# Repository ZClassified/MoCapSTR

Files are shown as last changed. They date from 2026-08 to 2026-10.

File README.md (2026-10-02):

# MoCapSTR: Sync / Trigger / Record for FreeMoCap










> [!CAUTION]
> ### ⚠️ Project Status: Experimental Prototype / Work in Progress
> **Please Note:** This project is currently undergoing active development and testing. It is **NOT YET in a state where it can be easily replicated as a turnkey / plug-and-play solution**. Hardware-level camera synchronization involves specific driver, USB controller bandwidth, and timing considerations. You may encounter issues depending on your hardware environment. Follow the issue tracker or discussions for ongoing updates.

> **Disclaimer:** MoCapSTR is an independent open-source companion tool and is not officially affiliated with the FreeMoCap project.

MoCapSTR is an open-source multi-camera recording tool designed to capture frame-accurate, hardware-synchronized video datasets for [FreeMoCap](https://github.com/freemocap/freemocap). It synchronizes global-shutter USB cameras (e.g. Innomaker OV9281, tested up to 50 FPS hardware-synced / 120 FPS free-run) via an Arduino trigger signal. Support for Blackmagic SDI capture cards is planned (see below).

> [!WARNING]
> **Blackmagic SDI mode is currently broken.** The "Blackmagic SDI" workflow in the Setup tab does not work since the switch to the PyAV backend. Its restoration (uncompressed or GPU-encoded recording, interlace/PsF detection, frame alignment without trigger) is planned for v2.0, once the webcam + Arduino base runs stable – see [BLACKMAGIC_SDI_PLAN.md](BLACKMAGIC_SDI_PLAN.md) (German).

---

## The Hardware Sync Challenge (USB Bandwidth)

Hardware-level synchronization has fundamentally different USB bandwidth requirements than standard webcam setups:

- **Free-Running Cameras (Standard Webcams / Standard FreeMoCap):** Cameras run on independent internal clocks. Their frames arrive staggered across time, so the data stream is naturally distributed.
- **Hardware-Triggered Mode (MoCapSTR):** An Arduino fires a 5V square-wave pulse to all cameras simultaneously. All connected cameras expose and push raw frame packets at the **exact same microsecond**.

### The Motherboard Bottleneck & Recommended Setup
Most standard PC motherboards share only 1 or 2 USB host controllers across all external USB ports:
- **Motherboard Limits:** In our testing, standard onboard USB controllers reliably handle a **maximum of 3 cameras** in hardware-trigger mode before bandwidth saturation causes dropped frames.
- **Recommended for 4+ Cameras (Verified Hardware):** We strongly recommend using a **PCIe USB expansion card with dedicated host controllers per port** (e.g. 4 separate USB controller chips on a single PCIe card) to ensure unconstrained bandwidth for all cameras.
  - **Tested & Verified Model:** **StarTech 4-Port USB 3.0 PCIe Card (Model: `P5Q4A-USB-CARD`)** — features 4 independent controller channels, reliably streaming 4 InnoMaker OV9281 cameras simultaneously without frame drops.
- **Smart USB Polling Rate:** In the Setup tab, `USB Polling` defaults to **`Auto`**. In Hardware Trigger mode, `Auto` requests a 120 FPS UVC stream to eliminate beat-frequency host polling jitter, while in Free-Run mode it matches your target FPS.

### InnoMaker OV9281 Hardware Trigger Characterization (Max 50 FPS)
Extensive empirical benchmark sweeping has characterized the InnoMaker OV9281 USB camera in hardware-trigger mode:
- **Free-Run Mode:** The camera sensor streams up to **120 FPS** (1280x720 / 1280x800 MJPG) via continuous internal pipelining.
- **Hardware-Trigger Mode:** The on-board USB bridge ISP firmware operates with a fixed non-overlapping state machine lockout window of **$\approx 18\text{–}20\text{ ms}$** per frame (regardless of resolution).
- **Physical Hardware Ceiling:** As a result, the physical hardware ceiling in trigger mode is strictly **50 FPS** (20 ms frame period). Triggering faster than 50 Hz causes the firmware to reject subsequent pulses, producing exact harmonic sub-rates (60 Hz $\rightarrow$ 30 FPS, 90 Hz $\rightarrow$ 45 FPS, 120 Hz $\rightarrow$ 40 FPS).
- **Optimal Setting for Motion Capture:** **1280x720 (720p HD) @ 50 FPS** with **`Auto` USB Polling** and **Exposure `-9` / `-10`** (~1–2 ms shutter). This delivers 200 frame-accurate, global-shutter synchronized images per second across 4 cameras without motion blur or frame drops.

<p align="center">
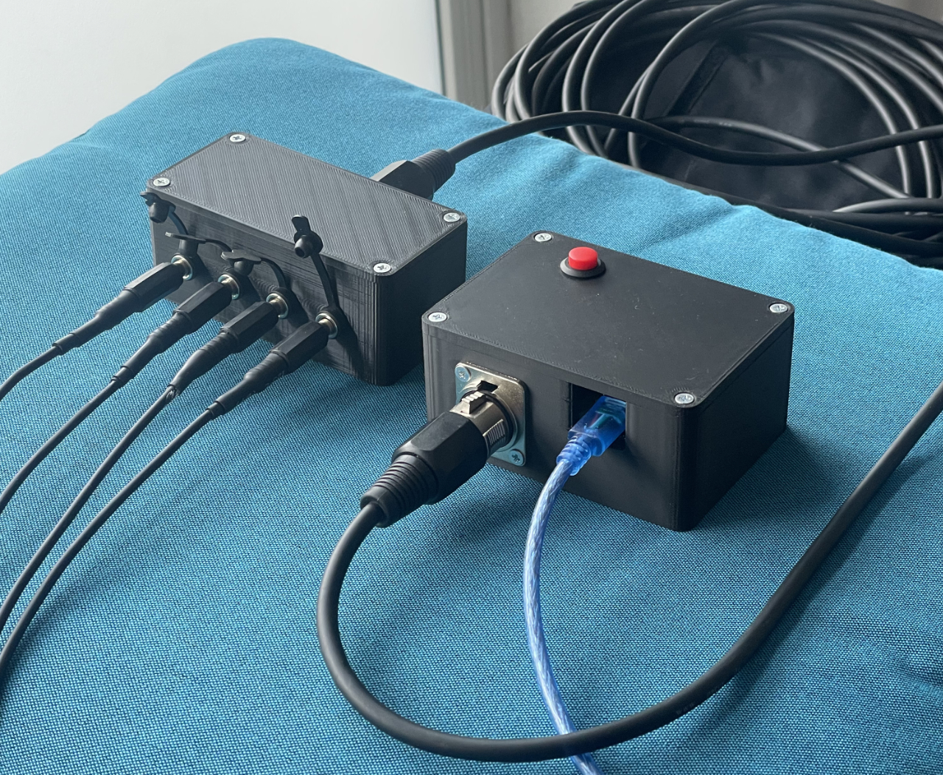
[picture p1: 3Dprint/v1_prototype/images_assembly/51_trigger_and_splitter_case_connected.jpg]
MoCapSTR Hardware Setup
  
  <br>
  <em>Arduino Trigger Box (with Start/Stop button) connected via XLR cable to the Splitter Box.</em>
</p>

---

## Features

- **Hardware Camera Synchronization:** Synchronous frame capture across all OV9281 cameras via Arduino FSIN pin (with auto-fallback to free-run mode if disconnected).
- **Zero-Copy PyAV Backend:** Writes raw MJPEG streams directly to disk via FFmpeg/PyAV without CPU decoding, minimizing frame drops.
- **Live Preview & Charuco Calibration:** Multi-camera live view with per-camera rotation (0°, 90°, 180°, 270°) and live `cv2.aruco` Charuco board detection overlay.
- **Records straight into FreeMoCap 2:** Every take and calibration is saved as its own recording in FreeMoCap's `recordings/` folder (`synchronized_videos/` + timestamps), with identical frame counts on all cameras. FreeMoCap 2 picks up the real frame rate from the timestamps.
- **Built-in Offline Converter:** Optional conversion of raw `.avi`/`.mkv` recordings into H.264 (`.mp4`) with per-camera rotation. FreeMoCap 2 also reads the raw files directly.
- **Hardware Diagnostics:** Built-in Camera Test tab to scan connected cameras for supported resolutions, framerates, and pixel formats.

---

## Quick Hardware Overview

1. **Wiring:**
   - Connect Arduino **GND** -> **GND** of all cameras.
   - Connect Arduino **Pin 2** -> **FSIN (Frame Sync In)** of all cameras.
   - *(Optional)* Connect physical Start/Stop push-button between Arduino **Pin 4** and **GND**.
2. **Guides & 3D Models:**
   - 3D printable files, fastener BOM, and step-by-step photo guide: [3Dprint & Assembly Guide](3Dprint/README.md).
   - Detailed wiring guide and splitter box schematic: [HARDWARE_SETUP.md](HARDWARE_SETUP.md).
   - Camera sensor specifications: [CAMERA_SPECS.md](CAMERA_SPECS.md).

---

## Installation

> **Pre-built Executable:** A ready-to-run `.exe` is available under [Releases](https://github.com/ZClassified/MoCapSTR/releases).

### Running from Source
- **Requirements:** Python 3.10+ (and [Blackmagic Desktop Video Drivers](https://www.blackmagicdesign.com/support/) for the planned SDI mode).

```bash
git clone https://github.com/ZClassified/MoCapSTR.git
cd MoCapSTR
pip install -r requirements.txt
python python/main.py
```
**Arduino firmware:** Connect the Arduino Nano/Uno, select its port in the Setup tab and click **Firmware aufspielen** – no Arduino IDE needed. The button turns orange when the firmware is missing or outdated (e.g. after updating MoCapSTR).
*(Alternatively flash `arduino/trigger_firmware/trigger_firmware.ino` with the Arduino IDE. After changing the sketch, rebuild the bundled HEX with `python arduino/build_firmware.py`.)*

**Running the tests** (no hardware needed; `pip install pandas` additionally enables the FreeMoCap compatibility test):
```bash
python -m unittest discover tests
```

**Settings & log files:** Settings, presets and the last session are stored in `%APPDATA%\MoCapSTR`. The log file is `%LOCALAPPDATA%\MoCapSTR\logs\mocapstr.log` – use **Log-Ordner öffnen** in the log panel and attach it to bug reports.

---

## Recording Workflow

1. **Setup Tab:** Choose a project name. Recordings are saved to FreeMoCap's recordings folder (`~/freemocap_data/recordings`, or the data folder chosen in FreeMoCap's settings). Select resolution, target FPS, and the Arduino COM port. Click **Initialize System & Start Preview**.
2. **Live Preview Tab:** Verify all camera feeds and rotations. Enable **Show Calibration (Auto-Detect)** when recording a Charuco calibration take.
3. **Record:** Start/Stop recording via the UI button or the physical button on the trigger box.
4. **Export & Convert Tab (optional):** Convert raw takes to H.264 (`.mp4`), e.g. to apply camera rotation. Originals are moved to `original_videos/` so FreeMoCap sees exactly one video per camera.
5. **FreeMoCap 2:** Click **Open in FreeMoCap** (or start FreeMoCap yourself). Recordings are named `<date>_<time>_<project>_<take>`; calibration recordings end in `_calibration`.

---

## Troubleshooting & FAQ

### Camera shows `0.0 FPS` or a Frozen Image (`⚠️ NO SIGNAL / FROZEN`)
- **Symptom:** When clicking "Initialize System", one or more camera feeds show an initial frame and immediately freeze at `0.0 FPS` with a red warning overlay.
- **Root Cause:** The camera has switched to Hardware Trigger mode (`AutoFocus=1`) and is waiting for electrical pulses on its `FSIN` pin. If no trigger pulse or ground reaches the camera, the sensor produces zero further frames.
- **Step-by-Step Diagnostic:**
  1. **Quick Software Isolation (Free-Run Test):** In the **Setup** tab, uncheck `Enable UVC Hardware Trigger` and click **Initialize System**. If all cameras stream smoothly at 30/60 FPS in Free-Run mode, your USB card, bandwidth, and software are 100% working — the issue is **strictly the physical hardware trigger connection**.
  2. **Check Splitter Box Wiring:** Open the splitter box and ensure all WAGO cage clamp terminals and DC jack solder joints are firm and not disconnected.
  3. **Check `FSIN+` / `FSIN-` Polarity:** Ensure the 2-pin plug on the camera PCB is oriented correctly (Red = `FSIN+`, Black = `FSIN-` / Ground). If polarity is reversed, the camera's internal diode blocks the trigger pulses.
  4. **Cross-Test Cables:** Swap the DC barrel jack of the frozen camera with a working camera at the splitter box to isolate whether the cable or splitter port is faulty.

---

## License

GPL-3.0 License. See [LICENSE](LICENSE) for details.

---
---

# Deutsche Version

> **Hinweis:** MoCapSTR ist ein unabhängiges Open-Source Companion-Tool und steht nicht in offizieller Verbindung mit dem FreeMoCap-Projekt.

MoCapSTR ist eine Multi-Kamera-Aufnahmesoftware zur Erstellung synchroner, frame-genauer Datensätze für [FreeMoCap](https://github.com/freemocap/freemocap). Sie synchronisiert Global-Shutter USB-Kameras (z. B. Innomaker OV9281, getestet bis 50 FPS Hardware-Sync / 120 FPS Free-Run) über ein Arduino-Triggersignal. Unterstützung für Blackmagic SDI Capture Cards ist geplant (siehe unten).

> [!WARNING]
> **Der Blackmagic-SDI-Modus ist aktuell nicht funktionsfähig.** Der Workflow "Blackmagic SDI" im Setup-Tab funktioniert seit der Umstellung auf das PyAV-Backend nicht mehr. Die Instandsetzung (unkomprimierte oder GPU-kodierte Aufnahme, Interlace/PsF-Erkennung, Frame-Ausrichtung ohne Trigger) ist für v2.0 geplant, sobald die Basis mit Webcams und Arduino stabil läuft – siehe [BLACKMAGIC_SDI_PLAN.md](BLACKMAGIC_SDI_PLAN.md).

> [!WARNING]
> **Projektstatus (Beta / Prototyp):**
> Diese Software ist ein aktives Open-Source-Projekt im Prototypen-Stadium. Es können Fehler, Hardware-Inkompatibilitäten oder unerwartetes Verhalten auftreten. Feedback, Bug-Reports und Mithilfe sind über [GitHub Issues](https://github.com/ZClassified/MoCapSTR/issues) ausdrücklich willkommen!

---

## Die Herausforderung bei Hardware-Sync (USB-Bandbreite)

Hardware-Synchronisation stellt völlig andere Anforderungen an den USB-Bus als normale Webcams:

- **Free-Run Modus (Normale Webcams / Standard FreeMoCap):** Jede Kamera läuft auf ihrem eigenen internen Takt. Die Bildübertragungen treffen zeitlich leicht versetzt ein, wodurch sich die USB-Bandbreite natürlich verteilt.
- **Hardware-Trigger Modus (MoCapSTR):** Der Arduino sendet einen 5V-Rechteckimpuls zeitgleich an alle Kameras. Alle Kameras belichten und senden ihre JPEG-Datenpakete in der **exakt selben Mikrosekunde**.

### Der Mainboard-Flaschenhals & Hardware-Empfehlung
Auf herkömmlichen PC-Mainboards teilen sich fast alle USB-Ports nur 1 bis 2 interne USB-Host-Controller:
- **Mainboard-Limit:** In Praxistests schaffen normale Onboard-Controller im Hardware-Trigger-Modus **maximal 3 Kameras** zuverlässig. Bei 4 Kameras kommt es zu Bandbreiten-Staus und Frame-Drops.
- **Empfehlung für 4+ Kameras (Verifizierte Hardware):** Eine **PCIe-USB-Erweiterungskarte mit je einem dedizierten USB-Controller-Chip pro Port** (z. B. 4 getrennte Controller auf einer Karte) wird dringend empfohlen.
  - **Getestetes & verifiziertes Modell:** **StarTech 4-Port USB 3.0 PCIe-Karte (Modell: `P5Q4A-USB-CARD`)** — verfügt über 4 getrennte USB-Host-Controller und betreibt 4 InnoMaker OV9281 Kameras absolut reibungslos ohne Frame-Drops.
- **Intelligentes USB-Polling:** Im Setup-Tab steht `USB Polling` standardmäßig auf **`Auto`**. Im Hardware-Trigger-Modus fordert `Auto` automatisch einen 120-FPS-UVC-Stream an, um Phasen-Schwebungen (Jitter) zu eliminieren. Im Free-Run-Modus passt es sich der Ziel-FPS an.

### InnoMaker OV9281 Hardware-Trigger Charakterisierung (Max. 50 FPS)
Umfassende Benchmark-Messreihen haben das Verhalten der InnoMaker OV9281 USB-Kameras im Trigger-Modus eindeutig charakterisiert:
- **Free-Run Modus:** Der Sensor streamt via Pipelining problemlos mit bis zu **120 FPS** (1280x720 / 1280x800 MJPG).
- **Hardware-Trigger Modus:** Der interne Firmware-Zustandsautomat des USB-Bridge-Controllers (ISP) besitzt pro Frame ein festes Auslese- und Freischaltfenster (*Lockout*) von **$\approx 18\text{–}20\text{ ms}$** (unabhängig von der gewählten Auflösung).
- **Physikalisches Hardware-Limit:** Im Trigger-Modus liegt die maximale Obergrenze daher stabil bei **50 FPS** (20 ms Periodendauer). Bei Triggerraten über 50 Hz werden nachfolgende Pulse vom Sensor verworfen, wodurch sich exakte sub-harmonische Raten ergeben (60 Hz $\rightarrow$ 30 FPS, 90 Hz $\rightarrow$ 45 FPS, 120 Hz $\rightarrow$ 40 FPS).
- **Optimale Einstellung für Motion Capture:** **1280x720 (720p HD) @ 50 FPS** mit **`Auto` USB-Polling** und **Belichtung `-9` / `-10`** (~1–2 ms Verschlusszeit). Dies liefert 200 gestochen scharfe, mikrosekundengenau synchrone Bilder pro Sekunde über alle 4 Kameras ohne Motion Blur oder Frame-Drops.

<p align="center">
  MoCapSTR Hardware Setup
  <br>
  <em>Arduino Trigger-Box (mit Start/Stop-Taster) über XLR-Kabel mit der Splitter-Box verbunden.</em>
</p>

---

## Features

- **Hardware-Kamera-Synchronisation:** Zeitgleiche Auslösung aller OV9281-Kameras über den Arduino FSIN-Pin (automatischer Fallback auf Free-Run bei getrenntem Arduino).
- **Zero-Copy PyAV Backend:** Schreibt rohe MJPEG-Streams via FFmpeg/PyAV ohne CPU-Decodierung direkt auf die Festplatte, um Frame-Drops zu vermeiden.
- **Live Preview mit Charuco-Erkennung:** Multi-Kamera-Vorschau mit individueller Bildrotation (0°, 90°, 180°, 270°) und zuschaltbarem `cv2.aruco` Charuco-Erkennungs-Overlay.
- **Nimmt direkt für FreeMoCap 2 auf:** Jede Aufnahme und jede Kalibrierung wird als eigene Recording im `recordings/`-Ordner von FreeMoCap gespeichert (`synchronized_videos/` + Zeitstempel), mit identischer Frame-Anzahl über alle Kameras. FreeMoCap 2 übernimmt die echte Bildrate aus den Zeitstempeln.
- **Integrierter Offline-Konverter:** Optionale Umwandlung von `.avi`/`.mkv`-Aufnahmen in H.264 (`.mp4`) mit Rotation pro Kamera. FreeMoCap 2 liest die Rohdateien auch direkt.
- **Hardware-Diagnose:** Kamera-Test-Tab zum automatischen Prüfen aller unterstützten Auflösungen, Frameraten und Formate verbundener Kameras.

---

## Schnellanleitung Hardware

1. **Verkabelung:**
   - Arduino **GND** -> **GND** aller Kameras.
   - Arduino **Pin 2** -> **FSIN** aller Kameras.
   - *(Optional)* Physischer Start/Stop-Taster zwischen Arduino **Pin 4** und **GND**.
2. **Anleitungen & 3D-Druck:**
   - Druckdateien, Stückliste und Foto-Montageanleitung: [3D-Druck- & Montage-Guide](3Dprint/README.md).
   - Detaillierte Verkabelung und Splitter-Box: [HARDWARE_SETUP.md](HARDWARE_SETUP.md).
   - Kameraspezifikationen: [CAMERA_SPECS.md](CAMERA_SPECS.md).

---

## Installation

> **Fertige EXE:** Eine ausführbare Windows-Datei (`.exe`) steht unter [Releases](https://github.com/ZClassified/MoCapSTR/releases) zum Download bereit.

### Start aus dem Quellcode
- **Voraussetzungen:** Python 3.10+ (und [Blackmagic Desktop Video Treiber](https://www.blackmagicdesign.com/support/) für den geplanten SDI-Modus).

```bash
git clone https://github.com/ZClassified/MoCapSTR.git
cd MoCapSTR
pip install -r requirements.txt
python python/main.py
```
**Arduino-Firmware:** Arduino Nano/Uno anschließen, im Setup-Tab den Port wählen und auf **Firmware aufspielen** klicken – keine Arduino IDE nötig. Der Button wird orange, wenn die Firmware fehlt oder veraltet ist (z. B. nach einem MoCapSTR-Update).
*(Alternativ `arduino/trigger_firmware/trigger_firmware.ino` über die Arduino IDE flashen. Nach Änderungen am Sketch die mitgelieferte HEX-Datei mit `python arduino/build_firmware.py` neu bauen.)*

**Tests ausführen** (ohne Hardware; mit `pip install pandas` läuft zusätzlich der FreeMoCap-Kompatibilitätstest):
```bash
python -m unittest discover tests
```

**Einstellungen & Log-Dateien:** Einstellungen, Presets und die letzte Sitzung liegen in `%APPDATA%\MoCapSTR`. Die Log-Datei ist `%LOCALAPPDATA%\MoCapSTR\logs\mocapstr.log` – über **Log-Ordner öffnen** im Log-Bereich erreichbar, bitte bei Fehlermeldungen mitschicken.

---

## Aufnahme-Workflow

1. **Setup Tab:** Projektnamen wählen. Aufnahmen landen im Recordings-Ordner von FreeMoCap (`~/freemocap_data/recordings` bzw. der in FreeMoCap eingestellte Datenordner). Auflösung, Ziel-FPS und Arduino COM-Port einstellen. Auf **Initialize System & Start Preview** klicken.
2. **Live Preview Tab:** Kamera-Feeds und Rotation prüfen. Bei der Kalibrierungsaufnahme **Show Calibration (Auto-Detect)** aktivieren.
3. **Aufnahme:** Aufnahme über den Software-Button oder den physischen Taster an der Trigger-Box starten/stoppen.
4. **Export & Convert Tab (optional):** Aufnahmen in H.264 (`.mp4`) umwandeln, z. B. um die Kamera-Rotation anzuwenden. Die Originale werden nach `original_videos/` verschoben, damit FreeMoCap genau ein Video pro Kamera sieht.
5. **FreeMoCap 2:** Auf **Open in FreeMoCap** klicken (oder FreeMoCap selbst starten). Aufnahmen heißen `<Datum>_<Uhrzeit>_<Projekt>_<Take>`, Kalibrierungen enden auf `_calibration`.

---

## Fehlerbehebung & Häufige Probleme (Troubleshooting)

### Kamera zeigt `0.0 FPS` oder ein eingefrorenes Bild (`⚠️ NO SIGNAL / FROZEN`)
- **Symptom:** Nach dem Klick auf "Initialize System" zeigt eine Kamera nur ein einzelnes Standbild und bleibt mit einem roten Warn-Overlay bei `0.0 FPS` stehen (oder alle Kameras bleiben stehen).
- **Ursache:** Die Kamera ist im Hardware-Trigger-Modus (`AutoFocus=1`) und wartet auf externe 5V-Taktsignale am `FSIN`-Pin. Wenn kein Signal oder keine Masse ankommt, liefert der Sensor keine weiteren Frames.
- **Lösungsschritte zur Fehlersuche:**
  1. **Schnelltest im Free-Run-Modus:** Deaktiviere im Tab **„1. Project & Setup“** das Häkchen `[ ] Enable UVC Hardware Trigger` und klicke auf Initialisieren. Laufen alle Kameras im Free-Run flüssig mit ~30 FPS, sind USB-Karte, Treiber und Software zu 100 % in Ordnung – der Fehler liegt **ausschließlich an der physischen Trigger-Leitung**.
  2. **Splitter-Box Verkabelung prüfen:** Prüfe, ob in der Splitter-Box eine Klemme (WAGO) lose ist oder ein Kabel an einer DC-Buchse abgegangen ist.
  3. **Polarität an der Kamera prüfen (`FSIN+` / `FSIN-`):** Prüfe, ob der 2-Pin JST-Stecker richtig herum aufgesteckt ist (Rot = `FSIN+`, Schwarz = `FSIN-`). Bei vertauschten Adern sperrt die sensorinterne Schutzdiode das Triggersignal.
  4. **Kreuztest durchführen:** Stecke den DC-Stecker der betroffenen Kamera an der Splitter-Box in einen funktionierenden Port um, um Kabel- vs. Buchsendefekte zu isolieren.

---

## Lizenz

GPL-3.0 Lizenz. Siehe [LICENSE](LICENSE) für Details.

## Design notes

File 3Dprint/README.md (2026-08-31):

# 3D Printing & Enclosure Assembly Guide (V1 Prototype)

This directory contains CAD source files (FreeCAD `.FCStd`), 3D-printable STL files (`.stl`), render previews, and real-world step-by-step assembly photos for the MoCapSTR hardware components.

---

## Quick Navigation

- [Hardware Bill of Materials (BOM)](#hardware-bill-of-materials-bom)
- [Complete System Interconnect](#complete-system-interconnect)
- [CAD & STL Components Overview](#cad--stl-components-overview)
- [Step-by-Step Assembly Guide](#step-by-step-assembly-guide)
  - [1. Arduino Trigger Box](#1-arduino-trigger-box-assembly)
  - [2. XLR Splitter Box](#2-xlr-splitter-box-assembly)
  - [3. Innomaker OV9281 Camera Enclosure](#3-innomaker-ov9281-camera-enclosure-assembly)
- [Print Recommendations & Technical Notes](#print-recommendations--technical-notes)
- [Deutsche Version (Hier klicken)](#deutsche-version)

---

## Complete System Interconnect

<p align="center">
  Complete Trigger and Splitter System Connected
  <br>
  <em>Arduino Trigger Box (right, with blue USB cable to PC) connected via standard XLR cable to the Splitter Box (left, distributing to 4 camera DC cables).</em>
</p>

---

## Hardware Bill of Materials (BOM)

| Subassembly | 3D Printed Parts | Electronics & Hardware | Fasteners & Inserts |
| :--- | :--- | :--- | :--- |
| **OV9281 Camera Enclosure**<br>*(per camera)* | - 1x `Cam-FRONT`<br>- 1x `Cam-MID`<br>- 1x `Cam-BACK-SHORT` *(or LONG)*<br>- 1x `Cam-BRACKET` | - 1x Innomaker OV9281 USB camera PCB + lens *(Tested: up to 120 FPS in free-run, strictly max 50 FPS in hardware-trigger mode due to bridge firmware)*<br>- 1x 2-Pin Micro Plug (e.g. JST 1.25mm 2-pin) for FSIN header | - **9x** M3 brass heat-set inserts<br>- **7x** M3 15mm screws (3x Front/Mid, 4x Mid/Back)<br>- **2x** M3 thumbscrews (10–25mm) or standard M3 screws for bracket |
| **Arduino Trigger Box** | - 1x `Trigger_Case-BASE`<br>- 1x `Trigger_Case-LID` | - 1x Arduino Nano<br>- 1x Terminal Block Shield Adapter<br>- 1x Neutrik XLR Chassis (Male, D-Series)<br>- 1x 12mm Push-Button (NO)<br>- *(Optional)* 1x DC Barrel Jack (8mm) | - **8x** M3 brass heat-set inserts<br>- **8x** M3 10mm screws (4x Lid, 2x XLR, 2x Shield) |
| **XLR Splitter Box** | - 1x `Splitter_Case-BASE`<br>- 1x `Splitter_Case-LID` | - 1x Neutrik XLR Chassis (Female, D-Series)<br>- 4x DC Barrel Jacks (8mm)<br>- 2x 5-pin Cage Clamp Terminals (WAGO) | - **6x** M3 brass heat-set inserts<br>- **6x** M3 10mm screws (4x Lid, 2x XLR) |

---

## CAD & STL Components Overview

### 1. Arduino Trigger Box (`Trigger_Case`)

| Component / File | Preview | Description |
| :--- | :---: | :--- |
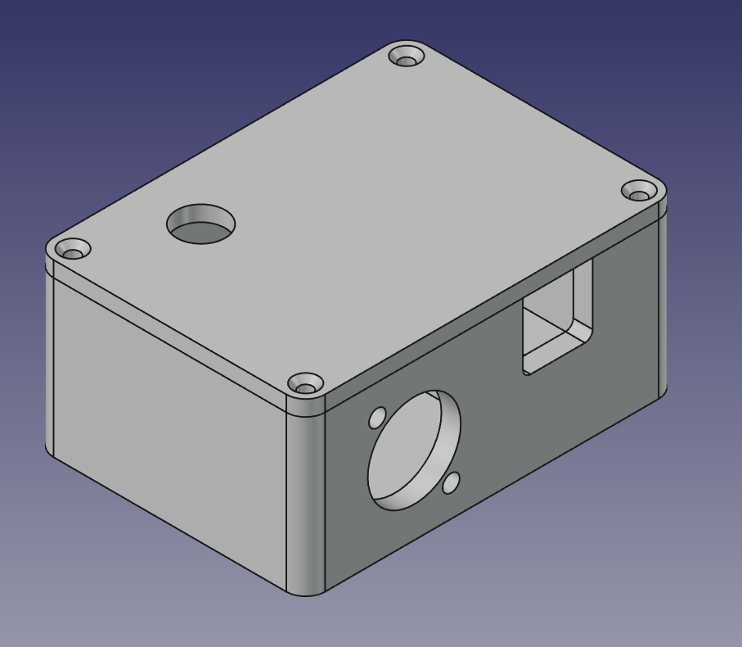
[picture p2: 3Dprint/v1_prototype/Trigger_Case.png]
Trigger Case Complete
| **Complete Assembly**<br>[`v1_prototype/Trigger_Case.FCStd`](v1_prototype/Trigger_Case.FCStd) |  | Full assembly CAD project. Push-button mount is in the top lid. |
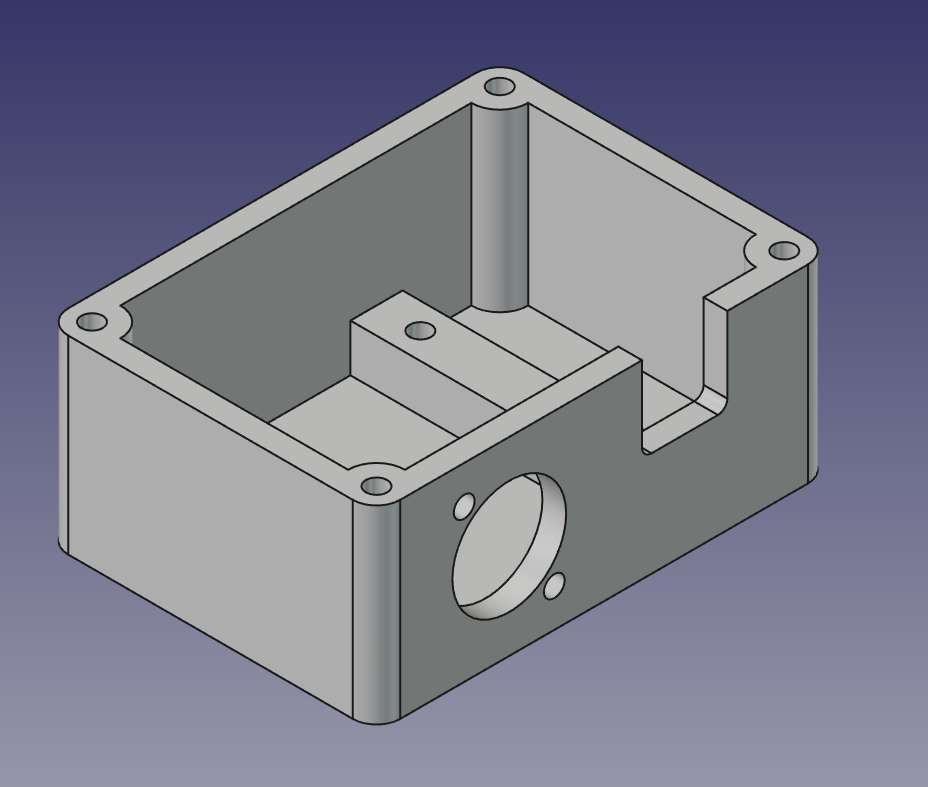
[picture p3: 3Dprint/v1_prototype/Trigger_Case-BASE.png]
Trigger Case Base
| **Base Enclosure**<br>[`v1_prototype/Trigger_Case-BASE.stl`](v1_prototype/Trigger_Case-BASE.stl) |  | Houses the Arduino Nano with Terminal Block shield, male XLR connector, and optional DC jack. |
| **Top Lid**<br>[`v1_prototype/Trigger_Case-LID.stl`](v1_prototype/Trigger_Case-LID.stl) | *(See complete assembly)* | Top lid with **12mm mounting hole for the Start/Stop trigger push-button**. |

---

### 2. XLR Splitter Box (`Splitter_Case`)

| Component / File | Preview 1 | Preview 2 | Description |
| :--- | :---: | :---: | :--- |
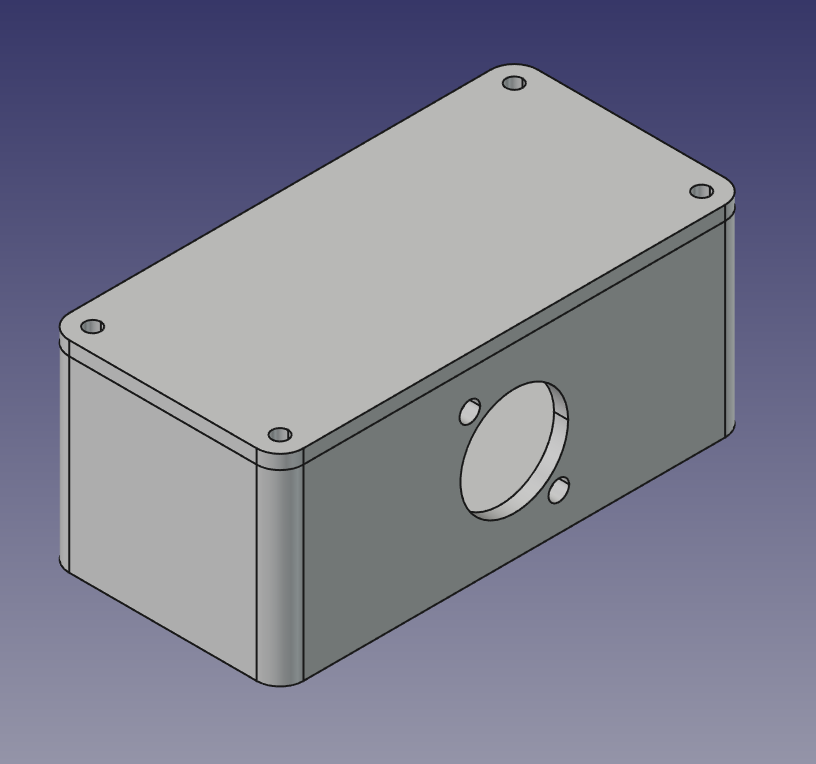
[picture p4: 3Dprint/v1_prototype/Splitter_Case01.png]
Splitter Case View 1
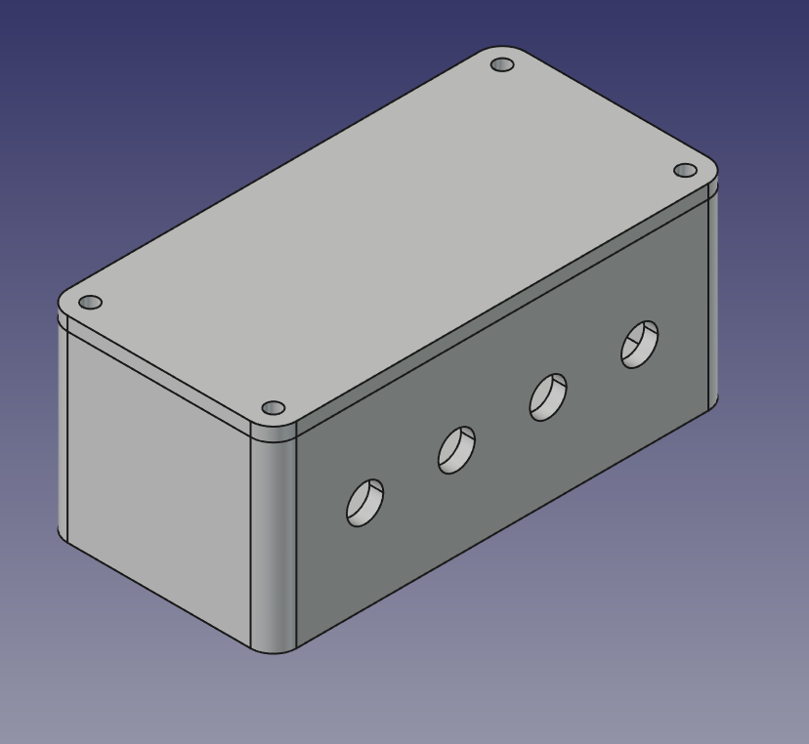
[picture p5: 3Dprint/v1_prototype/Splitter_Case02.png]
Splitter Case View 2
| **Complete Assembly**<br>[`v1_prototype/Splitter_Case.FCStd`](v1_prototype/Splitter_Case.FCStd)<br>[`v1_prototype/Splitter_Case-BASE.stl`](v1_prototype/Splitter_Case-BASE.stl)<br>[`v1_prototype/Splitter_Case-LID.stl`](v1_prototype/Splitter_Case-LID.stl) |  |  | Distributor box with mount for 1x female Neutrik XLR D-series socket and **4x mounting holes for DC barrel jacks** (8mm). |

---

### 3. OV9281 Camera Enclosure (`OV9281_Case`)

<p align="center">
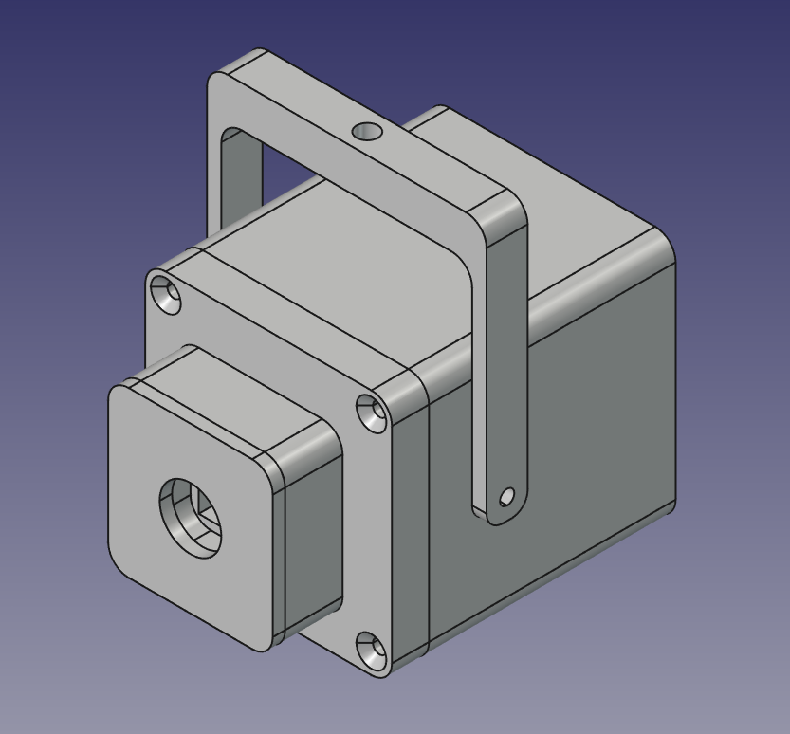
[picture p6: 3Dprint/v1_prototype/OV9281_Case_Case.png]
OV9281 Camera Case Assembly
  
  <br>
  <em>Complete OV9281 Modular Enclosure Assembly</em>
</p>

| Part | File | Preview | Description |
| :--- | :--- | :---: | :--- |
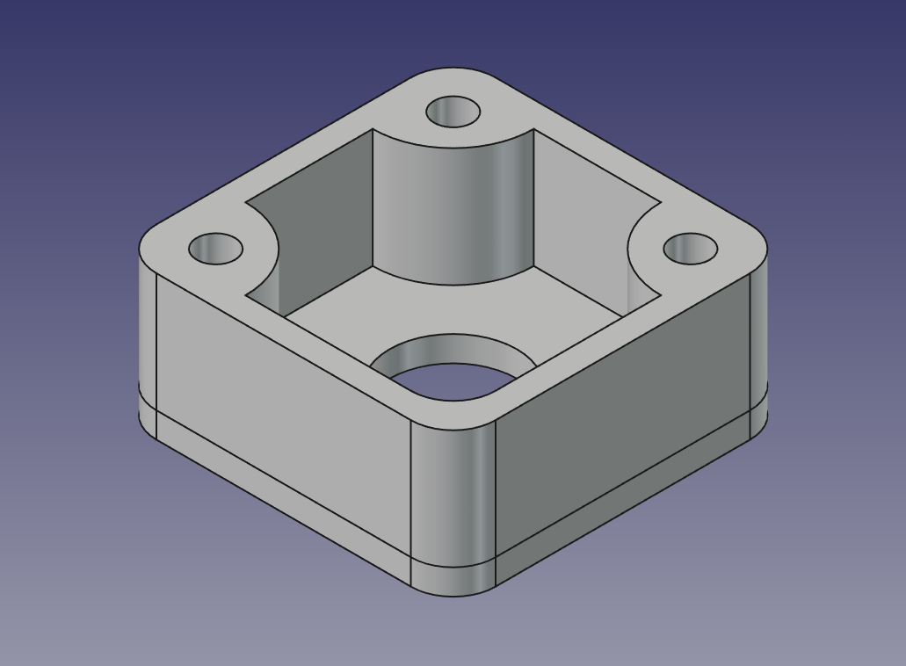
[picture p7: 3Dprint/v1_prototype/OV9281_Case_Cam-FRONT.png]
Cam Front
| **Front Bezel** | [`v1_prototype/OV9281_Case_Cam-FRONT.stl`](v1_prototype/OV9281_Case_Cam-FRONT.stl) |  | Front bezel surrounding the M12/CS lens mount (holds 3x heat-set inserts). |
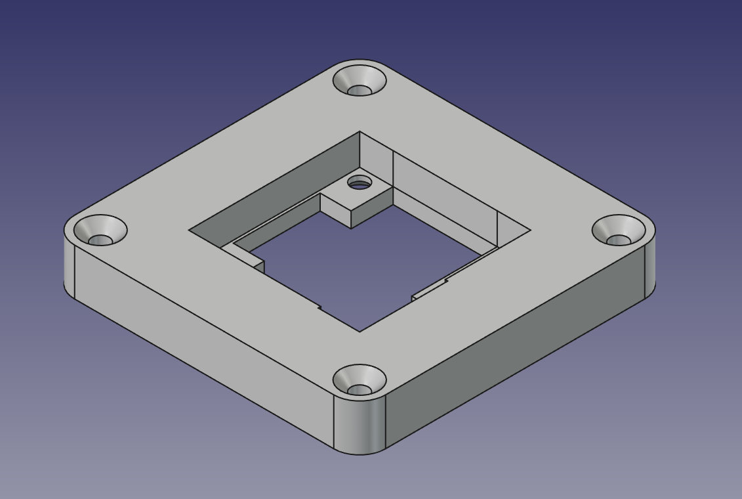
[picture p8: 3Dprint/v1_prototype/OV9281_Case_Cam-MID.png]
Cam Mid
| **Middle Frame** | [`v1_prototype/OV9281_Case_Cam-MID.stl`](v1_prototype/OV9281_Case_Cam-MID.stl) |  | **PCB Backing Frame:** Sandwiches and locks the camera PCB against the front bezel with 3x M3 15mm screws. |
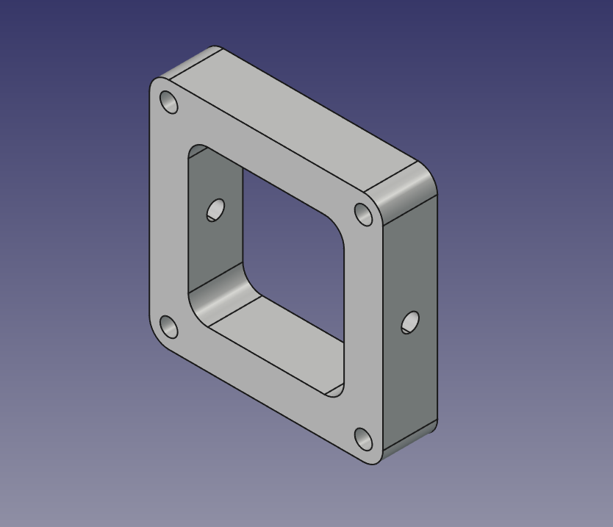
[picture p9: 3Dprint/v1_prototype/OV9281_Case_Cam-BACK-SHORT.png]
Cam Back Short
| **Back Cover (Short)** | [`v1_prototype/OV9281_Case_Cam-BACK-SHORT.stl`](v1_prototype/OV9281_Case_Cam-BACK-SHORT.stl) |  | **Open back design:** Direct access to plug cables straight onto the camera pin headers. |
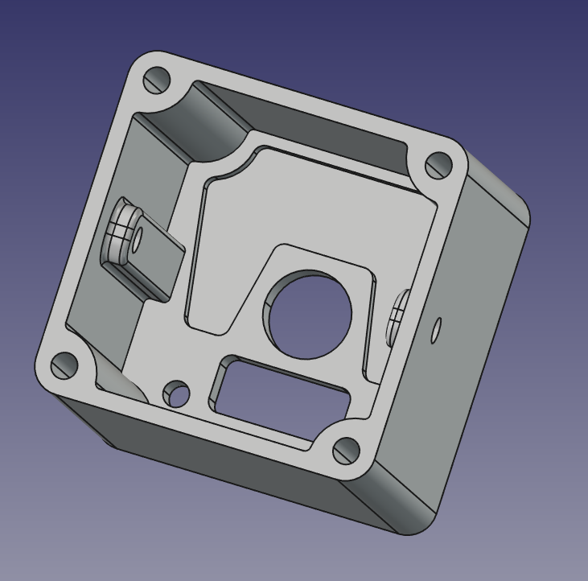
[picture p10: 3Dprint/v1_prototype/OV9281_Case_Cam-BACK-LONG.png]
Cam Back Long
| **Back Cover (Long)** | [`v1_prototype/OV9281_Case_Cam-BACK-LONG.stl`](v1_prototype/OV9281_Case_Cam-BACK-LONG.stl) |  | **Fully enclosed design:** Extended enclosure with a rear hole for a **cable strain relief** and cutout for a **speaker spring terminal clip**. |
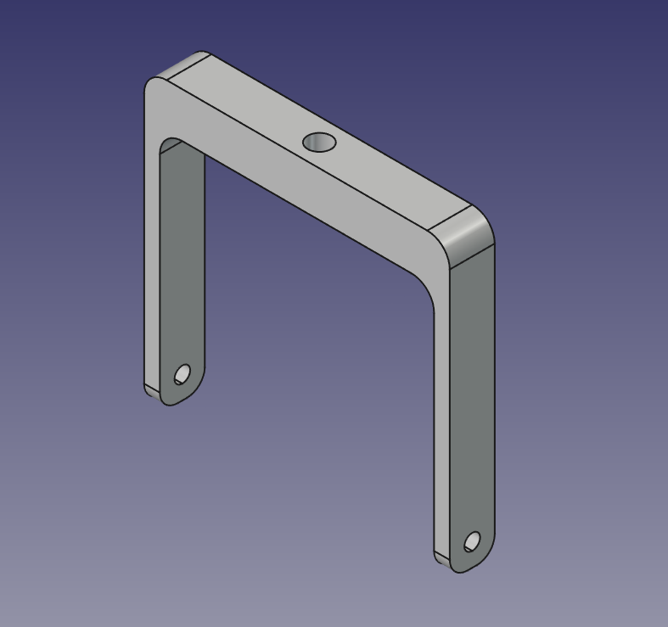
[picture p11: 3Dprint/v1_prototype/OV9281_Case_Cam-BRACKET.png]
Cam Bracket
| **Mounting Bracket** | [`v1_prototype/OV9281_Case_Cam-BRACKET.stl`](v1_prototype/OV9281_Case_Cam-BRACKET.stl) |  | Tripod / rig bracket with a pilot hole for tapping a **1/4"-20 UNC standard tripod thread**. |

---

## Step-by-Step Assembly Guide

### 1. Arduino Trigger Box Assembly

<p align="center">
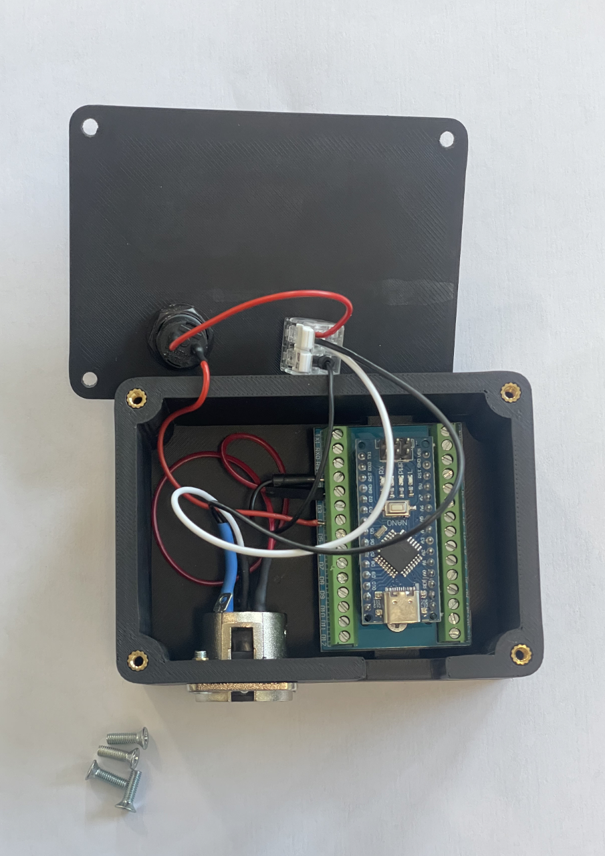
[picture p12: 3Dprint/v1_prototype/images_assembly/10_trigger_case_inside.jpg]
Trigger Case Internal Wiring
  
  &nbsp;&nbsp;&nbsp;&nbsp;
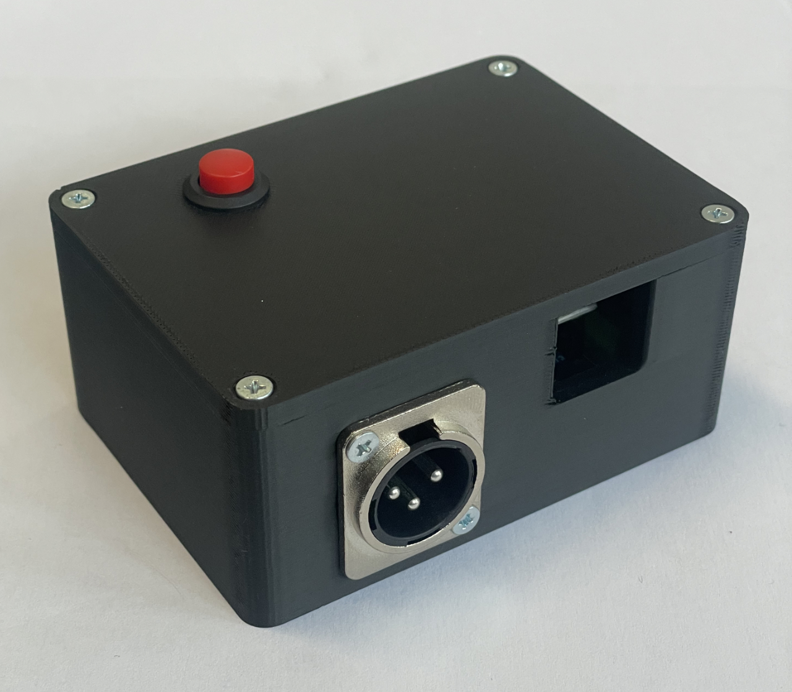
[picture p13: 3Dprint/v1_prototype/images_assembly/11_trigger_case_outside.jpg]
Trigger Case Assembled
  
</p>

1. **Threaded Inserts:** Melt 8x M3 heat-set inserts into the base (4 for lid corners, 2 for XLR chassis, 2 for Arduino shield mount).
2. **Mount Hardware:** Screw in the male Neutrik XLR connector and secure the Arduino Terminal Shield into the base.
3. **Internal Wiring:**
   - Connect **XLR Pin 1** (Ground/Shield) to Arduino **GND**.
   - Connect **XLR Pin 2** (Signal Hot) to Arduino **Pin 2**.
   - Bridge **XLR Pin 3** with **XLR Pin 1** (GND).
4. **Push-Button:** Mount the 12mm push button into the lid. Connect its two wires between Arduino **Pin 4** and Arduino **GND** (utilizes internal `INPUT_PULLUP`). A small 2-pin clamp or connector makes closing the lid convenient.
5. **Close Enclosure:** Fasten the lid with 4x M3 10mm screws.

---

### 2. XLR Splitter Box Assembly

<p align="center">
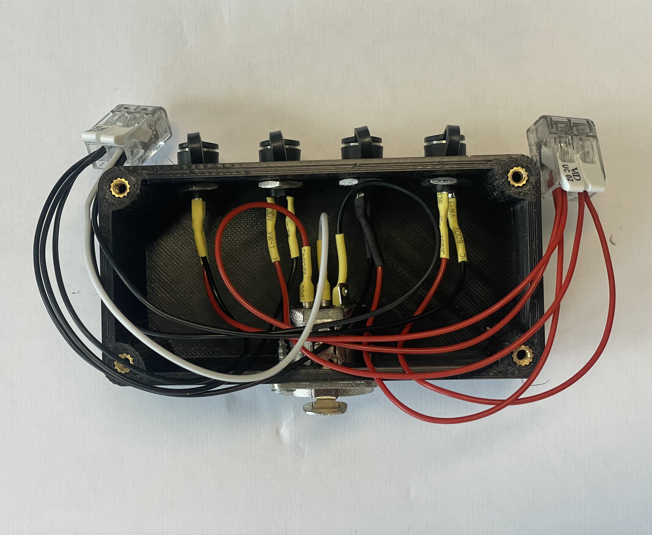
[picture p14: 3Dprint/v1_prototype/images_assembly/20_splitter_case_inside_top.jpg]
Splitter Case Internal Wiring
  
  &nbsp;&nbsp;&nbsp;&nbsp;
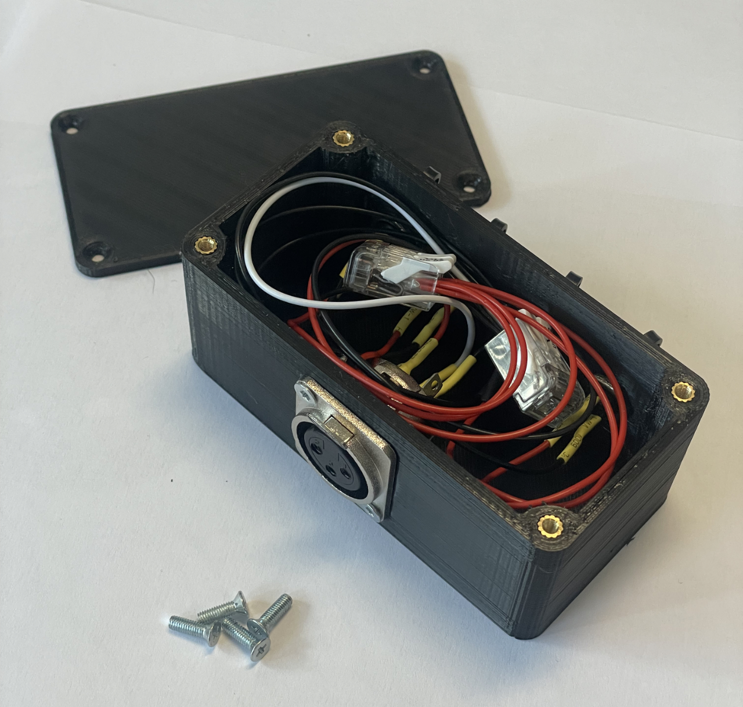
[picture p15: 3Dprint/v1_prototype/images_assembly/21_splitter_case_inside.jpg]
Splitter Case Assembly Perspective
  
</p>
<p align="center">
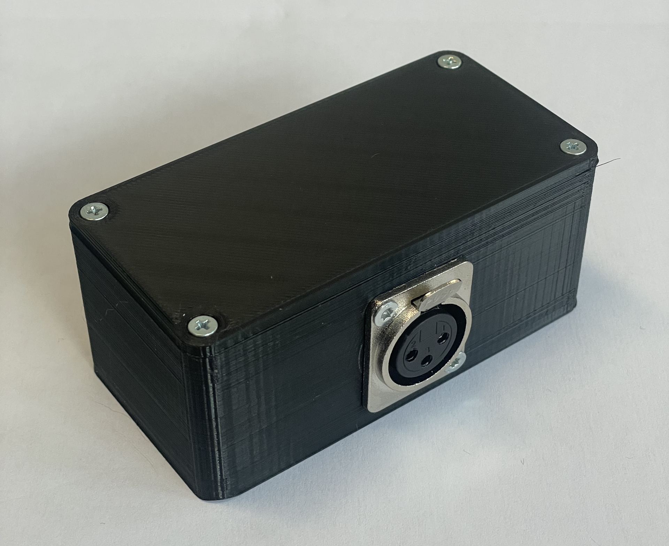
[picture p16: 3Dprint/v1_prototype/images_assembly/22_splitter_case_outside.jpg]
Splitter Case Front View
  
  &nbsp;&nbsp;&nbsp;&nbsp;
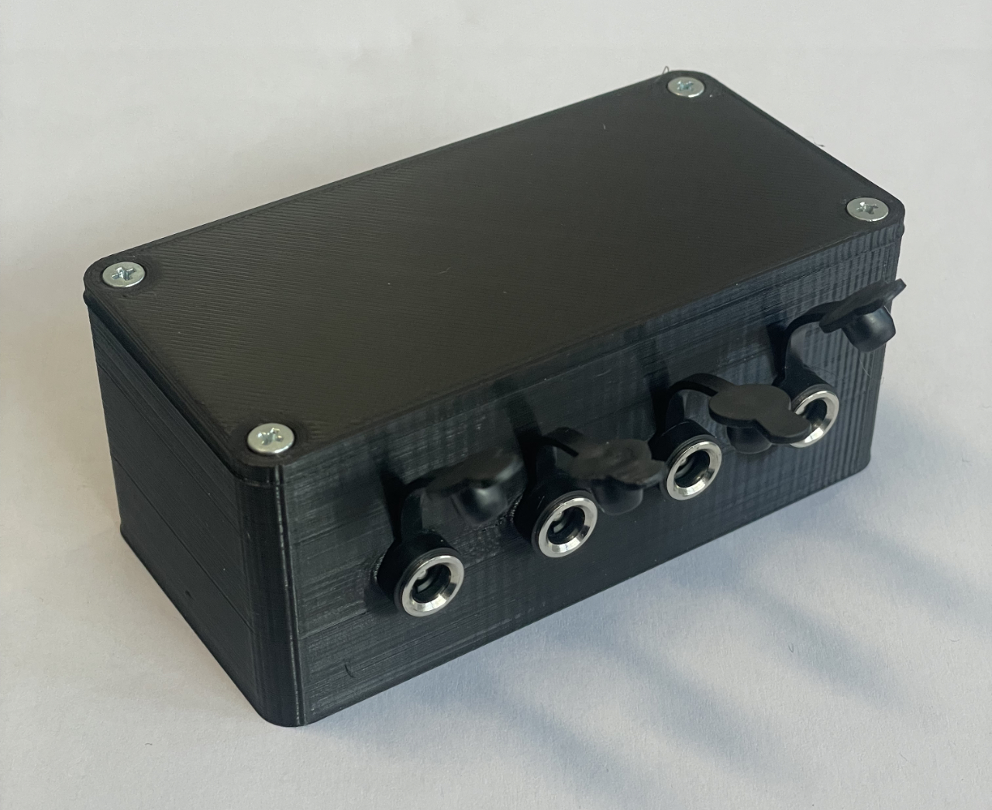
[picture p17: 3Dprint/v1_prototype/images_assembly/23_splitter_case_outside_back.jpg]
Splitter Case Back View with DC Jacks
  
</p>

1. **Threaded Inserts:** Melt 6x M3 heat-set inserts into the base (4 for lid corners, 2 for XLR chassis).
2. **Mount Sockets:** Screw the female Neutrik XLR chassis socket into the front, and install the 4x DC barrel jacks into the rear holes.
3. **Wiring with Cage Clamp Terminals (WAGO):**
   - **Signal (Hot):** Run a wire from **XLR Pin 2** into the first 5-pin clamp. Connect the 4 positive/center leads of the DC barrel jacks to this clamp.
   - **Ground & Shield (GND):** Run a wire from **XLR Pin 1** into the second 5-pin clamp. Connect all 4 ground/outer leads of the DC barrel jacks to this clamp.
   - *(XLR Pin 3 can be bridged to Pin 1 or left open).*
4. **Close Enclosure:** Tuck the wires neatly into the case and secure the lid with 4x M3 10mm screws.

---

### 3. Innomaker OV9281 Camera Enclosure Assembly

#### Step 1: Parts Preparation & Heat-Set Inserts
<p align="center">
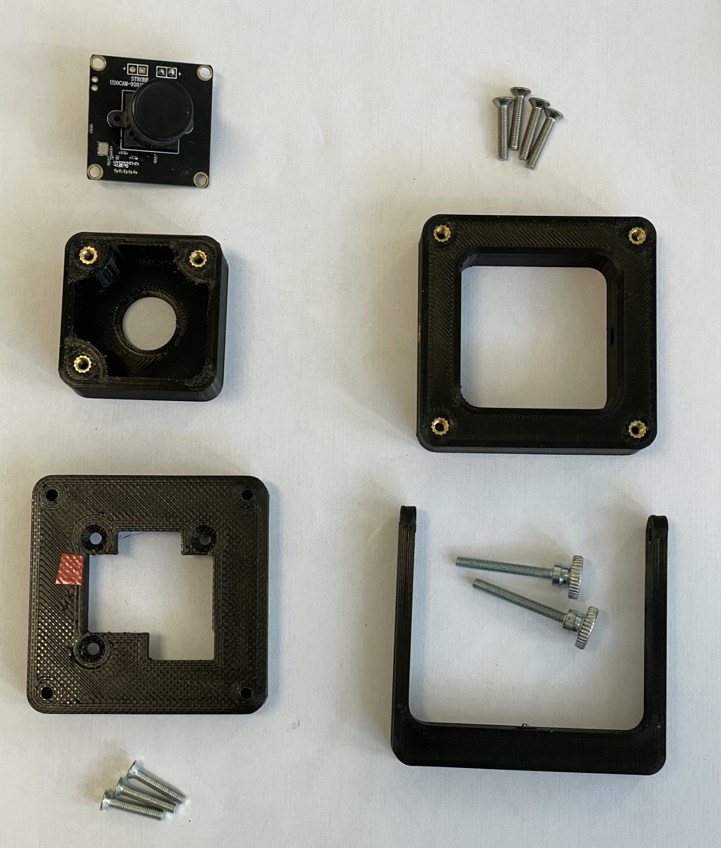
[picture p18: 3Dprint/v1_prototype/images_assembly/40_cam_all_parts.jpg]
Camera Assembly Parts Overview
  
</p>

- Melt **3x M3 inserts** into the inner pillars of `Cam-FRONT`.
- Melt **4x M3 inserts** into the 4 corners of `Cam-MID`.
- Melt **2x M3 inserts** into the side mounting holes of `Cam-BACK-SHORT` (for the bracket).
- Tap the center hole of `Cam-BRACKET` with a **1/4"-20 UNC hand tap** for tripod mounting.

---

#### Step 2: Place Camera PCB into Front Bezel
<p align="center">
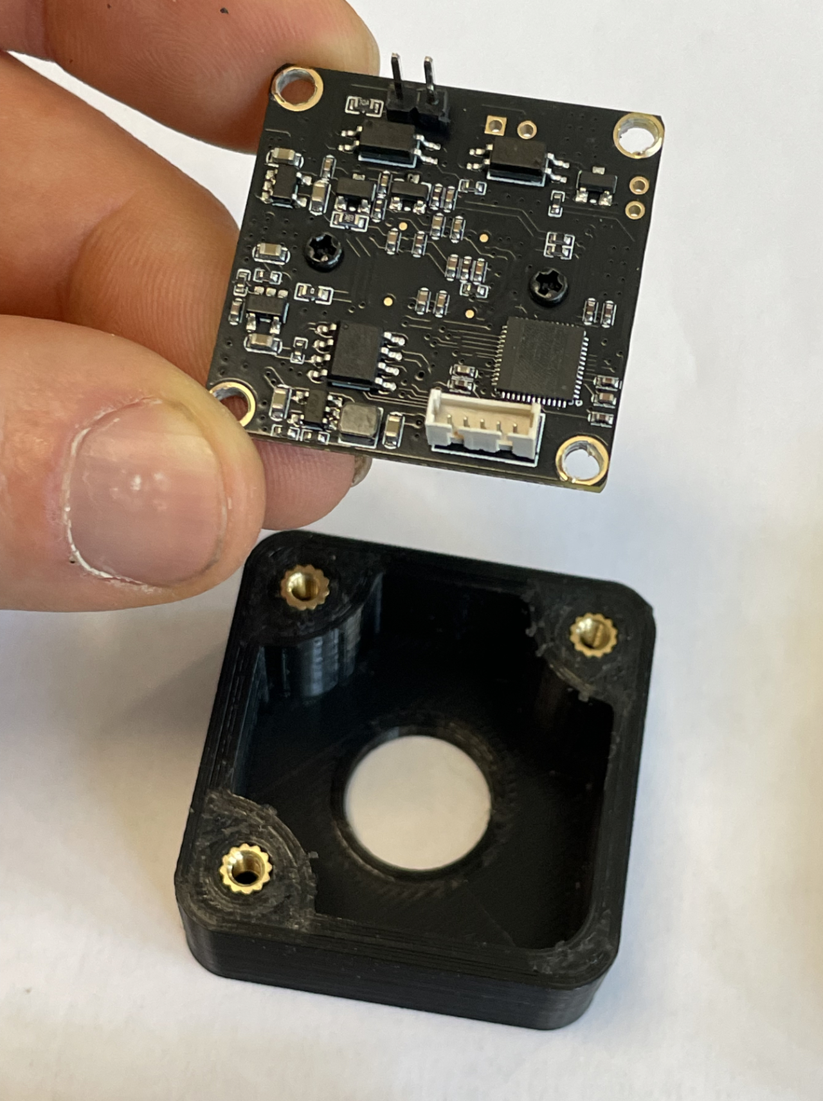
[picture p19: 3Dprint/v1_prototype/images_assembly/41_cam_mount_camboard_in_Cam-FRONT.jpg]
Placing PCB in Front
  
  &nbsp;&nbsp;&nbsp;&nbsp;
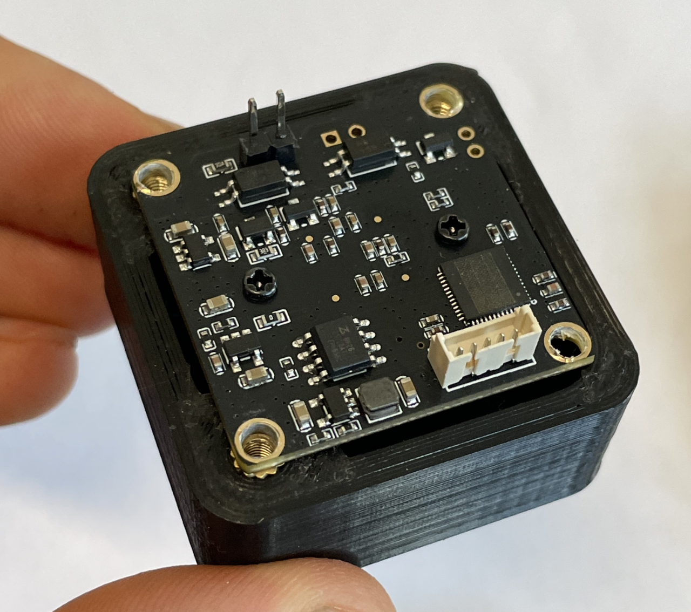
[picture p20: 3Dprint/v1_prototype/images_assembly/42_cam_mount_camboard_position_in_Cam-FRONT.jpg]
PCB Seated in Front
  
</p>

- Insert the OV9281 PCB with the lens facing through the front opening.
- Ensure the trigger header (FSIN pins) and USB connector line up with the orientation cutouts.

---

#### Step 3: Fasten Middle Frame (PCB Sandwich)
<p align="center">
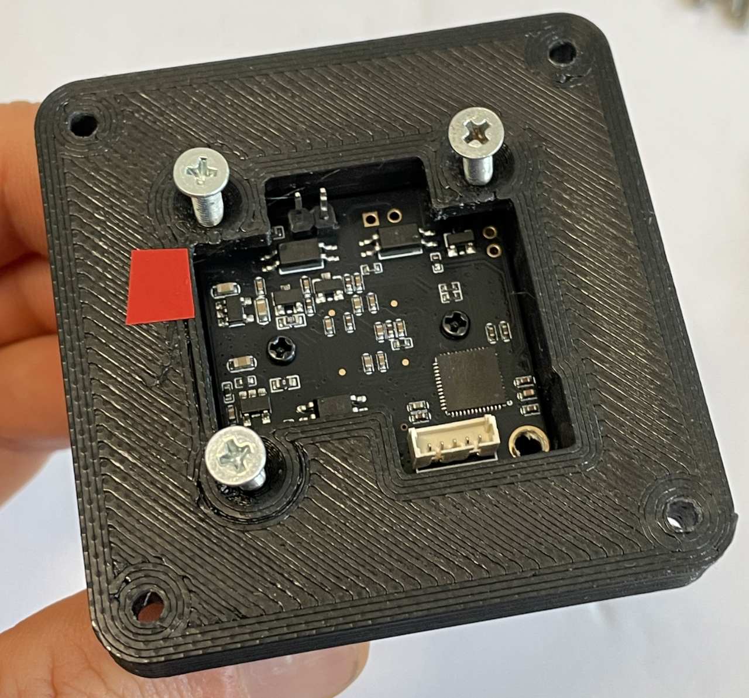
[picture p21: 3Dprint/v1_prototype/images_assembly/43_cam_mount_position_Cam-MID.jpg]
Positioning Middle Frame
  
  &nbsp;&nbsp;&nbsp;&nbsp;
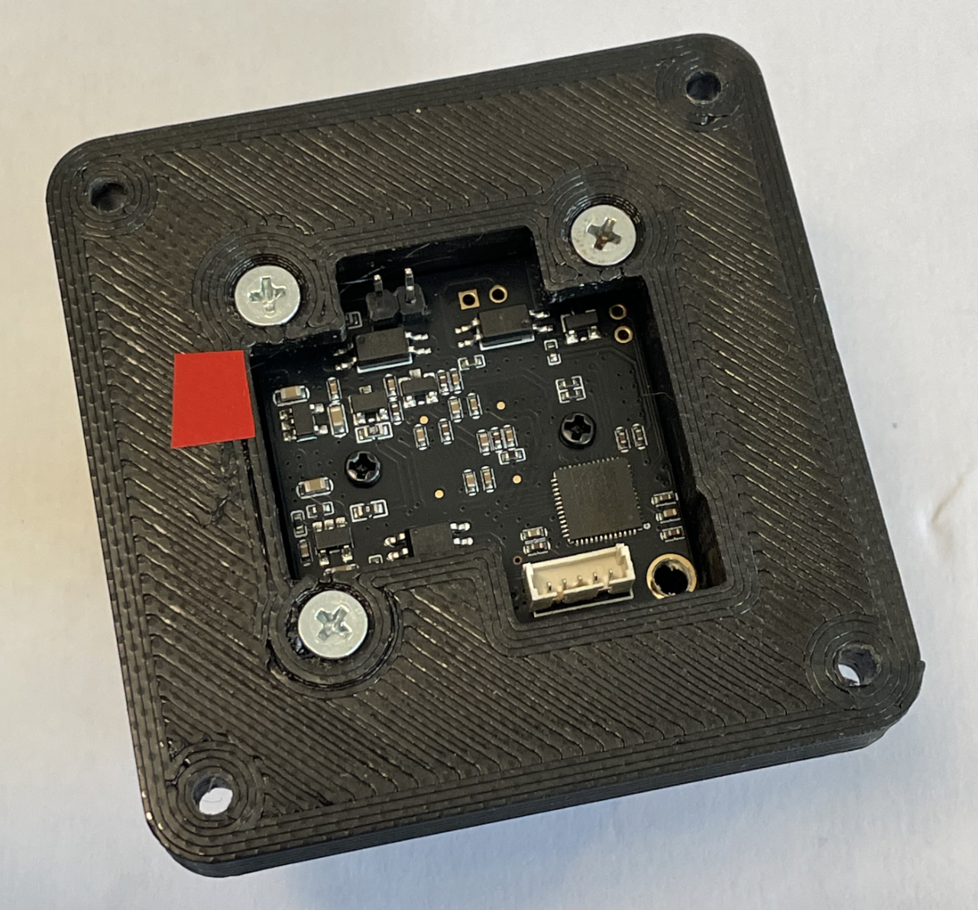
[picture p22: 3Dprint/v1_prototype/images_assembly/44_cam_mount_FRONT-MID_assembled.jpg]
Middle Frame Fastened
  
</p>

- Place `Cam-MID` over the back of the camera PCB.
- Insert and tighten **3x M3 15mm countersunk screws** into the brass inserts of `Cam-FRONT`. The camera PCB is now solidly clamped and locked in place.

---

#### Step 4: Attach Back Cover (Short Variant) & 90° Modular Orientation
<p align="center">
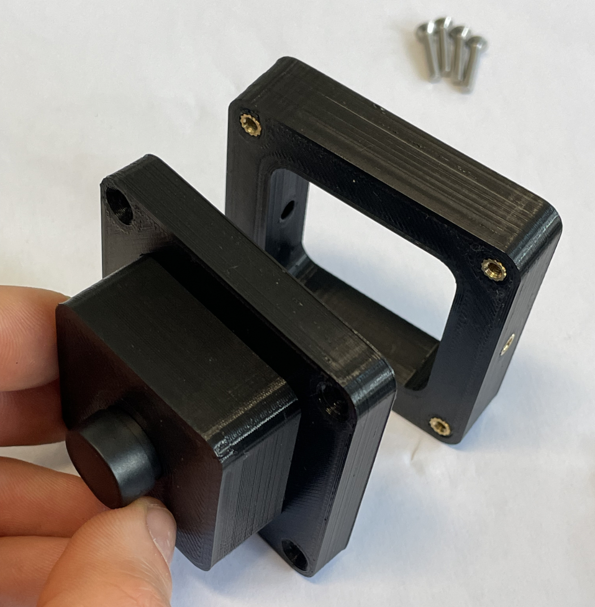
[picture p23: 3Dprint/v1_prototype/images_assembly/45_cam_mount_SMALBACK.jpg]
Positioning Back Cover
  
  &nbsp;&nbsp;&nbsp;&nbsp;
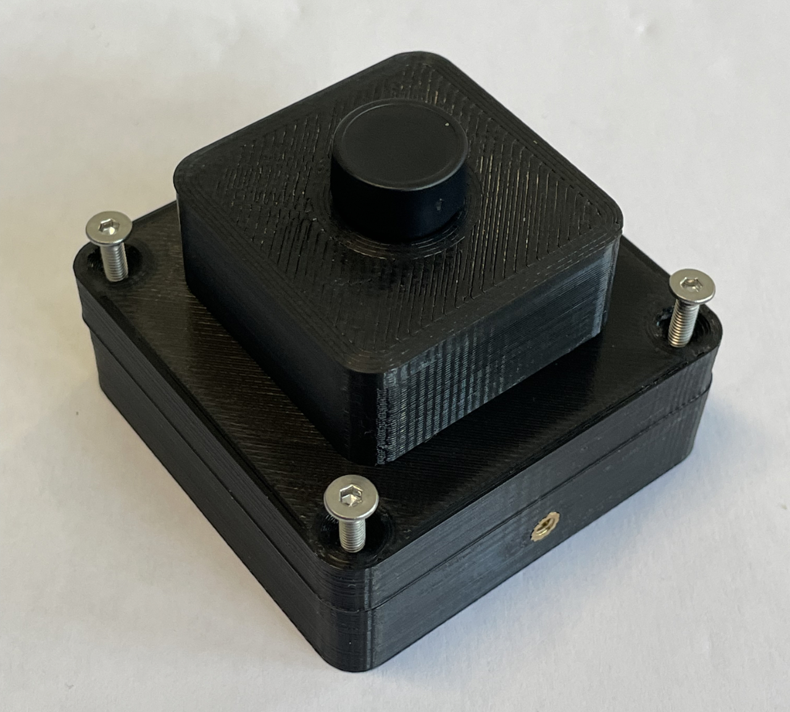
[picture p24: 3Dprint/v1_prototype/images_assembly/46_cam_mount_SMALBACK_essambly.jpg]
Back Cover Fastened
  
</p>

- Align `Cam-BACK-SHORT` (or `Cam-BACK-LONG`) with the middle frame.
- Secure it with **4x M3 15mm screws** threading into the 4 brass inserts of `Cam-MID`.
- **Landscape vs. Portrait Orientation:** Due to the symmetrical 4-hole pattern, you can choose whether the camera is mounted horizontally or vertically (90° rotated) relative to the mounting bracket. Simply rotate the back cover 90° before fastening.

---

#### Step 5: Mount Bracket
<p align="center">
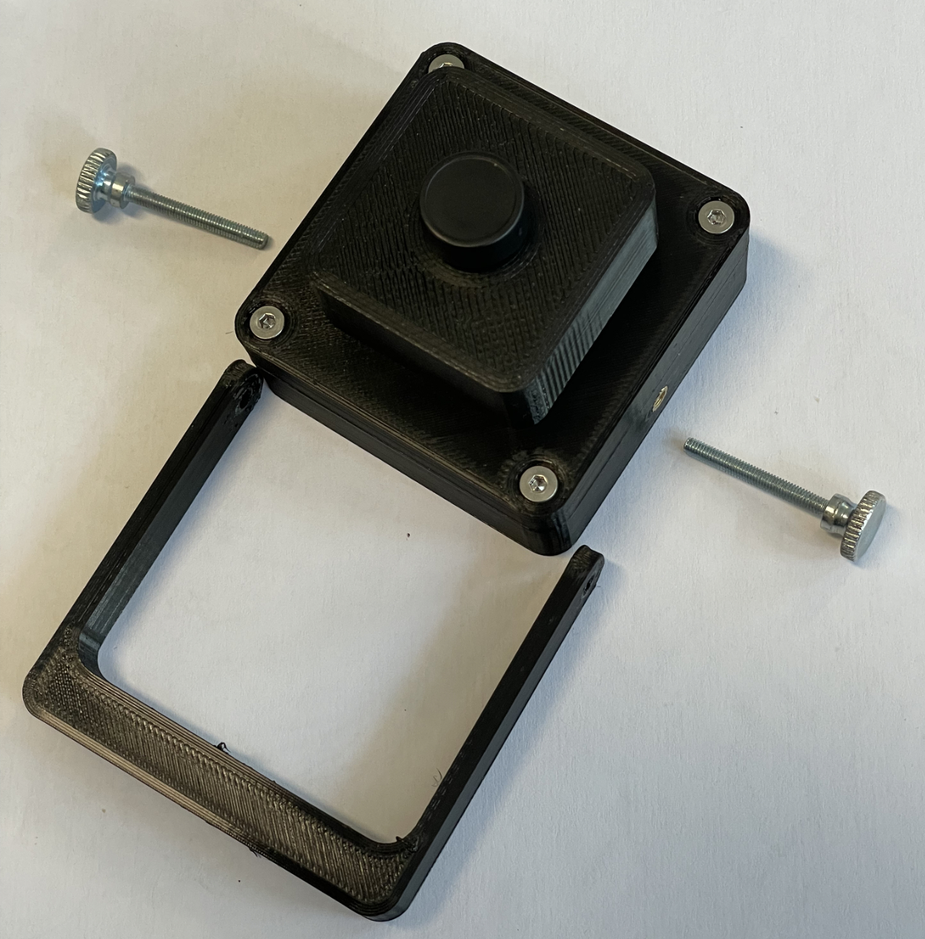
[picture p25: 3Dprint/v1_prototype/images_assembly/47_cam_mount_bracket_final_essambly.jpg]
Mounting Bracket with Thumbscrews
  
</p>

- Attach `Cam-BRACKET` over the sides of the camera enclosure.
- Fasten using **2x M3 thumbscrews (10–25mm length)** into the side brass inserts.

---

#### Step 6: Camera Variants in Action

<p align="center">
  Open Back Camera Connected
  &nbsp;&nbsp;&nbsp;&nbsp;
  Long Back Camera Rear View
</p>
<p align="center">
  Long Back Camera Front Perspective
  <br>
  <em>Left: Open back variant with direct USB and trigger connection via 2-pin micro connector (e.g. JST 1.25mm). Right: Enclosed long back variant with rubber cable strain relief and speaker spring terminal clip.</em>
</p>

---

## Print Recommendations & Technical Notes

### Material & Slicer Settings
- **Material:** PLA or PETG (PLA is tested and works reliably).
- **Infill:** ~20% – 25% (walls are structurally thin and sturdy).
- **Layer Height:** 0.16 mm – 0.20 mm recommended.
- **Supports:** Generally minimal; align parts flat on the print bed.

### Dimensional Tolerances
- All CAD models have been designed with **slightly generous clearances** so parts assemble cleanly even on 3D printers that slightly over-extrude.
- On well-calibrated/high-precision printers, the fit will be comfortable and slightly relaxed.

### Threaded Inserts vs. Self-Tapping Screws
- **M3 Heat-Set Inserts (Einschmelzgewinde):** The mounting holes are designed for standard M3 brass heat-set inserts (melted in with a soldering iron).
- **Alternative for Older/Looser Printers:** If you do not have threaded inserts, you can either use small self-tapping / wood screws directly into the plastic or reduce the hole diameter in the provided FreeCAD `.FCStd` source files before slicing.

---
---

# Deutsche Version

Dieses Verzeichnis enthält die CAD-Konstruktionsdateien (FreeCAD `.FCStd`), 3D-druckbare STL-Dateien (`.stl`), Render-Vorschauen sowie reale Schritt-für-Schritt-Montagefotos für die MoCapSTR Hardware-Komponenten.

---

## Schnellnavigation

- [Hardware-Stückliste (BOM)](#hardware-stückliste-bom)
- [Gesamtsystem-Verbindung](#gesamtsystem-verbindung)
- [CAD- & STL-Komponenten Übersicht](#cad--stl-komponenten-übersicht)
- [Schritt-für-Schritt Montageanleitung](#schritt-für-schritt-montageanleitung)
  - [1. Arduino Trigger-Gehäuse](#1-montage-arduino-trigger-gehäuse)
  - [2. XLR Splitter-Box](#2-montage-xlr-splitter-box)
  - [3. Innomaker OV9281 Kamera-Gehäuse](#3-montage-innomaker-ov9281-kamera-gehäuse)
- [Druckempfehlungen & Technische Hinweise](#druckempfehlungen--technische-hinweise)

---

## Gesamtsystem-Verbindung

<p align="center">
  Gesamtaufbau Trigger und Splitter Box
  <br>
  <em>Arduino Trigger-Box (rechts, mit blauem USB-Kabel zum PC) über XLR-Mikrofonkabel mit der Splitter-Box (links) verbunden, von der 4 DC-Kabel zu den Kameras führen.</em>
</p>

---

## Hardware-Stückliste (BOM)

| Baugruppe | 3D-Druckteile | Elektronik & Komponenten | Schrauben & Inserts |
| :--- | :--- | :--- | :--- |
| **OV9281 Kamera-Gehäuse**<br>*(pro Kamera)* | - 1x `Cam-FRONT`<br>- 1x `Cam-MID`<br>- 1x `Cam-BACK-SHORT` *(oder LONG)*<br>- 1x `Cam-BRACKET` | - 1x Innomaker OV9281 USB-Kamera inkl. Objektiv *(Getestet: bis 120 FPS im Free-Run, max. 50 FPS im Hardware-Trigger-Modus durch Bridge-Firmware)*<br>- 1x 2-Pin Mikro-Steckverbinder (z. B. JST 1.25mm 2-Pin) für FSIN-Pins | - **9x** M3 Einschmelzgewinde<br>- **7x** M3 15mm Schrauben (3x Front/Mid, 4x Mid/Back)<br>- **2x** M3 Rändelschrauben (10–25mm) oder M3 Schrauben für den Bügel |
| **Arduino Trigger-Gehäuse** | - 1x `Trigger_Case-BASE`<br>- 1x `Trigger_Case-LID` | - 1x Arduino Nano<br>- 1x Terminal Block Shield Adapter<br>- 1x Neutrik XLR Einbaubuchse (Männlich, D-Serie)<br>- 1x 12mm Taster (Schließer)<br>- *(Optional)* 1x DC Hohlbuchse (8mm) | - **8x** M3 Einschmelzgewinde<br>- **8x** M3 10mm Schrauben (4x Deckel, 2x XLR, 2x Shield) |
| **XLR Splitter-Box** | - 1x `Splitter_Case-BASE`<br>- 1x `Splitter_Case-LID` | - 1x Neutrik XLR Einbaubuchse (Weiblich, D-Serie)<br>- 4x DC Hohlbuchsen (8mm)<br>- 2x 5-polige Käfigzugklemmen (WAGO) | - **6x** M3 Einschmelzgewinde<br>- **6x** M3 10mm Schrauben (4x Deckel, 2x XLR) |

---

## CAD- & STL-Komponenten Übersicht

### 1. Arduino Trigger-Gehäuse (`Trigger_Case`)

| Bauteil / Datei | Vorschau | Beschreibung |
| :--- | :---: | :--- |
| **Gesamt-Baugruppe**<br>[`v1_prototype/Trigger_Case.FCStd`](v1_prototype/Trigger_Case.FCStd) | Trigger Case Gesamt | Vollständiges CAD-Projekt in FreeCAD. Die Tasteraufnahme befindet sich im Deckel. |
| **Gehäuseunterteil**<br>[`v1_prototype/Trigger_Case-BASE.stl`](v1_prototype/Trigger_Case-BASE.stl) | Trigger Case Base | Nimmt Arduino-Shield, XLR-Einbaubuchse und optionale DC-Hohlbuchse auf. |
| **Deckel**<br>[`v1_prototype/Trigger_Case-LID.stl`](v1_prototype/Trigger_Case-LID.stl) | *(Siehe Gesamtansicht)* | Gehäusedeckel mit **12mm-Montageloch für den Start/Stop-Taster (Trigger-Button)**. |

---

### 2. XLR Splitter-Box (`Splitter_Case`)

| Bauteil / Datei | Ansicht 1 | Ansicht 2 | Beschreibung |
| :--- | :---: | :---: | :--- |
| **Gesamt-Baugruppe**<br>[`v1_prototype/Splitter_Case.FCStd`](v1_prototype/Splitter_Case.FCStd)<br>[`v1_prototype/Splitter_Case-BASE.stl`](v1_prototype/Splitter_Case-BASE.stl)<br>[`v1_prototype/Splitter_Case-LID.stl`](v1_prototype/Splitter_Case-LID.stl) | Splitter Case Ansicht 1 | Splitter Case Ansicht 2 | Verteilergehäuse mit Aufnahme für 1x Neutrik XLR-D Buchse (Weiblich) und **4 Bohrungen für DC-Hohlbuchsen** (8mm). |

---

### 3. OV9281 Kamera-Gehäuse (`OV9281_Case`)

<p align="center">
  OV9281 Kamera-Gehäuse Zusammenbau
  <br>
  <em>Zusammenbau des modularen OV9281 Gehäuses</em>
</p>

| Teil | Datei | Vorschau | Beschreibung |
| :--- | :--- | :---: | :--- |
| **Frontblende** | [`v1_prototype/OV9281_Case_Cam-FRONT.stl`](v1_prototype/OV9281_Case_Cam-FRONT.stl) | Cam Front | Frontabdeckung rund um den M12/CS Objektivhalter (enthält 3 Einschmelzgewinde). |
| **Mittelteil** | [`v1_prototype/OV9281_Case_Cam-MID.stl`](v1_prototype/OV9281_Case_Cam-MID.stl) | Cam Mid | **Platinen-Rückträger:** Klemmt die Kameraplatine mit 3x M3 15mm Schrauben fest an die Frontblende. |
| **Rückteil (Kurz / Short)** | [`v1_prototype/OV9281_Case_Cam-BACK-SHORT.stl`](v1_prototype/OV9281_Case_Cam-BACK-SHORT.stl) | Cam Back Short | **Offene Variante:** Direkter Zugriff auf die Stiftleisten (Header) der Kameraplatine. |
| **Rückteil (Lang / Long)** | [`v1_prototype/OV9281_Case_Cam-BACK-LONG.stl`](v1_prototype/OV9281_Case_Cam-BACK-LONG.stl) | Cam Back Long | **Geschlossene Variante:** Längeres Gehäuse mit Loch für eine **Zugentlastung** und Aufnahme für ein **Lautsprecher-Klemmenterminal**. |
| **Halterung / Bracket** | [`v1_prototype/OV9281_Case_Cam-BRACKET.stl`](v1_prototype/OV9281_Case_Cam-BRACKET.stl) | Cam Bracket | Stativ-/Rig-Halterung mit Bohrung zum Schneiden eines **1/4"-20 UNC Standard-Kamerastativgewindes**. |

---

## Schritt-für-Schritt Montageanleitung

### 1. Montage Arduino Trigger-Gehäuse

<p align="center">
  Trigger Gehäuse Innenverkabelung
  &nbsp;&nbsp;&nbsp;&nbsp;
  Trigger Gehäuse Fertig
</p>

1. **Einschmelzgewinde:** 8x M3 Gewindeeinsätze in das Gehäuseunterteil einschmelzen (4 für die Deckelecken, 2 für die XLR-Buchse, 2 für die Arduino-Shield-Befestigung).
2. **Hardware montieren:** Neutrik XLR-Einbaustecker (Männlich) und Arduino Terminal Shield im Gehäuse verschrauben.
3. **Innenverkabelung:**
   - **XLR Pin 1** (Masse/Schirm) mit Arduino **GND** verbinden.
   - **XLR Pin 2** (Signal Hot) mit Arduino **Pin 2** verbinden.
   - **XLR Pin 3** mit **XLR Pin 1** (GND) brücken.
4. **Taster:** 12mm Taster in den Deckel einbauen. Die beiden Adern mit Arduino **Pin 4** und Arduino **GND** verbinden (nutzt die interne `INPUT_PULLUP` Funktion). Eine kleine 2-polige Klemme erleichtert die Trennung beim Öffnen.
5. **Gehäuse schließen:** Deckel mit 4x M3 10mm Schrauben fixieren.

---

### 2. Montage XLR Splitter-Box

<p align="center">
  Splitter Gehäuse Innenverkabelung
  &nbsp;&nbsp;&nbsp;&nbsp;
  Splitter Gehäuse Montage-Ansicht
</p>
<p align="center">
  Splitter Gehäuse Frontansicht
  &nbsp;&nbsp;&nbsp;&nbsp;
  Splitter Gehäuse Rückansicht mit DC Buchsen
</p>

1. **Einschmelzgewinde:** 6x M3 Gewindeeinsätze einschmelzen (4 in den Deckelecken, 2 für die XLR-Buchse).
2. **Buchsen einbauen:** Neutrik XLR-D Einbaubuchse (Weiblich) vorne und 4x DC-Hohlbuchsen hinten einschrauben.
3. **Verdrahtung mit Käfigzugklemmen (WAGO):**
   - **Signal (Hot):** Eine Ader von **XLR Pin 2** in die erste 5er-Klemme führen. Die 4 Plus-/Mittelkontakte der DC-Buchsen daran anschließen.
   - **Masse & Schirmung (GND):** Eine Ader von **XLR Pin 1** in die zweite 5er-Klemme führen. Alle 4 Masse-/Außenkontakte der DC-Buchsen daran anschließen.
   - *(XLR Pin 3 mit Pin 1 brücken oder frei lassen).*
4. **Gehäuse schließen:** Kabel sauber im Inneren verstauen und den Deckel mit 4x M3 10mm Schrauben verschrauben.

---

### 3. Montage Innomaker OV9281 Kamera-Gehäuse

#### Schritt 1: Teile-Vorbereitung & Einschmelzgewinde
<p align="center">
  Kamera Teileübersicht
</p>

- **3x M3 Gewindeeinsätze** in die inneren Dome von `Cam-FRONT` einschmelzen.
- **4x M3 Gewindeeinsätze** in die 4 Ecken von `Cam-MID` einschmelzen.
- **2x M3 Gewindeeinsätze** in die seitlichen Bohrungen von `Cam-BACK-SHORT` für den Haltebügel einschmelzen.
- Die mittlere Bohrung des `Cam-BRACKET` mit einem **1/4"-20 UNC Gewindeschneider** mit einem Standard-Fotogewinde versehen.

---

#### Schritt 2: Kameraplatine in Frontblende einlegen
<p align="center">
  Platine in Front einlegen
  &nbsp;&nbsp;&nbsp;&nbsp;
  Platine in Front ausgerichtet
</p>

- Die OV9281 Platine mit dem Objektiv voran in die Frontblende einsetzen.
- Auf die Ausrichtung der FSIN-Trigger-Pins und der Buchsen achten.

---

#### Schritt 3: Mittelteil montieren (Platinen-Sandwich)
<p align="center">
  Mittelteil ansetzen
  &nbsp;&nbsp;&nbsp;&nbsp;
  Mittelteil verschraubt
</p>

- `Cam-MID` auf die Rückseite der Platine auflegen.
- Mit **3x M3 15mm Senkkopfschrauben** in die Messingeinsätze der Frontblende festziehen. Die Platine ist nun absolut spielfrei fixiert.

---

#### Schritt 4: Rückteil befestigen & Modulare 90°-Drehung
<p align="center">
  Rückteil ansetzen
  &nbsp;&nbsp;&nbsp;&nbsp;
  Rückteil verschraubt
</p>

- `Cam-BACK-SHORT` (oder `Cam-BACK-LONG`) auf das Mittelteil aufsetzen.
- Mit **4x M3 15mm Schrauben** in die 4 Gewindeeinsätze des Mittelteils verschrauben.
- **Querformat vs. Hochkant:** Durch das quadratische 4-Schrauben-Muster kann das Rückteil bei Bedarf um 90° gedreht aufgeschraubt werden, um die Kamera hochkant am Stativbügel zu befestigen.

---

#### Schritt 5: Stativbügel montieren
<p align="center">
  Stativbügel Montage
</p>

- `Cam-BRACKET` über das Gehäuse schieben.
- Mit **2x M3 Rändelschrauben (10–25mm Länge)** in den seitlichen Gewindeeinsätzen befestigen.

---

#### Schritt 6: Kamera-Varianten im Einsatz

<p align="center">
  Kamera Rückseite verkabelt (Open Back)
  &nbsp;&nbsp;&nbsp;&nbsp;
  Kamera Rückansicht mit Zugentlastung (Long Back)
</p>
<p align="center">
  Kamera Frontansicht geschlossen (Long Back)
  <br>
  <em>Links: Offenes Rückteil (Open Back) mit direktem Steckzugriff auf USB und Trigger-Header via 2-Pin-Mikrostecker (z. B. JST 1.25mm). Rechts: Voll geschlossenes langes Rückteil mit Gummi-Zugentlastung und Lautsprecher-Klemmenterminal.</em>
</p>

---

## Druckempfehlungen & Technische Hinweise

### Material & Slicer-Einstellungen
- **Material:** PLA oder PETG (PLA ist formstabil und getestet).
- **Infill:** ca. 20% – 25% (Wandstärken bieten ausreichend Stabilität).
- **Schichthöhe (Layer Height):** 0.16 mm – 0.20 mm empfohlen.
- **Stützstrukturen (Supports):** Kaum notwendig; Teile flach auf dem Druckbett ausrichten.

### Passungen & Toleranzen
- Alle CAD-Modelle sind mit **leicht großzügigen Toleranzen** konstruiert, damit alles auch bei leichter Überextrusion ohne Schleifen zusammenpasst.
- Bei hochpräzisen Druckern sitzen die Teile angenehm locker und spannungsfrei.

### Einschmelzgewinde vs. Direktverschraubung
- **M3 Einschmelzgewinde (Heat-Set Inserts):** Alle Schraubpunkte sind für M3-Messing-Gewindeeinsätze ausgelegt.
- **Alternative:** Kleine Holz-/Blechschrauben direkt in den Kunststoff eindrehen oder Bohrungen in FreeCAD verkleinern.

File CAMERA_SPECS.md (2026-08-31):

# Camera Specifications

**Model:** Innomaker USB 2.0 UVC Camera Module (OV9281)

## Sensor Details
- **Sensor:** 1/4'' OV9281 CMOS Sensor, 1 Mega Pixel, 1280(H) x 800(V), 3μm*3μm
- **Type:** Monochrom (schwarz/weiß Bild)
- **Shutter Type:** Global Shutter
- **S/N Verhältnis / Dynamikbereich:** 38dB / 68dB
- **Empfindlichkeit:** 6500 bis 13000 mV/uW

## Optics
- **FOV:** 140° (H) x 115° (V) x 62° (D)
- **Linsen Sitzbestand:** 18mm

## Video Output & Performance
- **USB-Type:** USB 2.0 High Speed, USB 2.0 OTG, USB Videoklasse (UVC)
- **Ausgabeparameter:** MJPG 1280x720 120fps
- **Ausgabeformat:** MJPG / YUY2
- **MJPG Auflösung & Bildrate:**
  - 1280x800 @ 120, 30, 15, 10 fps
  - 1280x720 @ 120, 60, 30, 20, 15, 10 fps
  - 800x600 @ 120, 60, 30, 20, 15, 10 fps
  - 640x400 @ 120, 60, 30, 20, 15, 10 fps
  - 640x360 @ 120, 60, 30, 20, 15, 10 fps
- **YUY2 Auflösung & Bildrate:**
  - 1280x800 @ 10 fps
  - 1280x720 @ 10 fps
  - 800x600 @ 10 fps
  - 640x480 @ 30, 20, 15, 10 fps
  - 640x400 @ 30, 20, 15, 10 fps
  - 320x240 @ 60, 30, 20, 15, 10 fps
  - 320x200 @ 60, 30, 20, 15, 10 fps

## Control Parameters (UVC)
- **Automatische Parameter:** Automatische Belichtungssteuerung (AEC) / Automatische Weißbilanz (AEB) / Automatische Verstärkungssteuerung (AGC)
- **Steuerbare Parameter:** Helligkeit, Kontrast, Farbton, Sättigung, Schärfe, Gamma, Weißabgleich, Hintergrundbeleuchtungskompensation, Verstärkung, Belichtung, PowerLine Frequenz, Low Light Kompensation

## Hardware & Connection
- **Kabellänge:** 1M
- **Unterstützung OS:** WinXP/Vista/Win7/Win8/Win10, Linux mit UVC (über linux-2.6.26), MAC-OS X 10.4.8 oder höher, Android 4.0 oder höher mit UVC

## External Trigger & Strobe
- **Externe Trigger:** Unterstützung (Aktivierung über UVC-Parameter `AutoFocus = 1` / `Focus = 0`)

### Pin-Beschreibung (Trigger)
- **`FSIN +`** : Externer Trigger-Eingang (3,3 V–5 V) - *Direkt kompatibel mit 5V Arduino Ausgängen*
- **`FSIN -`** : Externe Masse (GND)

### Pin-Beschreibung (Strobe)
- **`STROBE +`** : Sensor-STROB+ (Signal für externen Blitz)
- **`STROBE -`** : Masse (GND)

---

## Hardware-Trigger Frameraten & Timing-Charakteristik

Empirische Benchmark-Messungen mit MoCapSTR haben folgende Leistungsdaten für den InnoMaker OV9281 ermittelt:

| Betriebsmodus | Maximale Framerate | Verhalten |
| :--- | :--- | :--- |
| **Free-Run (Interner Takt)** | **120 FPS** (1280x720 / 1280x800) | Kontinuierliches Sensor-Pipelining, extrem flüssig. |
| **Hardware-Trigger (FSIN-Sync)** | **50 FPS** (1280x720 & 640x400) | Synchroner Frame-Zyklus im USB-ISP mit $\approx 18\text{–}20\text{ ms}$ Lockout. |

### Wichtige Erkenntnisse für den Trigger-Betrieb:
1. **50 FPS Hardware-Limit:** 
   Im Trigger-Modus benötigt der USB-Bridge-Chip der Kamera nach jedem Puls $\approx 18\text{–}20\text{ ms}$ für Belichtung, Zeilenauslese, JPEG-Kompression und USB-Endpunkt-Freigabe, bevor der Trigger-Eingang für den nächsten Frame freigeschaltet wird.
   - **50 Hz Trigger (20,0 ms Periode):** $\rightarrow$ **50.0 FPS** (1:1 sauber).
   - **60 Hz Trigger (16,6 ms Periode):** $\rightarrow$ **30.0 FPS** (1:2, jeder 2. Puls wird verworfen).
   - **90 Hz Trigger (11,1 ms Periode):** $\rightarrow$ **45.0 FPS** (1:2, jeder 2. Puls wird verworfen).
   - **120 Hz Trigger (8,33 ms Periode):** $\rightarrow$ **40.0 FPS** (1:3, 2 von 3 Pulsen werden verworfen).
2. **Empfohlene MoCapSTR-Einstellung:**
   - **Auflösung:** `1280x720 (720p)`
   - **Target FPS:** `50`
   - **USB Polling:** `Auto` (fordert 120 FPS USB-Stream an)
   - **Belichtung:** `-9` (1/512s) oder `-10` (1/1024s)
   - **Trigger-Pulsweite (Arduino):** `250 µs` bis `500 µs`

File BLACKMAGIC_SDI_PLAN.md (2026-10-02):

# Blackmagic SDI-Modus: Instandsetzung (geplant für v2.0)

Kommt erst, wenn die Basis mit USB-Kameras und Arduino-Trigger stabil läuft.

**Status (v1.5.1):** Der Modus "Blackmagic SDI" ist **aktuell nicht funktionsfähig**.
Dieses Dokument hält Ursache, getroffene Entscheidungen und den Arbeitsplan fest, damit die Instandsetzung später direkt starten kann.

---

## 1. Warum der Modus kaputt ist

- Der Modus wurde zuletzt mit dem **alten OpenCV-Backend** getestet (eine Kamera, Bild wurde erkannt). Mehrkamera-Aufnahmen wurden nie geprüft.
- Seit der Umstellung auf PyAV (Commit `ff2cb91`) öffnet `camera_manager.py` die Karte mit `av.open(name, format='decklink')`. Die PyAV-Pakete enthalten **kein `decklink`-Format** (geprüft: `'decklink' in av.formats_available` → `False`, `dshow` → `True`).
- Zusätzlich bricht `find_and_open_cameras()` im Blackmagic-Zweig mit `UnboundLocalError` ab: `device_number` wird nur im USB-Zweig gesetzt.
- Ältere Planung: `SDI_INTEGRATION_PLAN.md` in Commit `a944d9b` (inzwischen aus dem Repo entfernt).

## 2. Getroffene Entscheidungen

| Thema | Entscheidung |
|---|---|
| Anbindung | Über **DirectShow** (`format='dshow'`), wie bei den USB-Kameras. Der Desktop-Video-Treiber stellt jeden SDI-Eingang als eigenes Gerät bereit ("Decklink Video Capture", "Decklink Video Capture (2)", …). Kein DeckLink SDK, kein eigener FFmpeg-Build. |
| Aufnahmeformat | Wählbar. **Standard: unkomprimiert** (einfachster und verlustfreier Weg, braucht viel Platz). **Optional: Kodierung auf der Grafikkarte**, herstellerunabhängig: AMD (`h264_amf`/`hevc_amf`), NVIDIA (`h264_nvenc`), Intel (`h264_qsv`). Alle sind in den PyAV-Paketen enthalten. Das Tool bietet nur Encoder an, die sich auf dem PC tatsächlich öffnen lassen. |
| Genlock | **Kein Bestandteil des Tools.** Genlock ist externe Hardware zwischen den Kameras. Das Tool muss mit und ohne Genlock funktionieren. Ohne Genlock können die Belichtungen bis zu einem halben Frame auseinanderliegen. Das ist bei FreeMoCap mit Webcams genauso und funktioniert. |
| Frame-Ausrichtung | Ohne Arduino-Trigger gibt es keinen Stopp/Neustart des Takts. Start und Ende werden **nach der Aufnahme per Ankunftszeitstempel ausgerichtet** (`clip_sync`, die Zeitstempel werden seit v1.5.0 mitgeschrieben). |
| Interlaced | Muss **erkannt** werden, mit Hinweis "Kamera auf progressiv umstellen". PsF darf **nicht** als Fehler gelten (siehe 3.3). |
| Allgemeingültigkeit | Keine kameraspezifischen Annahmen. Formate werden vom Gerät gelesen bzw. gemessen. |

## 3. Technische Eckpunkte

### 3.1 Datenraten (unkomprimiert, 8 Bit 4:2:2 / UYVY = 2 Byte pro Pixel)

| Format | pro Kamera | 4 Kameras | pro Minute (4 Kameras) |
|---|---|---|---|
| 720p50 | ca. 92 MB/s | ca. 370 MB/s | ca. 22 GB |
| 1080PsF25 | ca. 104 MB/s | ca. 415 MB/s | ca. 25 GB |
| 1080p50 | ca. 207 MB/s | ca. 830 MB/s | ca. 50 GB |

- 4× 720p50 schafft eine SATA-SSD knapp, ab 1080p50 braucht es eine NVMe-SSD.
- Falls die Karte 10 Bit (v210) liefert, sind die Raten etwa ein Drittel höher.
- Vor jeder Aufnahme sollte das Tool prüfen, ob Datenrate und freier Platz zusammenpassen, und warnen.

### 3.2 Aufnahmepfad

- **Unkomprimiert:** Die Pakete von DirectShow (rawvideo) unverändert per Stream-Copy in `.avi`/`.mkv` schreiben, wie bisher bei MJPEG. Zu prüfen: Kann FreeMoCap (OpenCV) rawvideo-AVI in dieser Größe flüssig lesen? Bei AVI gibt es eine 4-GB-Grenze pro Datei → für unkomprimiert vermutlich **MKV**.
- **GPU-Kodierung:** Frames dekodieren und mit dem Hardware-Encoder der Grafikkarte kodieren, pro Kamera ein eigener Thread.
  - Verfügbare Encoder beim Start ermitteln: Testweise öffnen und ein paar Frames kodieren. Nur was funktioniert, erscheint in der Auswahl.
  - **DeckLink-PC: AMD Radeon RX 5700 XT** (VCN 2.0) → `h264_amf` oder `hevc_amf`. Kein AV1-Encoder, kein NVENC.
  - Zu prüfen: Schafft der Encoder die Summe aller Kameras in Echtzeit (z. B. 4× 720p50 = 200 Bilder/s, 4× 1080p50 = 200 Bilder/s in Full HD)? Wie viele Encoder-Sitzungen laufen gleichzeitig stabil (bei NVIDIA-GeForce je nach Generation 3 bis 8), und wie hoch ist die Latenz?
  - Falls die GPU nicht reicht: Warnung vor der Aufnahme bzw. Rückfall auf unkomprimiert.
- Die vorhandene Logik bleibt nutzbar: Aufnahme-Sessions, das Auffüllen verlorener Frames und die Zeitstempel-CSV im FreeMoCap-Format.

### 3.3 Interlaced vs. PsF vs. progressiv

- **Echtes Interlaced (1080i):** Die beiden Halbbilder stammen aus verschiedenen Zeitpunkten, bei Bewegung entsteht Kammartefakt. Für Mocap ungeeignet → **Warnung**.
- **PsF (z. B. 1080PsF25):** Der Bildinhalt ist progressiv, wird aber als zwei Halbbilder übertragen. Die Karte meldet das Signal oft als "interlaced" (z. B. 1080i50). Setzt man die Halbbilder wieder zusammen, entsteht ein sauberes progressives 25p-Bild → **kein Fehler**, nur der Hinweis "PsF erkannt, Bildrate 25".
- **Erkennung, zweistufig:**
  1. **Signal:** Prüfen, ob DirectShow bzw. das Format Halbbilder meldet (Feldreihenfolge/Interlace-Flags im Medientyp, `codec_context.field_order`).
  2. **Bildinhalt:** Den FFmpeg-Filter `idet` (über einen PyAV-Filtergraph) auf einige Sekunden Vorschau anwenden. Er zählt, ob die Frames Kammartefakte haben. Interlaced-Signal mit progressivem Inhalt → PsF (ok). Interlaced-Inhalt → Warnung "auf progressiv umstellen".
- Zu prüfen: Was meldet der Treiber bei PsF genau, und funktioniert `idet` mit Testbildern bzw. bei wenig Bewegung zuverlässig? Die Warnung soll erst nach genug Frames mit Bewegung kommen, um Fehlalarme zu vermeiden.

### 3.4 Synchronität ohne Trigger

- **Mit Genlock:** Die Frames aller Kameras kommen innerhalb weniger Millisekunden an. Die Ausrichtung per Ankunftszeit ist eindeutig, Frame N ist auf allen Kameras derselbe Moment.
- **Ohne Genlock:** Der Versatz zwischen den Kameras liegt bei bis zu ±½ Frame und wandert langsam. Die Ausrichtung nimmt pro Kamera den zeitlich nächstliegenden Frame. Die Clips sind dann gleich lang und höchstens ½ Frame versetzt. Das Tool sollte den gemessenen Versatz anzeigen (Info, kein Fehler).
- Gerätezeitstempel (`device_time_s`) zur Erkennung verlorener Frames: Prüfen, ob der DeckLink-Treiber sinnvolle Zeitstempel liefert.

### 3.5 Hardware-Hinweise

- **DeckLink-PC (Testsystem):** DeckLink Duo 2, AMD Radeon RX 5700 XT, SSD. Python, IDE werden dort eingerichtet, sodass direkt am Gerät getestet und nachgebessert werden kann.
- **DeckLink Duo 2:** 4 SDI-Anschlüsse, einzeln als Ein- oder Ausgang konfigurierbar (in "Blackmagic Desktop Video Setup"), Eingänge bis **1080p60 (3G-SDI), kein UHD**.
- **Panasonic AG-HPX500 / AW-HE870** (vorhanden): liefern 1080PsF25 oder 720p50. **Für Mocap 720p50 empfehlen** (doppelte zeitliche Auflösung, PsF25 ist für schnelle Bewegungen grob).
- **Blackmagic 12K / ARRI Alexa etc:** Den SDI-Ausgang an der Kamera auf **1080p** (progressiv) stellen, da die Duo 2 kein UHD/12G-SDI annimmt. Beide haben Genlock.
- Das Eingangsformat muss zum Signal passen. Zu prüfen: Erkennt der Treiber das Format automatisch, oder muss das Tool es vorgeben?

## 4. Arbeitsplan

1. **Diagnose am DeckLink-PC.** Ein eigenständiges Skript (`tests_hardware/decklink_probe.py`) macht Folgendes und schreibt alles in eine Berichtsdatei:
   - SDI-Geräte und angebotene Formate auflisten (Auflösung, Rate, Pixelformat, Interlace-Flags).
   - Mit 1, 2 und 4 Eingängen gleichzeitig je ein paar Sekunden aufnehmen.
   - Messen: FPS, verlorene Frames, Ankunftsversatz zwischen den Eingängen, Datenrate, Gerätezeitstempel.
   - `idet` auf jedem Eingang laufen lassen.
   - Testen, welche GPU-Encoder sich öffnen lassen (AMF/NVENC/QSV) und wie schnell sie mit 1 bis 4 gleichzeitigen Streams kodieren, zum Vergleich auch MJPEG auf der CPU.
   - Schreibgeschwindigkeit der Ziel-SSD messen.
   - Version des Desktop-Video-Treibers mit in den Bericht schreiben.
2. **Umbau** auf Basis der Messwerte:
   - Blackmagic-Zweig in `camera_manager.py` auf DirectShow umstellen, `device_number` fixen.
   - Formatwahl aus den Gerätedaten statt fester Liste.
   - Aufnahmeoption "Unkomprimiert / GPU-Kodierung (AMF, NVENC, QSV – je nach PC)" im Setup-Tab.
   - Interlace/PsF-Erkennung mit Hinweis in der Vorschau.
   - Ausrichtung per Zeitstempel in `clip_sync` (Modus ohne Trigger) und Prüfung von Datenrate und Speicherplatz vor der Aufnahme.
   - Tests mit simulierten Daten wie bei den USB-Kameras.
3. **Test am DeckLink-PC** schrittweise mit 1, 2 und 4 Kameras, mit und ohne Genlock, mit 720p50 und PsF25. Danach Import in FreeMoCap 2 (gleiche Frame-Zahl, erkannte Bildrate).

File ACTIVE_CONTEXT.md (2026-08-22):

# Active Context

**Current Status:** Implemented dedicated `freemocap_bridge.py` module and One-Click 'Convert & Send to FreeMoCap' workflow in `export_tab.py`. System is at v1.4.0.
**Last Modified:** 2026-08-22 19:28:00

---

## Instructions for LLM Assistants
Welcome to the MoCapSTR project. This file (`ACTIVE_CONTEXT.md`) serves as the central memory for this repository. 

**Whenever you make significant changes to this project, you MUST update this file:**
1. Update the **Last Modified** timestamp to the current time.
2. Update the **Current Status** with a brief summary of what you just completed.
3. Append a short bullet point to the **Recent Changes** list below.

This ensures that the next AI assistant immediately knows what was just done and where the project currently stands.

## Recent Changes
- **2026-08-10:** Added top control bar in Live Preview tab including Recording Timer, Frame Counter, Disk Space Warning, and live Dropped Frame detection.
- **2026-08-10:** Implemented `PresetManager` to save/load all UI settings to `presets.json`. Overhauled the Setup Tab UI using `CTkFrame` cards for better grouping.
- **2026-08-10:** Added FreeMoCap specific Charuco Board parameters (Dictionary, Grid, Sizes) and a live `cv2.aruco` detection overlay in the Live Preview tab.
- **2026-08-10:** Implemented Phase 1 of Blackmagic SDI Integration. Added "Camera Type" dropdown to UI to switch between USB and Blackmagic SDI. Modified CameraManager to apply resolution and framerate to DeckLink WDM filters before the first frame read to ensure successful initialization.
- **2026-08-11 (v1.0.4):** Created `CameraTestTab` (Tab 4) to brute-force test camera capabilities. Added Format selector (MJPG / YUY2) to the Setup Tab and `CameraManager`.
- **2026-08-11 (v1.0.5):** Improved `CameraTestTab` by adding a "Scan All" option that reports identical available combinations across all connected cameras.
- **2026-08-11 (v1.1.0):** Major architectural refactor. Replaced `cv2.VideoCapture` with `PyAV` (FFmpeg) in `camera_manager.py` and `recorder.py`. Implemented Zero-Copy stream muxing (direct MJPEG to disk without CPU decoding).
- **2026-08-11 (v1.0.6):** Fixed PyAV frame drops by offloading Charuco and rotation logic to a separate `PreviewWorker` thread. Fixed MKV 1000fps timestamp bug.
- **2026-08-11 (v1.0.7):** Implemented Arduino Software-Integration (Python GUI). Added "Auto-Trigger on Record" logic, automatic FPS matching.
- **2026-08-11 (v1.0.8):** Added FreeMoCap `session_info.json` metadata generation. Implemented Camera Rotation Persistence. Added Watchdog `<PING>` to Arduino.
- **2026-08-11 (v1.0.9):** Added hardware remote control functionality. Rewrote Arduino firmware and `arduino_sync.py` to use asynchronous threading for physical push buttons.
- **2026-08-12:** Hardware documentation & Trigger Fix. Added `CAMERA_SPECS.md` detailing the Innomaker OV9281. Updated `setup_tab.py` to correctly activate the external hardware trigger on these cameras by toggling the UVC `FOCUS` parameter.
- **2026-08-12 (v1.1.0):** Complete UI/UX Overhaul. Rewrote the setup process into a dynamic, top-to-bottom studio workflow. Removed `record_tab.py` entirely.
- **2026-08-12:** Added `arduino/test_hardware.py` standalone diagnostic script and `HARDWARE_SETUP.md` professional XLR Splitter Box wiring guide.
- **2026-08-12 (v1.1.1):** Added new "Export & Convert" tab for offline PyAV transcoding of raw MJPEG to H.264.
- **2026-08-13 (v1.1.2):** Improved Arduino intelligent Auto-Trigger logic. Created `arduino/arduino_test_ui.py` standalone UI tool.
- **2026-08-13 (v1.1.3):** Fixed Innomaker UVC Hardware Trigger integration. Switched `sync_hardware_exposure` to use OpenCV's MSMF backend.
- **2026-08-13 (v1.1.4):** Implemented One-Click System Initialization. Consolidated camera opening and hardware sync into a single robust button in the UI.
- **2026-08-13 (v1.1.5):** Resolved DSHOW/MSMF driver lock issues causing UVC settings to fail or flicker. Separated property application into two phases.
- **2026-08-13 (v1.1.6):** Arduino firmware timing fix to eliminate cumulative drift. Added new `<PULSE:N>` serial command. Setup Tab UX improvements.
- **2026-08-13 (v1.1.7):** Resolved the Hardware Trigger Framerate drop mystery (Targeting 60 yielded 30). Proved via empirical sweeping that the Innomaker OV9281 firmware has a fixed ~18-20ms sensor readout time over USB 2.0 in trigger mode, regardless of requested resolution. This caps the physical hardware trigger limit to strictly 50 FPS. Any trigger faster than 50Hz (e.g. 60Hz) strikes the sensor during readout, corrupting the pipeline and halving the framerate. Fixed UI: removed hard exposure slider clamping in favor of a physics-aware warning label. Fixed Backend: changed `CAP_PROP_AUTO_EXPOSURE` flag to `0.25` to correctly disable Auto-Exposure under Windows DirectShow. Default exposure set to -9 (1/512s) to ensure 50 FPS works out-of-the-box.
- **2026-08-17 (v1.1.8):** Fixed initialization hang on phantom COM ports by adding a `<PING>`/`<PONG>` handshake verification to `arduino_sync.py` during connection. Added graceful fallback to free-run mode if the hardware trigger is requested but no Arduino is verified. Fixed a bug in PyAV camera enumeration where multiple cameras with identical names (e.g. "USB Camera") would fail to open due to missing `video_device_number` parameter in FFmpeg dshow options. Fixed OpenCV hardware sync index logic so exposure/gain settings apply to all identical cameras instead of just the first one.
- **2026-08-17 (v1.1.9):** Added custom program window icon support using `design/Icon.ico`. Configured `main.py` with `sys._MEIPASS` pathing to ensure the icon persists when bundled via PyInstaller.
- **2026-08-17 (v1.2.0):** Fixed a bug in `camera_manager.py` where exposure changes only applied to a subset of identical cameras. MSMF hardware trigger initialization was accidentally resetting DSHOW exposure settings due to Windows enumeration differences. Fixed by separating the initialization into a dedicated MSMF pass for all cameras, followed by a DSHOW pass.
- **2026-08-17 (v1.2.1):** Added filter to ignore virtual cameras (like OBS Virtual Camera) in hardware enumeration to prevent MSMF/DSHOW I/O errors. Removed obsolete 'Auto-Trigger on Record' checkbox from the Setup UI as the trigger now runs continuously for PyAV Live Preview. Changed default target FPS from 50 to 30, and default exposure from -9 (1/512s) to -8 (1/256s) for better out-of-the-box brightness.
- **2026-08-17 (v1.2.2):** Redesigned the "Project & Setup" tab into a cleaner 2-card layout ("Project & Presets" and "Hardware Configuration") using Grid alignment. Removed the manual Gain slider to save space and simplify the interface, hardcoding hardware gain to 0 during initialization.
- **2026-08-17 (v1.2.3):** Documentation overhaul (`README.md`). Fixed a quality degradation issue in `export_tab.py` by lowering the FFmpeg H.264 Constant Rate Factor (CRF) from 23 to 15, ensuring the resulting `.mp4` files are visually lossless compared to the raw MJPEG AVI recordings.
- **2026-08-17 (v1.2.4):** Bug-fix session across multiple files. **`export_tab.py`**: Fixed `AttributeError` crash on "Scan" button — `ProjectManager` has no `current_project_dir()` method; replaced with correct `base_path + current_project` path construction. Fixed AVI scan using non-recursive `glob` that never found files nested inside `takes/take_XYZ/synchronized_videos/`; switched to `glob(..., recursive=True)`. Fixed `TypeError` crash during conversion progress update caused by passing keyword args to `self.after()` — replaced with lambda. Changed FPS fallback from 50 to 30 (consistent with UI default). Added cleanup of incomplete `.mp4` output file when conversion fails mid-stream. **`camera_test_tab.py`**: Added guard to prevent "Run Scan" from silently killing an active recording. **`main.py`**: Fixed FPS fallback 50→30. **`preview_tab.py`**: Fixed lone German UI string "Aufnahme aktiv" → "Enable Recording". **`README.md`**: Restructured as bilingual (English first, German second).
- **2026-08-17 (v1.2.4 Build):** Built standalone onefile executable `MoCapSTR.exe` (and `MoCapSTR 1.2.4.exe`) in `dist/`. Enhanced `design/Icon.ico` with complete multi-resolution icon sizes (16x16 up to 256x256), configured `MoCapSTR.spec` with all CustomTkinter theme assets, PyAV, pygrabber, comtypes, screeninfo, opencv, and pillow dependencies. Verified startup.
- **2026-08-19 (v1.2.5):** Added "Kameras Zurücksetzen (UVC Wakeup)" feature to simulate the OBS driver reset behavior. Implemented `reset_uvc_drivers` in `camera_manager.py` which explicitly clears the `CAP_PROP_AUTOFOCUS` flag to ensure cameras safely leave hardware trigger mode upon reset. Added a prominent yellow UI button in `setup_tab.py` to trigger this async reset.
- **2026-08-19 (v1.2.6):** Implemented frame-exact clip synchronization to fix FreeMoCap import rejection. **Two-phase atomic start**: `MultiCamManager.start_recording()` now separates container preparation (Phase 1, sequential I/O) from recording activation (Phase 2: single `threading.Event.set()` call that arms all cameras simultaneously), eliminating start-of-clip frame drift caused by sequential `is_recording=True` flag setting. **Post-recording trim**: `stop_recording()` now returns `{cam_idx: (path, frames)}` and a new `trim_clips_to_min_frames()` method re-muxes over-long clips to `min_frames` via PyAV stream-copy (lossless, no re-encoding) using atomic `os.replace()`. Trim runs in a background thread in `main.py` so the UI stays responsive. Four bugs fixed: stale `output_path` for non-active workers between sessions, inflated `frames_recorded` counter in transcoding no-op path, gate/is_recording shutdown ordering race, and missing `frames > 0` guard in results collection.
- **2026-08-19 (v1.2.7):** Fixed camera detection in hardware-trigger mode. A camera in trigger mode emits no frames until it receives a pulse, causing the packet-verification loop in `find_and_open_cameras` to block indefinitely and discard the camera. Fix 1: packet verification is now skipped entirely in trigger mode — a successful `av.open()` with a valid video stream is sufficient proof the camera is present. Fix 2: added 500ms sleep after the MSMF trigger-activation pass so all cameras can settle into external-trigger mode before PyAV opens streams. Fix 3: free-run packet probing is capped at 50 packets to prevent hangs on misbehaving cameras. Fix 4: added 300ms pause in `setup_tab.py` after `arduino.start_trigger()` to ensure the first pulse reaches all cameras before stream verification.
- **2026-08-19 (v1.2.8):** Perfect frame alignment for hardware-trigger mode. When recording starts/stops, the Arduino trigger is briefly paused to drain PyAV buffers. This guarantees that all cameras start and end on the exact same frame pulse, resolving FreeMoCap clip length rejection issues.
- **2026-08-19 (v1.2.9):** Fixed missing 4th camera issue in hardware-trigger mode. Resolved MSMF vs DSHOW index mismatch by aggressively broadcasting the `CAP_PROP_AUTOFOCUS` UVC command to all available MSMF endpoints (0-9) instead of relying on PyGrabber's DSHOW mapping. Increased camera mode-switch timeout from 500ms to 1.5s in `camera_manager.py`. Increased USB bus stabilization pause in `setup_tab.py` from 0.3s to 1.0s to prevent USB controller bandwidth/power spikes when massive frame bursts start.
- **2026-08-19 (v1.3.0):** Fixed the root cause of the 4th camera failing in trigger mode and causing UVC driver hangs. Removed the `120fps` USB bandwidth hack in `setup_tab.py` which artificially reserved too much USB bandwidth during DSHOW initialization. This failed bandwidth allocation caused the 4th camera to enter a "zombie" state, breaking MSMF UVC resets and causing the reset button to hang. Cameras now correctly request their true `target_fps` during PyAV initialization.
- **2026-08-19 (v1.3.1):** Added physical frame rotation and a live rotation preview thumbnail to `export_tab.py`. The exporter now physically rotates the raw MJPEG frames before H.264 encoding to guarantee perfect portrait output for FreeMoCap without relying on flaky MP4 metadata tags. Fixed a bug where `av.VideoFrame.from_ndarray` stripped original PTS timing during rotation, ensuring perfect frame timing.
- **2026-08-19 (v1.3.2):** Removed the "Kameras Zurücksetzen (UVC Wakeup)" button from `setup_tab.py` and the `reset_uvc_drivers` function from `camera_manager.py`. The feature was causing severe application deadlocks via OpenCV `VideoCapture` when attempting to reset cameras that were already in a faulty hardware-trigger state. Standard initialization remains robust enough for normal use.
- **2026-08-22 (v1.4.0):** Implemented dedicated `freemocap_bridge.py` standalone module and One-Click FreeMoCap integration. **`freemocap_bridge.py`**: Auto-detects `~/freemocap_data`, creates standard FreeMoCap session structures (`recording_sessions/session_.../synchronized_videos/`), transfers videos via instant NTFS zero-copy hardlinks (with fallback to copy), updates `most_recent_recording.toml`, and launches FreeMoCap in a detached process. Supports CLI usage (`--take`, `--launch`). **`export_tab.py`**: Added `[ 🚀 Convert & Send to FreeMoCap ]` one-click button alongside standard MP4 conversion, supporting both unconverted AVIs and pre-converted MP4s. Updated `README.md` to accurately document FreeMoCap folder structure requirements.

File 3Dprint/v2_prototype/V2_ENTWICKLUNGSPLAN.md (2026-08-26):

# MoCapSTR V2 Prototyp: Schlankes All-in-One Cat7 System (10m)

> **Status:** Entwicklungsplan & Bauanleitung für den V2-Prototyp  
> **Ziel:** Zusammenführung von USB 2.0 High-Speed (480 Mbit/s) und Hardware-Trigger (FSIN) in **ein einziges Cat7/Cat6a-Kabel (bis 10m)** pro Kamera.  
> **Ersetzt:** Das 2-Kabel-System aus V1 (separates USB-Kabel zum PC + XLR/DC-Triggerkabel zur Splitter-Box).  
> **Skalierbarkeit:** Basisaufbau für 4 Kameras, modular erweiterbar auf 6, 8 oder 12+ Kameras.

---

## 1. Systemübersicht & Funktionsweise

```
                       [ PC ] (PCIe-Karte mit dedizierten USB-Controllern)
                         │ (4x USB-A Kabel)
                         ▼
┌──────────────────────────────────────────────────────────────────┐
│                   MoCapSTR V2 MASTER-BOX                         │
│                                                                  │
│  [Arduino Nano]    ──> Trigger-Puls (Pin D2) über 33Ω Dämpfung   │
│                        an alle Ports (optional 74HCT125 Buffer)  │
│  [Taster Pin D4]   ──> Start/Stop Record-Steuerung               │
│  [4x USB vom PC]   ──> Liefert 5V Bus-Power & Daten für jeden Port│
│  [4x RJ45 / EtherCON geschirmt]                                  │
└───────┬──────────────────┬──────────────────┬──────────────────┬─┘
        │ Port 1           │ Port 2           │ Port 3           │ Port 4
        │ (10m Cat7)       │ (10m Cat7)       │ (10m Cat7)       │ (10m Cat7)
        ▼                  ▼                  ▼                  ▼
┌─────────────────┐ ┌─────────────────┐ ┌─────────────────┐ ┌─────────────────┐
│ KAMERA 1        │ │ KAMERA 2        │ │ KAMERA 3        │ │ KAMERA 4        │
│ - EtherCON / D  │ │ - EtherCON / D  │ │ - EtherCON / D  │ │ - EtherCON / D  │
│ - FE1.1s Hub    │ │ - FE1.1s Hub    │ │ - FE1.1s Hub    │ │ - FE1.1s Hub    │
│ - 100µF + 100nF │ │ - 100µF + 100nF │ │ - 100µF + 100nF │ │ - 100µF + 100nF │
│ - Innomaker     │ │ - Innomaker     │ │ - Innomaker     │ │ - Innomaker     │
│   OV9281 Sensor │ │   OV9281 Sensor │ │   OV9281 Sensor │ │   OV9281 Sensor │
└─────────────────┘ └─────────────────┘ └─────────────────┘ └─────────────────┘
```

### Entwicklungs- & Teststrategie:
1. **Stufe 1 (Passiver Direkttest):** 
   * D+/D- Adern des 10m Cat7-Kabels zunächst direkt an die Innomaker OV9281 anlöten (ohne Hub-Modul).
   * Dank AWG 23 Kupferquerschnitt und PiMF-Einzelschirmung reicht das bei vielen PCIe-Controllern bereits für stabile 120 FPS.
2. **Stufe 2 (Re-Clocker bei Bedarf):** 
   * Sollten bei 10m Übertragungsfehler oder Resets auftreten, wird das kleine **FE1.1s Hub-Modul** als aktiver Signalauffrischer direkt vor die Kamera gesetzt.

---

## 2. Stückliste (Bill of Materials)

### A. Kameragehäuse (`Cam-BACK-V2`)
*Mengenangaben gelten **pro Kamera**:*

| Bauteil | Bezeichnung / Spezifikation | Bezugsquelle / Suchbegriff | Ca.-Preis |
| :--- | :--- | :--- | :--- |
| **Kamera-Modul** | Innomaker OV9281 Global Shutter USB | Aus V1 | *(vorhanden)* |
| **RJ45 Buchse** | Geschirmte RJ45 D-Typ Einbaubuchse (z. B. Neutrik EtherCON) | `Neutrik NE8FDP` / `RJ45 Panel Mount` | ~4 - 9 € |
| **USB-Hub Modul** | FE1.1s oder CH334P Mini USB 2.0 Hub | `FE1.1s USB Hub Module 4 Port Mini` | ~3 € |
| **Pufferkondensator (LF)**| 1x 100 µF / 16V (oder 25V) Elektrolytkondensator radial | Standard Elko | ~0,15 € |
| **Entstörkondensator (HF)**| 1x 100 nF (0,1 µF) Keramikkondensator (MLCC) | Standard Kerko 50V (RM 2.54 / 5.08) | ~0,05 € |
| **Trigger-Kabel** | JST 1.25mm 2-Pin Buchse mit Litzen (für FSIN Header) | `JST 1.25mm 2-pin cable` | ~0,30 € |
| **Lochrasterplatine**| Punktraster FR4 ca. 25 × 35 mm (optional zur Verdrahtung) | Lochraster FR4 | ~1,50 € |

> [!NOTE]
> **Kondensator-Kombination:**
> - Der **100 µF Elko** puffert Lastwechsel bei Streaming-Start ab.
> - Der **100 nF Keramikkondensator** (parallel geschaltet) besitzt minimale Eigeninduktivität und blockt hochfrequente Störspitzen der kamerainternen Schaltregler.

---

### B. Zentrale Master-Box (`Master_Case-V2`)
*Wird **einmal** für das Gesamtsystem aufgebaut (ausgelegt für 4 Ports, modular erweiterbar):*

| Bauteil | Bezeichnung / Spezifikation | Bezugsquelle / Suchbegriff | Ca.-Preis |
| :--- | :--- | :--- | :--- |
| **Mikrocontroller**| Arduino Nano V3 (CH340 oder FTDI) | Aus V1 | *(vorhanden)* |
| **RJ45 Buchsen** | 4x Geschirmte RJ45 D-Typ Einbaubuchsen (z. B. Neutrik EtherCON) | `Neutrik NE8FDP` | ~16,00 - 32,00 € |
| **Dämpfungswiderstände**| 4x 33 Ω bis 47 Ω Metallschicht (1/4 W) | 33R / 47R Widerstand | ~0,20 € |
| **USB-Zuleitungen**| 4x USB-A Kabel zum PC (0,5m – 1m) | Aus V1 / Standard | *(vorhanden)* |
| **Start/Stop Taster**| 12mm Drucktaster (Schließer / NO) | Aus V1 | ~1,00 € |
| **Status-LED** *(opt.)*| 1x 3mm/5mm LED (Trigger aktiv) + 1x 1 kΩ Widerstand | Standard | ~0,20 € |
| **Puffer-IC** *(opt. >4 Cams)*| 1x 74HCT125 oder 74ACT541 Logiktreiber | `74HCT125 DIP` | ~0,50 € |

---

### C. Verbindungskabel
* **1 bis 4 Stück:** Standard **Cat6a oder Cat7 S/FTP Patchkabel (7m bis 10m)** mit geschirmten Metall-RJ45-Steckern.

---

## 3. RJ45 Pinbelegung (T568B Standard)

Ausnutzung der 4 geschirmten Adernpaare (PiMF):

| RJ45 Pin | Aderfarbe (T568B) | Signal | Funktion & Verbindung |
| :---: | :--- | :--- | :--- |
| **1** | ⚪/🟠 Weiß-Orange | **USB D+** | USB 2.0 High-Speed Datenpaar $\rightarrow$ FE1.1s Upstream D+ |
| **2** | 🟠 Orange | **USB D-** | USB 2.0 High-Speed Datenpaar $\rightarrow$ FE1.1s Upstream D- |
| **3** | ⚪/🟢 Weiß-Grün | **Trigger Signal** | 5V Impuls vom Arduino Pin D2 (über 33–47 Ω) $\rightarrow$ OV9281 FSIN Pin |
| **4** | 🔵 Blau | **USB +5V (1/2)** | 5V Bus-Power vom PC-USB-Kabel (Ader 1 von 2) |
| **5** | ⚪/🔵 Weiß-Blau | **USB +5V (2/2)** | 5V Bus-Power vom PC-USB-Kabel (Ader 2 von 2) |
| **6** | 🟢 Grün | **Trigger GND** | Trigger-Masse vom Arduino $\rightarrow$ OV9281 FSIN GND |
| **7** | ⚪/🟤 Weiß-Braun | **USB GND (1/2)** | Masse vom PC-USB-Kabel (Ader 1 von 2) |
| **8** | 🟤 Braun | **USB GND (2/2)** | Masse vom PC-USB-Kabel (Ader 2 von 2) |
| **Gehäuse** | Metallschirm | **Shield** | Schirmung durchgehend mit PC-USB-Schirm verbunden |

---

## 4. Schaltpläne

### A. Kamera-Modul (`Cam-BACK-V2`)

```
RJ45 / EtherCON Buchse (Kamera)
══════════════════════════════

PIN 4 (Blau) ──────┬───> [+5V Schiene] ───────┬───> FE1.1s Hub [5V IN]
PIN 5 (Weiß-Blau) ─┘                          │
                                              ├───> Innomaker OV9281 [USB 5V]
                                              │
                                           [100µF Elko]  ──┐ (Parallel an 5V/GND,
                                           [100nF Kerko] ──┘  nah am Sensor)
                                              │
PIN 7 (Weiß-Braun) ─┬──> [GND Schiene] ───────┼───> FE1.1s Hub [GND]
PIN 8 (Braun) ──────┘                         │
                                              └───> Innomaker OV9281 [USB GND]

USB-DATEN:
PIN 1 (Weiß-Orange) ──────────────────────────────> FE1.1s Hub [Upstream D+]
PIN 2 (Orange) ───────────────────────────────────> FE1.1s Hub [Upstream D-]

FE1.1s Hub [Downstream D+] ───────────────────────> Innomaker OV9281 [USB D+] (< 3 cm)
FE1.1s Hub [Downstream D-] ───────────────────────> Innomaker OV9281 [USB D-] (< 3 cm)

TRIGGER:
PIN 3 (Weiß-Grün) ────────────────────────────────> Innomaker OV9281 [FSIN Pin 1 (Signal)]
PIN 6 (Grün) ─────────────────────────────────────> Innomaker OV9281 [FSIN Pin 2 (GND)]
```

---

### B. Master-Box (`Master_Case-V2`)

```
[ Arduino Nano ]
  Pin D2 (Trigger) ───┬──[33Ω Widerstand]──> RJ45 Port 1 Pin 3 (Trigger Signal)
                      ├──[33Ω Widerstand]──> RJ45 Port 2 Pin 3 (Trigger Signal)
                      ├──[33Ω Widerstand]──> RJ45 Port 3 Pin 3 (Trigger Signal)
                      └──[33Ω Widerstand]──> RJ45 Port 4 Pin 3 (Trigger Signal)

  Arduino GND ────────┬─────────────────────> RJ45 Port 1 Pin 6 (Trigger GND)
                      ├─────────────────────> RJ45 Port 2 Pin 6 (Trigger GND)
                      ├─────────────────────> RJ45 Port 3 Pin 6 (Trigger GND)
                      └─────────────────────> RJ45 Port 4 Pin 6 (Trigger GND)

  Pin D4 (Taster) ────> 12mm Taster (schaltet gegen GND, interner INPUT_PULLUP)

[ 4x USB-A Kabel zum PC / PCIe-Karte ]
  USB 1 (+5V, Rot)     ───> RJ45 Port 1 Pin 4 & Pin 5
  USB 1 (GND, Schwarz) ───> RJ45 Port 1 Pin 7 & Pin 8
  USB 1 (D+, Grün)     ───> RJ45 Port 1 Pin 1 (D+)
  USB 1 (D-, Weiß)     ───> RJ45 Port 1 Pin 2 (D-)
  USB 1 (Schirm)       ───> RJ45 Port 1 Metallgehäuse / Schirm

  *(Gleicher Aufbau für Ports 2, 3 und 4)*
```

---

## 5. Aufbauanleitung

### Phase 1: Kamera-Modul (`Cam-BACK-V2`)
1. **Hub vorbereiten:** Litzen für 5V, GND, D+, D- an die Upstream-Pads des FE1.1s löten. D+/D- verdrillen und kurz halten (< 15 mm).
2. **RJ45 verbinden:**
   * Pin 1 (D+) & Pin 2 (D-) an FE1.1s Upstream.
   * Pin 4 & 5 (+5V) an FE1.1s 5V und OV9281 5V.
   * Pin 7 & 8 (GND) an FE1.1s GND und OV9281 GND.
   * 100 µF Elko und 100 nF Keramikkondensator parallel zwischen 5V und GND setzen.
3. **Kamera & Trigger:**
   * FE1.1s Downstream-Port mit D+/D- der OV9281 verbinden.
   * Pin 3 (Signal) und Pin 6 (GND) über JST 1.25mm Kabel an den FSIN-Header der Kamera stecken.

---

### Phase 2: Master-Box (`Master_Case-V2`)
1. **Arduino & Taster montieren:**
   * Arduino Nano im Gehäuse fixieren.
   * 12mm Taster an **Pin D4** und **GND** anschließen.
2. **Trigger verdrahten:**
   * Von **Pin D2** 4 Abzweige mit je einem **33 Ω bis 47 Ω Widerstand** in Reihe an Pin 3 der Buchsen 1–4 führen.
   * Arduino GND an Pin 6 aller Buchsen legen.
3. **USB-Zuleitungen:**
   * 4 USB-Kabel abisolieren und Adern (5V, GND, D+, D-, Schirm) direkt an die zugehörigen Pins der 4 RJ45-Buchsen anlöten.

---

## 6. Skalierbarkeit (> 4 Kameras)

### A. USB-Bandbreite
* Jede Kamera arbeitet als eigener USB-Endpunkt über ihr eigenes Cat7-Kabel.
* Bei 120 FPS @ 1280x800 benötigt jede Kamera ~80–100 Mbit/s.
* Das System skaliert linear durch Einsatz von PCIe-Karten mit mehreren dedizierten Host-Controllern (z. B. Quad-Controller PCIe-Karten).

### B. Trigger-Signal
* **Bis 4 Kameras:** Direkte Ansteuerung über Pin D2 mit den 33–47 Ω Schutzwiderständen.
* **Ab 6–12+ Kameras:** Um die zunehmende Leitungskapazität (ca. 450 pF pro 10m Kabel) zu treiben, wird ein Standard-Bustreiber (z. B. **74HCT125** oder **74ACT541**) zwischen Arduino Pin D2 und die Vorwiderstände gesetzt. Dies garantiert auch bei vielen parallelen Kabeln steile Flanken ohne Jitter.

---

## 7. Inbetriebnahme & Tests

- [ ] **Test 1 (Durchgang & Kurzschluss):**
  * Multimeter-Messung zwischen 5V (Pin 4/5) und GND (Pin 7/8) vor dem Einstecken.
- [ ] **Test 2 (USB-Erkennung über 10m):**
  * Port 1 per Cat7 verbinden. Im Geräte-Manager prüfen: FE1.1s Hub und OV9281 Kamera werden fehlerfrei erkannt.
- [ ] **Test 3 (Streaming-Stabilität):**
  * Test-Skript (`tests_hardware/test_trigger_pyav.py` oder `python/main.py`) mit 1280x800 @ 120 FPS starten und auf Framedrops prüfen.
- [ ] **Test 4 (Hardware-Trigger):**
  * Taster betätigen und synchrone Bildauslösung aller Kameras verifizieren.

---

## 8. Gehäusehinweise (FreeCAD / 3D-Druck)

1. **`Cam-BACK-V2.FCStd`:**
   * Ausschnitt für die Neutrik EtherCON / RJ45 D-Typ Einbaubuchse (24 mm Lochkreis mit 2x M3 Befestigungslöchern).
   * Haltestege für FE1.1s Modul und Kondensatoren.
2. **`Master_Case-V2.FCStd`:**
   * Gehäuseaufnahme für Arduino Nano, 4x Neutrik EtherCON Buchsen, 4x Kabelauslässe und 12mm Taster.

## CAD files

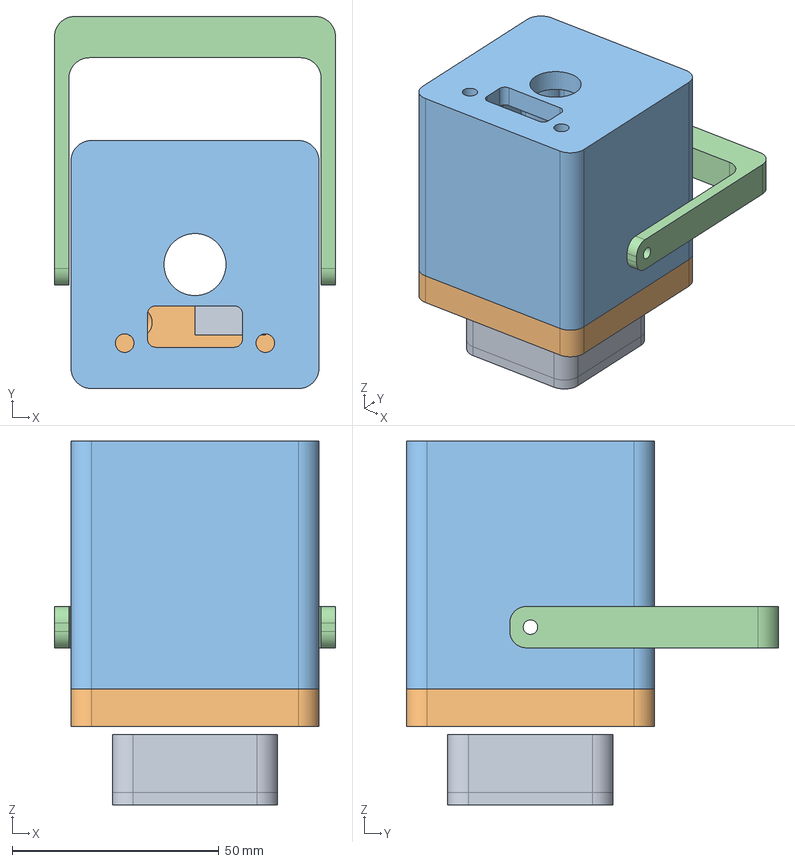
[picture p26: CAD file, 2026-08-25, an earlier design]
3Dprint/v1_prototype/OV9281_Case.FCStd
68.0 x 90.0 x 88.0 mm
Cam Front
Cam Mid
Cam Back
Cam Bracket

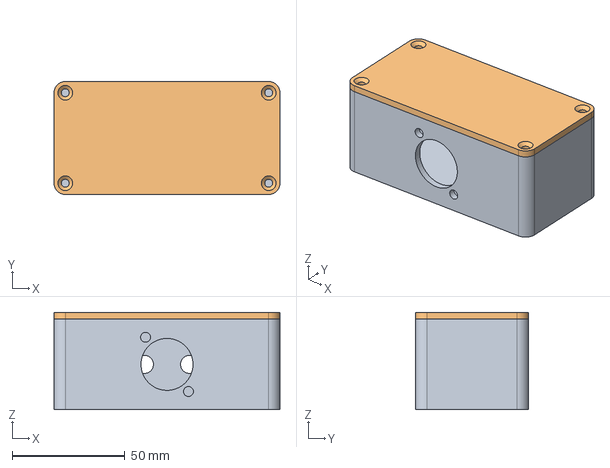
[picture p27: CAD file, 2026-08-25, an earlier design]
3Dprint/v1_prototype/Splitter_Case.FCStd
100.0 x 50.0 x 43.0 mm
Splitter_BASE
Splitter_LID

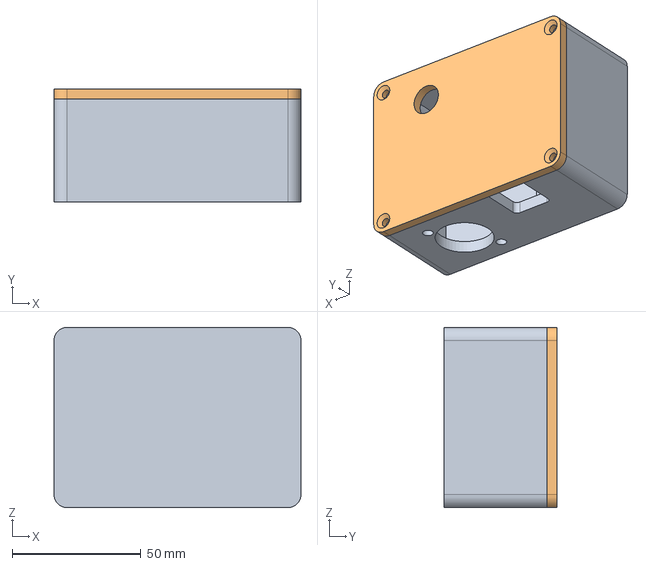
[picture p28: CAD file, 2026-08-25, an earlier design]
3Dprint/v1_prototype/Trigger_Case.FCStd
96.0 x 44.0 x 70.0 mm
Trigger_Case-BASE
Trigger_Case-LID

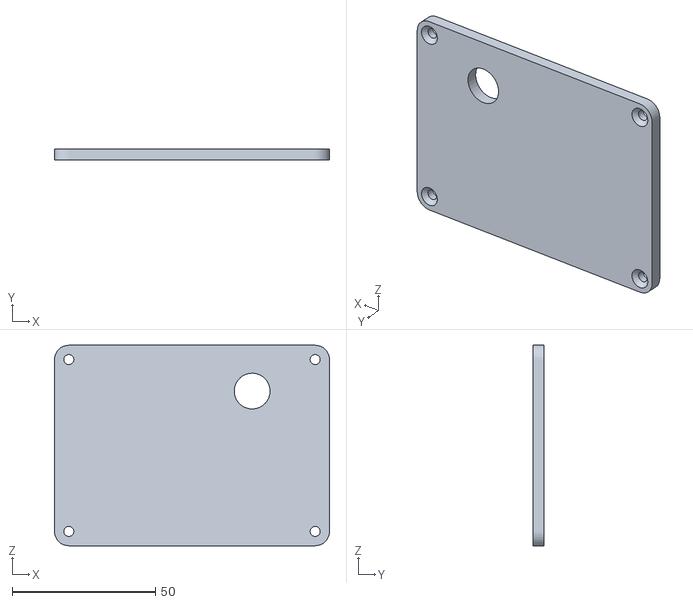
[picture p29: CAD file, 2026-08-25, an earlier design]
3Dprint/v1_prototype/Trigger_Case-LID.stl
96.0 x 4.00 x 70.0

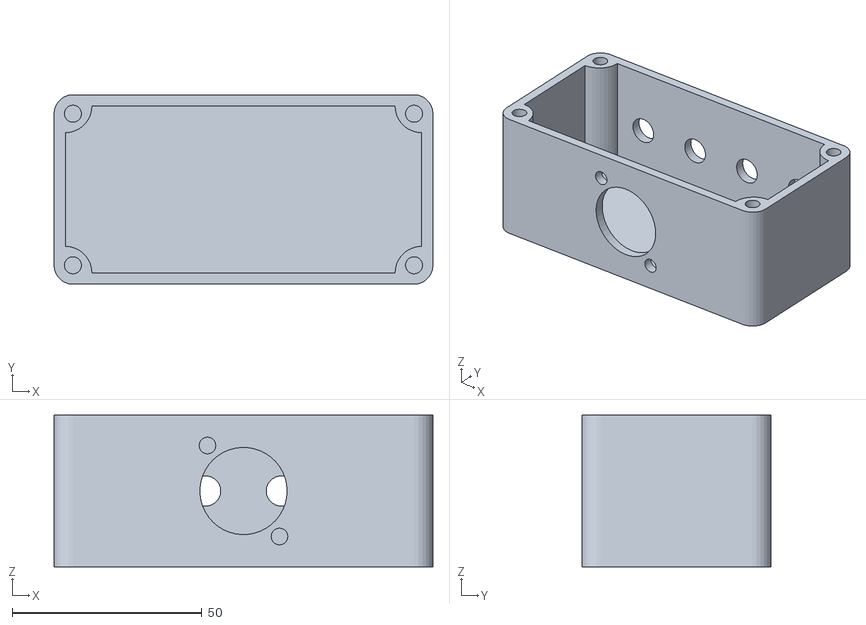
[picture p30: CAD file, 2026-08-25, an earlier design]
3Dprint/v1_prototype/Splitter_Case-BASE.stl
100.0 x 50.0 x 40.0

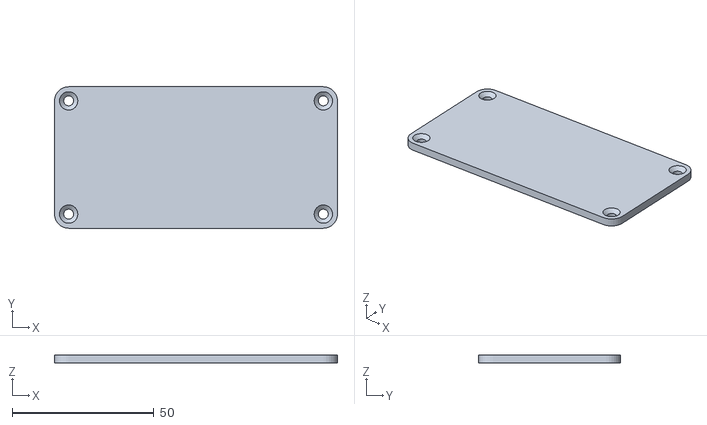
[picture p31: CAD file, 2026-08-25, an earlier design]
3Dprint/v1_prototype/Splitter_Case-LID.stl
100.0 x 50.0 x 3.00

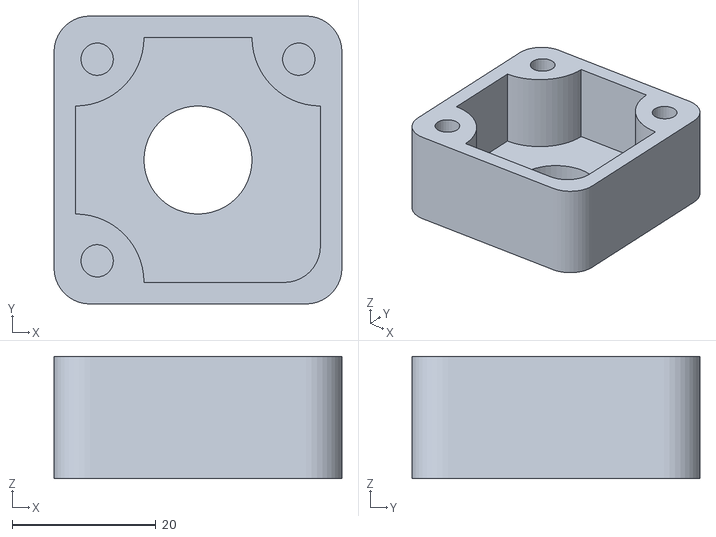
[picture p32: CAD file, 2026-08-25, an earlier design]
3Dprint/v1_prototype/OV9281_Case_Cam-FRONT.stl
40.0 x 40.0 x 17.0

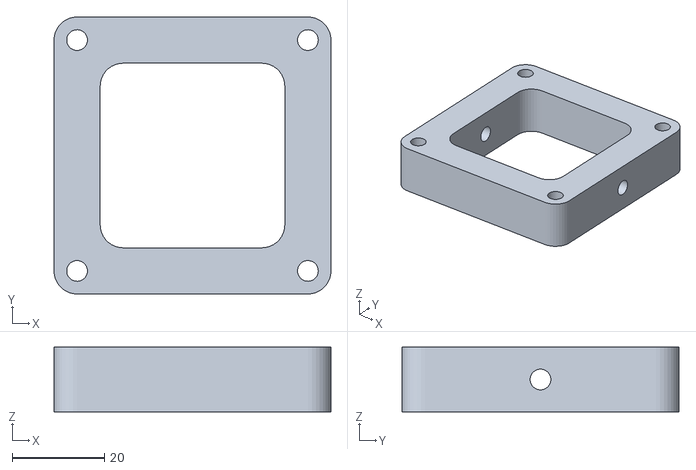
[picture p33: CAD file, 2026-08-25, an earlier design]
3Dprint/v1_prototype/OV9281_Case_Cam-BACK-SHORT.stl
60.0 x 60.0 x 14.0

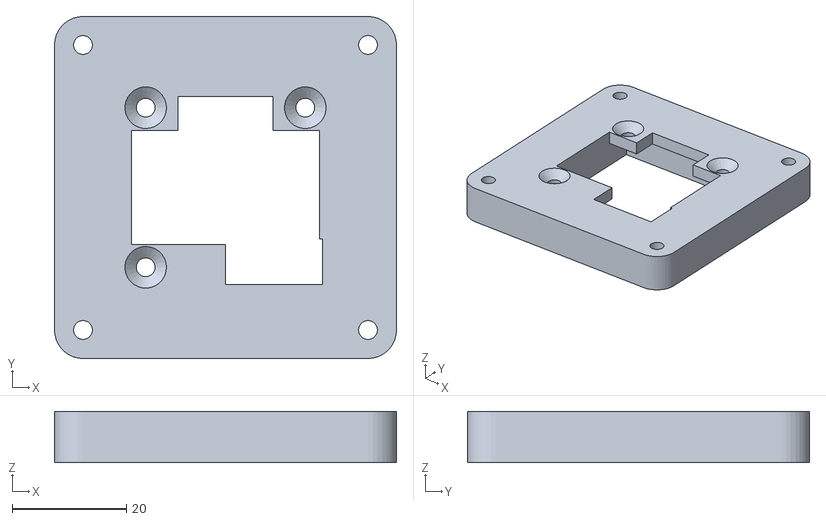
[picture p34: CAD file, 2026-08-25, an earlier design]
3Dprint/v1_prototype/OV9281_Case_Cam-MID.stl
60.0 x 60.0 x 9.00

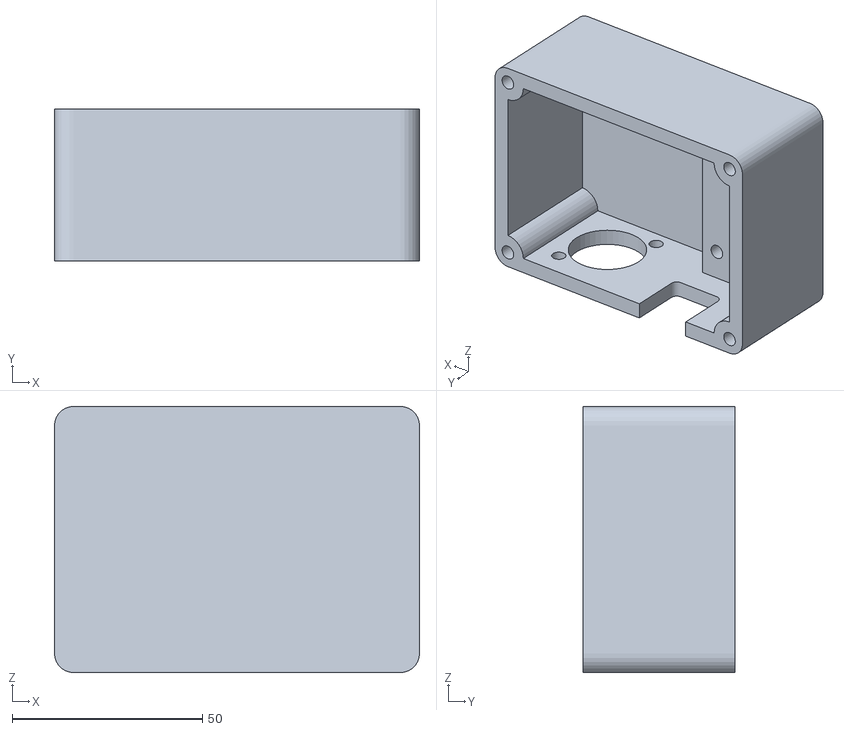
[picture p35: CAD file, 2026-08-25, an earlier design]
3Dprint/v1_prototype/Trigger_Case-BASE.stl
96.0 x 40.0 x 70.0

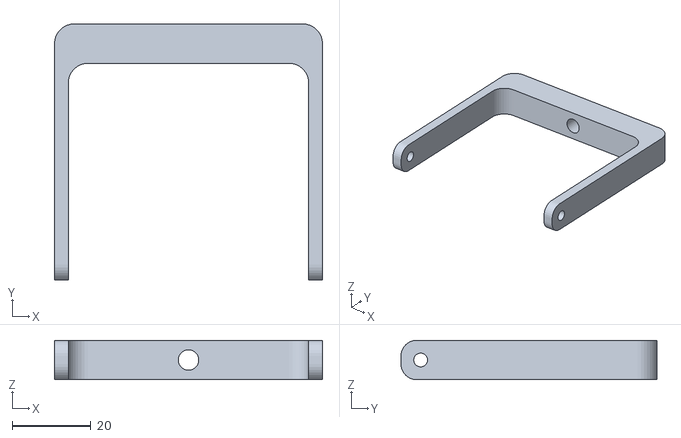
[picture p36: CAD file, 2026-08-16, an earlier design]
3Dprint/v1_prototype/OV9281_Case_Cam-BRACKET.stl
68.0 x 65.0 x 10.0

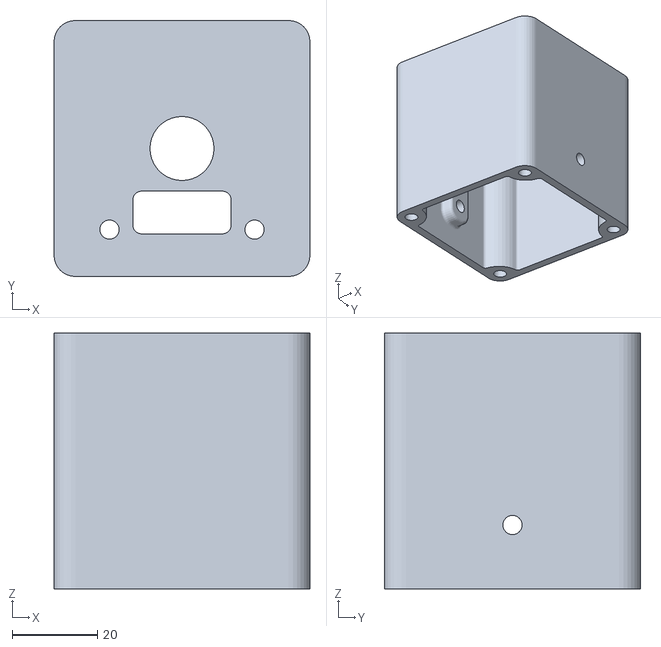
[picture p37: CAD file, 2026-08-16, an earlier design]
3Dprint/v1_prototype/OV9281_Case_Cam-BACK-LONG.stl
60.0 x 60.0 x 60.0

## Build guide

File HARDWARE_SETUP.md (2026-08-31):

# Hardware Setup & Wiring Guide

This document describes the wiring of the MoCapSTR hardware trigger via an XLR splitter box, based on the Arduino sync module and Innomaker OV9281 cameras.

> **3D Printing & Assembly Guide:** Complete CAD source files (`.FCStd`), 3D printable files (`.stl`), and a full step-by-step photo assembly guide are in the [3Dprint & Assembly Guide](3Dprint/README.md).

## The Concept: XLR Splitter

Instead of running long wires directly from the Arduino to each individual camera, the 5V square wave trigger signal from the Arduino is sent through a single XLR microphone cable to a central splitter box on set. From this box, the final cables branch out to the 4 cameras.

<p align="center">
  Connected Hardware Setup
  <br>
  <em>Arduino Trigger Box (right, with blue USB cable to PC) connected via standard XLR cable to the Splitter Box (left, distributing to 4 camera DC cables).</em>
</p>

Since the trigger signal is unbalanced (consisting only of signal and ground), we adapt the 3-pin XLR pinout accordingly.

---

## Hardware Bill of Materials (BOM) - V1 Prototype

To build the complete hardware system (V1), you will need the following standard components in addition to the [3D printed parts](3Dprint/README.md):

**3D Printed Enclosures:**
- **1x Arduino Trigger Case:** ([`Trigger_Case-BASE.stl`](3Dprint/v1_prototype/Trigger_Case-BASE.stl), [`Trigger_Case-LID.stl`](3Dprint/v1_prototype/Trigger_Case-LID.stl))
- **1x XLR Splitter Box:** ([`Splitter_Case-BASE.stl`](3Dprint/v1_prototype/Splitter_Case-BASE.stl), [`Splitter_Case-LID.stl`](3Dprint/v1_prototype/Splitter_Case-LID.stl))
- **4x Camera Enclosures:** ([Front](3Dprint/v1_prototype/OV9281_Case_Cam-FRONT.stl), [Mid](3Dprint/v1_prototype/OV9281_Case_Cam-MID.stl), [Back Short](3Dprint/v1_prototype/OV9281_Case_Cam-BACK-SHORT.stl) or [Back Long](3Dprint/v1_prototype/OV9281_Case_Cam-BACK-LONG.stl), and [Tripod Bracket](3Dprint/v1_prototype/OV9281_Case_Cam-BRACKET.stl))

**Electronics & Cables:**
- 1x Arduino (e.g., Nano) with Terminal Block Shield adapter board for solderless wiring.
- 1x Neutrik XLR Chassis Connector (Male, D-Series dimensions) for the Arduino box.
- 1x Neutrik XLR Chassis Connector (Female, D-Series dimensions) for the splitter box.
- 1x Push-Button (Normally Open / NO) for the Arduino box lid (12mm mounting hole).
- 1x DC Barrel Jack for optional external power supply on the Arduino box (8mm mounting hole, standard 5.5x2.1mm).
- 4x DC Barrel Jacks for the splitter box outputs (8mm mounting holes).
- 2x 5-pin Cage Clamp Terminals (WAGO 221 or similar) to bundle splitter box connections.
- 4x Innomaker OV9281 USB global-shutter camera modules *(supports up to 120 FPS in free-run; tested maximum 50 FPS in hardware-trigger mode due to USB bridge firmware lockout)*.
- 4x 2-Pin Micro Plugs (e.g. JST 1.25mm 2-pin) to plug trigger lines cleanly onto the camera board's FSIN pins.
- **Recommended Host PC USB PCIe Card (for 4+ Cameras):** **StarTech 4-Port USB 3.0 PCIe Card (Model: `P5Q4A-USB-CARD`)** — features 4 independent controller channels (1 dedicated host controller chip per port), completely eliminating motherboard USB bandwidth saturation and packet collisions.

**Mechanics & Fasteners:**
- **Trigger Box:** 8x M3 10mm screws, 8x M3 brass heat-set inserts.
- **Splitter Box:** 6x M3 10mm screws, 6x M3 brass heat-set inserts.
- **Per Camera:** 7x M3 15mm screws, 2x M3 thumbscrews (10–25mm), 9x M3 brass heat-set inserts.
- 1/4"-20 UNC Hand Tap (to cut standard tripod threads into the camera brackets).

---

## 1. Arduino Enclosure (Transmitter)

<p align="center">
  Arduino Trigger Case Internal Wiring
  &nbsp;&nbsp;&nbsp;&nbsp;
  Arduino Trigger Case Assembled
</p>

The Arduino enclosure houses a push-button in the top lid and a male XLR connector in the base.

### Push-Button (Remote Control)
The button is mounted on the top lid and utilizes the Arduino's internal `INPUT_PULLUP` function.
- **Start/Stop Record Button:** Connects Arduino **Pin 4** to Arduino **GND**.
*(This button sends a command to the software. The cameras receive the hardware trigger continuously as long as the system is initialized.)*

### XLR Connector (Output to Splitter Box)
- **XLR Pin 1 (Ground/Shield):** Connect to Arduino **GND**.
- **XLR Pin 2 (Signal Hot):** Connect to Arduino **Pin 2**.
- **XLR Pin 3 (Signal Cold):** Bridge with XLR Pin 1 (Ground).

---

## 2. The Splitter Box (Distributor)

<p align="center">
  XLR Splitter Box Internal Wiring
  &nbsp;&nbsp;&nbsp;&nbsp;
  XLR Splitter Box Rear DC Jacks
</p>

The splitter box features a female XLR input and distributes the signal to 4 cable strands leading to the cameras via DC barrel jacks.

### Internal Wiring (Inside the Box):
1. **The Signal (Hot):** The incoming signal from **XLR Pin 2** goes into the first 5-pin cage clamp terminal and connects to the **four positive / center pins** of the DC jacks.
2. **The Ground (GND):** The incoming ground from **XLR Pin 1** goes into the second 5-pin cage clamp terminal and connects to the **four negative / outer sleeves** of the DC jacks.
3. **The Shielding of the Cables:** The braided shielding is connected to **XLR Pin 1 (Ground)** as well.

*(Pin 3 of the XLR input connector can simply be bridged with Pin 1 or left empty).*

---

## 3. Connecting to the Cameras (Innomaker)

<p align="center">
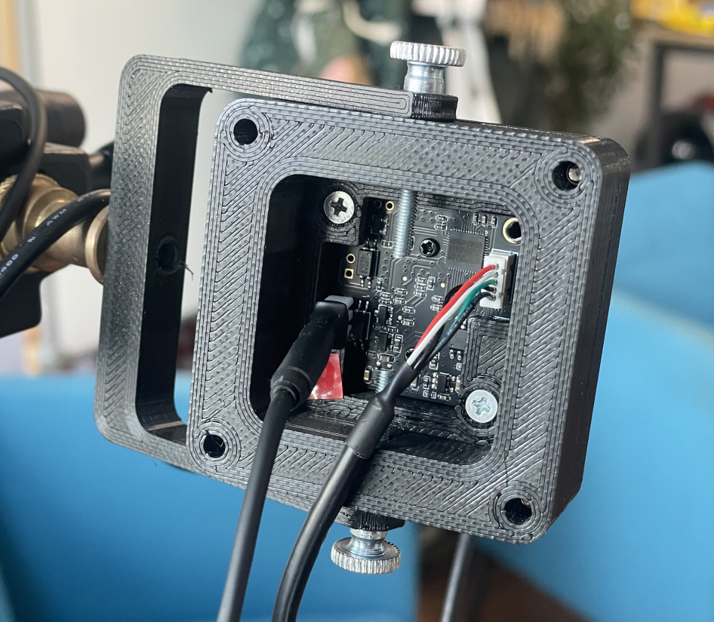
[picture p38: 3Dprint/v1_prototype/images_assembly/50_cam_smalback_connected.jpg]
OV9281 Camera Open Back Connected
  
  &nbsp;&nbsp;&nbsp;&nbsp;
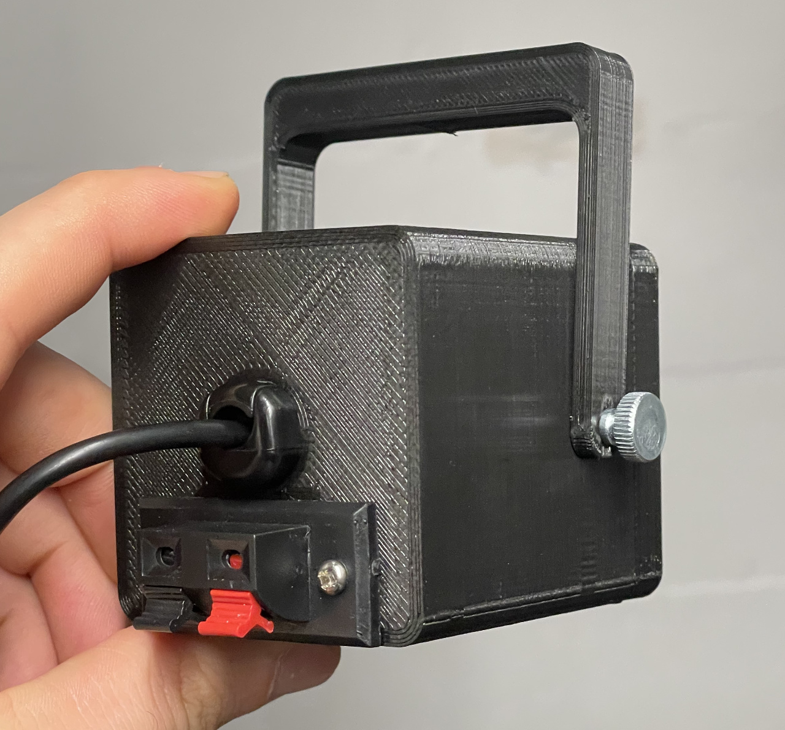
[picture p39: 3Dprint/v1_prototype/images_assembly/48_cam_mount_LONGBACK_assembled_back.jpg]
OV9281 Camera Long Back with Terminal
  
</p>

The four cables from the splitter box are connected to the cameras. We use single-ended shield grounding to avoid ground loops!

- **Red Wire (Signal):** Connect to the **FSIN +** pin of the camera (or to the red spring terminal clip on `Cam-BACK-LONG`).
- **White/Black Wire (Ground):** Connect to the **FSIN -** pin of the camera (or to the black spring terminal clip on `Cam-BACK-LONG`).
- **Connector Tip:** Standard **2-pin micro connectors (e.g., JST 1.25mm 2-pin)** fit directly onto the camera PCB's FSIN pins for a secure, detachable connection.
- **Shielding (Braid):** Cut flush and insulate thoroughly! The shielding must **NOT** be connected to the camera or touch any metal parts on the camera side.

*Reason:* The shielding acts as a Faraday cage, catching electromagnetic interference along the cable run and safely draining it via the splitter box and XLR cable into the Arduino's ground. If connected on both ends, stray currents could flow through the cable.

> [!TIP]
> **Modular 90° Orientation (Portrait vs. Landscape):**
> Thanks to the symmetrical square 4-screw layout between `Cam-MID` and the back cover, you can easily change the camera from Landscape (horizontal) to Portrait (vertical) orientation. Simply loosen the 4 corner screws on the back cover, rotate the back cover 90°, and screw it back down. This allows you to orient the cameras vertically to maximize vertical capture resolution for standing actors.

---

## Cable & USB Recommendations

- **Trigger Cable (Splitter to Cameras):** A 2-core shielded audio cable (e.g., `2x 0.08 mm²` or DMX control cable) is ideal for the run from the splitter box to the cameras.
- **XLR Cable (Arduino to Splitter):** Standard 3-pin XLR microphone cable.
- **Host PC USB Expansion Card:** **StarTech `P5Q4A-USB-CARD` (4-Port PCIe)** — Verified for 4-camera hardware-sync capture without bandwidth bottlenecks.

---

## Troubleshooting & Hardware Diagnostics

### Camera is Frozen on a Single Frame (`0.0 FPS` / `⚠️ NO SIGNAL / FROZEN`)
If a camera opens during initialization with a single initial frame but remains frozen at `0.0 FPS` while the other cameras stream smoothly at 25/30 FPS:
1. **Free-Run Test:** In the MoCapSTR software (Setup tab), uncheck `[ ] Enable UVC Hardware Trigger` and initialize. If all cameras stream live in Free-Run, your USB card, cable, and driver are fine — the fault is **100% in the physical trigger connection**.
2. **Check Splitter Box Terminals:** Open the splitter box and check whether the WAGO cage clamp terminal or DC connector wire for that specific camera is loose or disconnected.
3. **Verify `FSIN+` / `FSIN-` Polarity:** The camera input diode requires correct polarity (Red = `FSIN+`, Black = `FSIN-` / Ground). If reversed, trigger pulses cannot trigger the sensor.
4. **Cross-Test Ports:** Swap the DC barrel jack of the faulty camera with a working camera at the splitter box to quickly isolate whether the cable or splitter output is broken.

---
---

# Deutsche Version

Dieses Dokument beschreibt die Verkabelung des MoCapSTR Hardware-Triggers über eine XLR-Splitter-Box, basierend auf dem Arduino-Sync-Modul und Innomaker OV9281 Kameras.

> **3D-Druck & Montageanleitung:** Vollständige CAD-Quelldateien (`.FCStd`), druckbare Dateien (`.stl`) sowie eine bebilderte Schritt-für-Schritt-Montageanleitung befinden sich im [3D-Druck- & Montage-Guide](3Dprint/README.md).

## Das Prinzip: XLR-Splitter

Anstatt lange Kabel direkt vom Arduino zu jeder Kamera zu ziehen, wird das 5V-Rechtecksignal des Arduinos über ein XLR-Mikrofonkabel zu einer zentralen Splitter-Box am Set geführt. Von dieser Box gehen dann die Endkabel zu den 4 Kameras. 

<p align="center">
  Gesamtaufbau Trigger und Splitter Box
  <br>
  <em>Arduino Trigger-Gehäuse über handelsübliches XLR-Kabel mit der Splitter-Box verbunden, von der 4 DC-Kabel zu den Kameras abzweigen.</em>
</p>

Da das Trigger-Signal asymmetrisch ("unbalanced") ist (bestehend aus Signal und Masse), passen wir die 3-polige XLR-Belegung entsprechend an.

---

## Hardware Komponentenliste (BOM) - V1 Prototype

Für den Nachbau des Gesamtsystems (V1) werden neben den [3D-Druckteilen](3Dprint/README.md) folgende Standard-Bauteile benötigt:

**3D-Druck-Gehäuse:**
- **1x Arduino Trigger-Gehäuse:** ([`Trigger_Case-BASE.stl`](3Dprint/v1_prototype/Trigger_Case-BASE.stl), [`Trigger_Case-LID.stl`](3Dprint/v1_prototype/Trigger_Case-LID.stl))
- **1x XLR Splitter-Box:** ([`Splitter_Case-BASE.stl`](3Dprint/v1_prototype/Splitter_Case-BASE.stl), [`Splitter_Case-LID.stl`](3Dprint/v1_prototype/Splitter_Case-LID.stl))
- **4x Kamera-Gehäuse:** ([Front](3Dprint/v1_prototype/OV9281_Case_Cam-FRONT.stl), [Mittelteil](3Dprint/v1_prototype/OV9281_Case_Cam-MID.stl), [Rückteil Kurz](3Dprint/v1_prototype/OV9281_Case_Cam-BACK-SHORT.stl) oder [Rückteil Lang](3Dprint/v1_prototype/OV9281_Case_Cam-BACK-LONG.stl) sowie [Stativbügel](3Dprint/v1_prototype/OV9281_Case_Cam-BRACKET.stl))

**Elektronik & Kabel:**
- 1x Arduino (z.B. Nano) inkl. Schraubklemmen-Shield (Terminal Block Shield) für einfache, lötfreie Verkabelung.
- 1x Neutrik XLR Einbaubuchse (Männlich, D-Serie Maß) für das Arduino-Gehäuse.
- 1x Neutrik XLR Einbaubuchse (Weiblich, D-Serie Maß) für die Splitter-Box.
- 1x Push-Button (Drucktaster, Schließer) für den Gehäusedeckel (12mm Einbaudurchmesser).
- 1x Hohlstecker-Buchse (DC Barrel Jack) zur optionalen Stromversorgung am Arduino (8mm Einbaudurchmesser, Standard 5.5x2.1mm).
- 4x Hohlstecker-Buchsen für die Splitter-Box Ausgänge (8mm Einbaudurchmesser).
- 2x 5-polige Käfigzugklemmen (z. B. WAGO 221) zum Zusammenführen der Signal- und Masseleitungen in der Splitter-Box.
- 4x Innomaker OV9281 USB Global-Shutter Kameramodule *(unterstützt bis zu 120 FPS im Free-Run; getestetes Maximum im Hardware-Trigger-Modus liegt bei 50 FPS durch die Bridge-Firmware)*.
- 4x 2-Pin Mikro-Steckverbinder (z. B. JST 1.25mm 2-Pin), um die Triggerkabel direkt und steckbar auf die FSIN-Pins der Kameraplatinen zu stecken.
- **Empfohlene Host-PC USB-PCIe-Erweiterungskarte (für 4+ Kameras):** **StarTech 4-Port USB 3.0 PCIe-Karte (Modell: `P5Q4A-USB-CARD`)** — verfügt über 4 getrennte Controller-Kanäle (1 dedizierter Controller-Chip pro Port), wodurch Bandbreiten-Engpässe und Paketkollisionen vollständig vermieden werden.

**Mechanik & Schrauben:**
- **Trigger-Box:** 8x M3 10mm Schrauben, 8x M3 Einschmelzgewinde.
- **Splitter-Box:** 6x M3 10mm Schrauben, 6x M3 Einschmelzgewinde.
- **Pro Kamera:** 7x M3 15mm Schrauben, 2x M3 Rändelschrauben (10–25mm), 9x M3 Einschmelzgewinde.
- 1/4"-20 UNC Gewindeschneider (um Standard-Stativgewinde in die Kamerabügel zu schneiden).

---

## 1. Arduino Gehäuse (Sender)

<p align="center">
  Arduino Trigger Gehäuse Innenverkabelung
  &nbsp;&nbsp;&nbsp;&nbsp;
  Arduino Trigger Gehäuse Fertig
</p>

Am Gehäuse des Arduinos werden ein Taster im Deckel und eine XLR-Buchse (Männlich) im Unterteil verbaut.

### Taster (Fernbedienung)
Der Taster sitzt im Deckel und nutzt die interne `INPUT_PULLUP` Funktion des Arduinos.
- **Start/Stop Record Button:** Verbindet Arduino **Pin 4** mit Arduino **GND**.
*(Dieser Taster sendet einen Befehl an die Software. Die Kameras erhalten dauerhaft das Trigger-Signal, wenn der Modus aktiv ist.)*

### XLR-Buchse (Ausgang zur Splitter-Box)
- **XLR Pin 1 (Masse/Schirm):** Mit Arduino **GND** verbinden.
- **XLR Pin 2 (Signal Hot):** Mit Arduino **Pin 2**.
- **XLR Pin 3 (Signal Cold):** Brücken mit XLR Pin 1 (Masse).

---

## 2. Die Splitter-Box (Verteiler)

<p align="center">
  XLR Splitter-Box Innenverkabelung
  &nbsp;&nbsp;&nbsp;&nbsp;
  XLR Splitter-Box Rückansicht
</p>

Die Splitter-Box hat einen XLR-Eingang (Weiblich) und gibt das Signal über 4 DC-Hohlbuchsen an die 4 Kamerakabel weiter.

### Interne Verdrahtung in der Box:
1. **Das Signal (Hot):** Das ankommende Signal von **XLR Pin 2** wird über eine 5er-Käfigzugklemme auf die **vier roten Adern / Mittelkontakte** der DC-Buchsen verteilt. 
2. **Die Masse (GND):** Die ankommende Masse von **XLR Pin 1** wird über eine zweite 5er-Käfigzugklemme auf die **vier schwarzen Adern / Außenkontakte** der DC-Buchsen verteilt.
3. **Die Schirmung der Kabel:** Das Drahtgeflecht wird ebenfalls an **XLR Pin 1 (Ground)** angeschlossen.

*(Pin 3 der XLR-Eingangsbuchse kann hier einfach mit Pin 1 gebrückt werden oder leer bleiben).*

---

## 3. Anschluss an die Kameras (Innomaker)

<p align="center">
  OV9281 Kamera Rückseite Verkabelung (Open Back)
  &nbsp;&nbsp;&nbsp;&nbsp;
  OV9281 Kamera Rückseite mit Klemmenterminal (Long Back)
</p>

Die vier Kabel kommen von der Splitter-Box an den Kameras an. Wir nutzen die einseitige Schirmerdung, um Brummschleifen (Ground Loops) zu vermeiden!

- **Rote Ader (Signal):** Anschließen an den **FSIN +** Pin der Kamera (bzw. an das rote Klemmterminal bei `Cam-BACK-LONG`).
- **Weiße/Schwarze Ader (Masse):** Anschließen an den **FSIN -** Pin der Kamera (bzw. an das schwarze Klemmterminal bei `Cam-BACK-LONG`).
- **Stecker-Tipp:** Kleine **2-Pin-Steckverbinder (z. B. JST 1.25mm 2-Pin)** passen perfekt auf die beiden FSIN-Stifte der Platine für eine saubere, steckbare Verbindung.
- **Schirmung (Drahtgeflecht):** Bündig abschneiden und gut isolieren! Die Schirmung darf an der Kamera **NICHT** angeschlossen werden oder Metall berühren. 

*Grund:* Die Schirmung fängt elektromagnetische Störungen auf der gesamten Strecke auf und leitet sie über die Splitter-Box und das XLR-Kabel sicher in den Ground des Arduinos ab (Faradayscher Käfig). Wäre sie auf beiden Seiten angeschlossen, könnten Störströme durch das Kabel fließen.

> [!TIP]
> **Modulare 90°-Drehung (Hochkant vs. Querformat):**
> Dank des quadratischen 4-Schrauben-Lochmusters zwischen `Cam-MID` und dem Rückteil kannst du entscheiden, ob die Kamera horizontal (Querformat) oder vertikal (Hochkant / 90° gedreht) am Stativbügel montiert sein soll. Einfach die 4 Schrauben des Rückteils lösen, das Rückteil um 90° drehen und wieder festschrauben. So lässt sich das Bild optimal an stehende Darsteller anpassen.

---

## Kabel- & USB-Empfehlungen

- **Trigger-Kabel (Splitter zu Kameras):** Ein 2-adriges, geschirmtes Audiokabel (z. B. `2x 0.08 mm²` oder DMX-Steuerkabel) ist ideal für die Strecke von der Splitter-Box zu den Kameras.
- **XLR-Kabel (Arduino zu Splitter):** Jedes handelsübliche 3-polige XLR-Mikrofonkabel.
- **USB-PCIe-Erweiterungskarte:** **StarTech `P5Q4A-USB-CARD` (4-Port PCIe)** — Getestet und verifiziert für den synchronen Betrieb von 4 InnoMaker OV9281 Kameras. Verhindert Bandbreiten-Staus zuverlässig durch 4 separate Controller-Chips.

---

## Fehlerbehebung & Hardware-Diagnose (Troubleshooting)

### Kamera zeigt ein Standbild bei `0.0 FPS` (`⚠️ NO SIGNAL / FROZEN`)
Wenn eine Kamera beim Initialisieren ein einziges Standbild liefert, danach aber mit `0.0 FPS` und rotem Warn-Overlay einfriert (während die anderen Kameras flüssig laufen):
1. **Free-Run-Gegenprobe:** Deaktiviere in MoCapSTR (Setup-Tab) das Häkchen `[ ] Enable UVC Hardware Trigger` und klicke auf Initialisieren. Wenn die Kamera im Free-Run flüssig läuft, sind USB-Karte, Kabel und Treiber zu 100 % in Ordnung – der Fehler liegt **ausschließlich an der physischen Trigger-Leitung**.
2. **Klemmen in der Splitter-Box prüfen:** Öffne die Splitter-Box und prüfe, ob die WAGO-Klemme oder die Lötverbindung zur DC-Buchse der betroffenen Kamera lose ist oder herausgerutscht ist.
3. **Polarität an der Kamera prüfen (`FSIN+` / `FSIN-`):** Die Eingangsschutzdiode des OV9281-Moduls erfordert zwingend die korrekte Polarität (Rot = `FSIN+`, Schwarz = `FSIN-` / Masse). Bei vertauschten Adern blockiert die Diode und der Sensor erhält keine Pulse.
4. **Kreuztest an der Splitter-Box:** Stecke den DC-Hohlstecker der betroffenen Kamera an der Splitter-Box in einen funktionierenden Ausgang um, um sofort zu sehen, ob das Kabel oder die Splitter-Buchse die Ursache ist.

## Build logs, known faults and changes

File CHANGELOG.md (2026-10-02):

# Changelog

**Current Status:** v1.5.2 in development. Visible log again plus log file, settings that survive a restart, small fixes; v1.5.1 records straight into FreeMoCap 2; v1.5.0 brought frame-accurate clip verification & repair, robust Arduino monitoring and one-click firmware flashing.
**Last Modified:** 2026-10-02

---

- **2026-10-02 (v1.5.2, in development):** **Robustness & comfort (no hardware changes)**:
  - **Bug fix – no visible log:** The log textbox was removed in the UI overhaul (commit `46cccf1`); since then every `app.log()` message (firmware warnings, clip verification, export results, errors) only went to `print()` – invisible in the EXE. New log panel below the tabs, visible in every tab: colour-coded, timestamps, collapsible, "Log-Ordner öffnen".
  - **Thread-safe logging:** Messages from worker threads (initialization, export, firmware flashing) are queued and shown by the Tk main thread instead of touching widgets from other threads.
  - **Log file:** `%LOCALAPPDATA%\MoCapSTR\logs\mocapstr.log` (rotating, 5×5 MB) captures `print()` output, stderr and uncaught exceptions (threads and UI callbacks).
  - **Settings location:** `presets.json` and `export_settings.json` were written to the current working directory, so their location depended on how the EXE was started. They now live in `%APPDATA%\MoCapSTR`; existing files are copied over once.
  - **Remembers the last session:** project name, save folder, take name, setup values, Arduino port, ChArUco settings and camera rotations are restored at start (saved on exit and on every recording start). Presets and session use the same code.
  - **Bug fix – pop-out/dock and re-init reset the preview:** "Enable Recording" checkboxes and rotation menus are kept; remembered rotations are applied to newly started cameras.
  - **Bug fix – camera tester:** identically named cameras were always tested as the first camera (`video_device_number` missing).
  - **Bug fix – export:** a failed conversion left the source file open (could not be moved/deleted afterwards, WinError 32).
  - **Bug fix – inconsistent FPS defaults:** invalid FPS input fell back to 30 in some places and 50 in others; now validated (1–240) with 50 as the single default. Presets without FPS/USB polling load 50/Auto.
  - **Bug fix – ChArUco "Squares X/Y"** fields were displayed as Y x X.
  - **Cleanup:** removed unused `apply_settings()`, `get_frame()`, `get_stalled_cameras()`.
  - **CI:** GitHub Actions run the hardware-free test suite (Windows, Python 3.10 and 3.13). Verified locally: Python 3.10–3.13 and PyAV 12.0–18.0.

- **2026-10-02 (v1.5.1, in development):** **FreeMoCap 2 integration (verified against FreeMoCap v2.0.0-alpha.25)**:
  - **Records straight into FreeMoCap 2:** The default save location is FreeMoCap's `recordings/` folder (`~/freemocap_data/recordings`, or the data folder chosen in FreeMoCap's settings, read from `%APPDATA%/freemocap/freemocap-config.json`). Each take and each calibration is its own recording folder `<date>_<time>_<project>_<take>/synchronized_videos/`, so recordings appear in FreeMoCap without any export step and calibrations no longer overwrite each other. `session_info.json` now stores project, take and recording type; the Export tab finds a project's recordings through it (recordings of v1.5.0 and older are still found).
  - **Timestamps in FreeMoCap format:** Per-camera CSVs moved to `synchronized_videos/timestamps/` with the columns FreeMoCap 2 reads: `timestamp_s` for playback and `from_previous.framerate.hz`, from which FreeMoCap derives the real frame rate for its post-processing filter (otherwise it assumes 30 FPS). A CSV with the wrong columns in that folder would crash FreeMoCap's pipeline - covered by a test that replicates FreeMoCap's parsers.
  - **Export tab:** Finds `.avi` and `.mkv`. FreeMoCap 2 reads raw MJPEG files directly, so conversion to `.mp4` is optional; "Open in FreeMoCap" only converts cameras that need a rotation. After a conversion the original is moved to `original_videos/` (or deleted), because FreeMoCap counts every video in `synchronized_videos/` as a camera.
  - **Bug fix – "Send to FreeMoCap":** It wrote the wrong key into `most_recent_recording.toml` (FreeMoCap 1.x), and in the EXE `sys.executable` is MoCapSTR itself, so trying to launch FreeMoCap started another MoCapSTR instance. The bridge now targets FreeMoCap 2: it launches the installed `FreeMoCap.exe` and, for recordings stored elsewhere, copies (hard-links) exactly one video per camera plus timestamps into FreeMoCap's folder.
  - **Single instance:** Starting MoCapSTR a second time no longer kills the running instance (and every Python process with `main.py` in its command line). A dialog asks first; only the exact process recorded in the instance PID file is ended, and only on "Yes".
  - **Build:** Removed unused `screeninfo` hidden import from `MoCapSTR.spec`.
  - **Docs:** Blackmagic SDI mode marked as currently broken in the README (it fails since the PyAV switch: PyAV has no `decklink` input, plus an `UnboundLocalError`). Restoration plan and decisions in `BLACKMAGIC_SDI_PLAN.md` (planned for v2.0).

- **2026-10-02 (v1.5.0, in development):** **Sync Reliability: every clip starts on the same pulse, ends on the same pulse and has the same length**:
  - **Bug fix – clip trimming never worked:** `trim_clips_to_min_frames()` wrote to `camX.avi.trimming.tmp`; PyAV picks the muxer from the file extension and failed with `Could not determine output format`. The error was swallowed and the UI still reported "Clips synchronized". Trimming is replaced by `clip_sync.finalize_clips()` (see below).
  - **New `clip_sync.py` – post-recording verification:** After every take, all clips are checked using per-frame timestamps. Frames a camera never delivered (gap in the DirectShow sample time) are filled with a copy of the previous frame when the evidence is unambiguous (missing frames == frame deficit vs. the longest clip, hardware-trigger mode only). Only then, as a last resort, clips are trimmed to equal length. All findings are written to the UI log instead of the (invisible in the EXE) console.
  - **Per-frame timestamps:** Every take now contains `timestamps/camX_timestamps.csv` (`frame_index, arrival_ns, device_time_s, filler`).
  - **Lost frames keep their slot:** Packets dropped because the write queue was full, or that failed to mux, are replaced by a copy of the previous frame instead of silently shifting every following frame.
  - **Stale frames at start:** In hardware-trigger mode, recording is held until the trigger has been restarted; packets that arrive before the first new pulse can have been exposed are discarded, so frame 0 is the same pulse on every camera.
  - **Recorder:** One `RecordingSession` object per take; the writer thread closes its own files, so a slow writer can no longer be cut off (old 2 s join timeout) or write into the next take. All cameras stop at the same moment and drain in parallel.
  - **Bug fix – MKV frame rate:** `.mkv` recordings were tagged as 24 FPS (no `rate` on the output stream), which OpenCV/FreeMoCap read as the clip FPS.
  - **Bug fix – false "ARDUINO DISCONNECTED":** The PING check depended on the UI tick rate and permanently stopped the serial reader thread on a single late PONG. The app then skipped the trigger stop/restart around recordings without notice. Now pings are time-based (1 s); a missing PONG only shows a warning, and the trigger box counts as disconnected only on a real serial port error.
  - **Bug fix – sync warning with disabled cameras:** The frame delta now only compares cameras that take part in the recording.
  - **`trigger_firmware.ino` (re-flash required):** Commands sent in quick succession are no longer merged (previously e.g. `<START>` after `<FPS:50>` could be lost). Pulse width uses a `micros()` loop (accurate beyond 16 ms). No burst of catch-up pulses after a delayed loop. New `<VERSION>` command; the app warns if the flashed firmware is outdated.
  - **One-click firmware flashing (no Arduino IDE needed):** New "Firmware aufspielen" button in the Setup tab. The pre-built `trigger_firmware.hex` is bundled with the app and written via the Nano/Uno serial bootloader (`firmware_flasher.py`, STK500v1 over pyserial; Optiboot 115200 and old Nano bootloader 57600 are detected automatically, every page is verified). The button is highlighted when the connected firmware is missing or outdated. `arduino/build_firmware.py` rebuilds the HEX with arduino-cli; a unit test fails if `.hex` and `.ino` versions differ. Verified on an Arduino Nano clone (CH340, Optiboot): fresh board, update from v1.4.8 and repeated flashing; the old-bootloader (57600 baud) path is covered by the simulated-bootloader tests only.
  - **Misc:** "Initialize System" is blocked while recording; unknown free disk space no longer auto-stops a recording.
  - **Tests:** New hardware-free test suite (`python -m unittest discover tests`) covering trimming, gap detection/repair, the writer and the recording pipeline with simulated cameras.

- **2026-08-31 (v1.4.8):** Version bump to v1.4.8. **InnoMaker OV9281 Trigger Characterization, Smart Auto USB Polling & UI Clean-up**:
  - **Empirical Hardware Trigger Characterization (50 FPS Physical Limit)**:
    - Conducted rigorous multi-frequency sweep benchmark testing on InnoMaker OV9281 UVC camera modules.
    - Proved mathematically that while Free-Run mode easily streams at 120 FPS, the on-board USB bridge ISP firmware has a fixed non-overlapping state-machine lockout window of $\approx 18\text{–}20\text{ ms}$ per triggered frame (independent of resolution, 1280x720 and 640x400 both exhibit this lockout).
    - Verified exact harmonic sub-rates when exceeding the lockout: 50 Hz $\rightarrow$ 50 FPS (1:1), 60 Hz $\rightarrow$ 30 FPS (1:2), 90 Hz $\rightarrow$ 45 FPS (1:2), 120 Hz $\rightarrow$ 40 FPS (1:3).
    - Established **50 FPS @ 1280x720 (720p HD)** with Global Shutter and 1ms exposure as the verified optimal performance sweet-spot for 4-camera hardware synchronization.
  - **`setup_tab.py` - Smart Auto USB Polling**:
    - Introduced `"Auto"` as default USB Polling mode. In Hardware Trigger mode, `"Auto"` requests the maximum 120 FPS UVC stream to completely eliminate beat-frequency host polling collisions (e.g. 15 FPS on 30p), while matching target FPS in Free-Run mode.
    - Preserved manual overrides (`120`, `90`, `60`, `30`) for future camera boards with constrained USB 2.0/3.0 bandwidth or lower max framerates.
  - **`setup_tab.py` - UI Warning Clean-up**:
    - Removed all hardcoded 18ms text and intrusive red warning blocks.
    - Replaced exposure clamping with pure physics validation ($\text{shutter\_time} > \frac{1}{\text{target\_fps}}$), showing a subtle note only if exposure duration exceeds 1 complete frame interval.
    - Polling warning only alerts if manual polling rate is strictly lower than target FPS (silent on `Auto`).
    - Set optimal UI defaults: Target FPS = `50`, USB Polling = `Auto`, Exposure = `-9` (1/512s).
  - **`tests_hardware/`**:
    - Added [`test_trigger_fps_live.py`](file:///e:/GitHub%20Projekte/MoCapSTR/tests_hardware/test_trigger_fps_live.py): Interactive OpenCV live monitor with real-time microsecond delta-t measurements, keyboard shortcuts for live FPS switching (`1`..`6`), pulse width cycling (`P`), polling modes (`U`), resolution toggling (`R`), and exposure adjustments (`E`).
    - Added [`test_trigger_fps_optimizer.py`](file:///e:/GitHub%20Projekte/MoCapSTR/tests_hardware/test_trigger_fps_optimizer.py): Automated timing matrix and packet arrival benchmark tool.
  - **`main.py`**: Updated window title to v1.4.8.
  - **`setup_tab.py` & `camera_manager.py`**: Implemented the deterministic 10-step Golden State Machine for hardware initialization & settings re-application: (1) Quiesce hardware by stopping Arduino trigger, (2) Reset cameras to Free-Run (`AutoFocus=0`), (3) Drain and cleanly stop previous PyAV worker threads, (4) Close PyAV container handles, (5) Enforce Windows DirectShow COM & USB bus settling delay (`time.sleep(0.3)` + `gc.collect()`), (6) Auto-connect Arduino, (7) Set DirectShow UVC Exposure & Gain in Free-Run and open PyAV streams (0s latency negotiation), (8) Engage Hardware Trigger (`AutoFocus=1`), (9) Start PyAV background workers, (10) Start Arduino pulse generation. Eliminates USB endpoint collisions, DirectShow COM deadlocks, and sensor state machine corruption when updating exposure on 4-camera InnoMaker setups.
  - **`recorder.py` & `preview_tab.py`**: Decoupled rotation and preview rendering in `PreviewWorker`. Caches the latest raw unrotated frame (`raw_frame`) and adds `apply_rotation_to_cached_frame()`. Changing rotation dropdowns in the UI now re-renders and rotates the displayed preview immediately without waiting for a new packet from USB.
  - **`recorder.py` & `main.py`**: Added stream-stall watchdog timestamp `last_packet_time` to `CameraWorker`. If an active camera stops delivering packets for $> 2.0$ seconds while the hardware trigger is active, the UI tile immediately displays a prominent red warning overlay (`⚠️ NO SIGNAL / FROZEN (0.0 FPS)`).
  - **`main.py`**: Updated window title to v1.4.7.

- **2026-08-27 (v1.4.6):** Version bump to v1.4.6. **Intelligent USB Polling Recommendation, Trigger FPS Preservation & Compact UI**:
  - **`setup_tab.py`**: Added `get_recommended_usb_fps()` utility function to calculate physics-accurate USB polling rates ($\ge 60$ FPS for $\le 50$ FPS target triggers) to eliminate phase-drift/beat-frequency FPS halving (e.g. 15 FPS on 25p). Added real-time warning label (`lbl_usb_warn`) alerting users if a chosen USB polling rate is incompatible with target FPS. Added smart auto-suggestion on Target FPS change while preserving complete manual override freedom. Added default fallback of 60 FPS for legacy presets.
  - **`setup_tab.py`**: Converted `SetupTab` from `CTkScrollableFrame` to clean `CTkFrame`, eliminating the unused right scrollbar and preventing scrolling into blank space now that all elements fit cleanly on screen.
  - **`main.py`**: Updated window title to v1.4.6.

- **2026-08-27 (v1.4.5):** Version bump to v1.4.5. **Hardware Trigger Diagnostic Tool Overhaul**:
  - **`arduino/test_camera_trigger.py`**: Rewrote diagnostic tool to use lossless single-stream PyAV demuxing for frame measurement instead of multi-threaded `cv2.VideoCapture` `CAP_DSHOW` loops. Fixed zombie thread race conditions on paused trigger states that caused artificially degraded FPS readings (e.g. 3.2 FPS on 10 Hz trigger). Added automatic manual exposure optimization (1/128s) to guarantee accurate 10–60+ FPS hardware trigger validation.

- **2026-08-27 (v1.4.4):** Version bump to v1.4.4. **Media Foundation UVC Property Routing & Watertight Sync Pipeline**:
  - **`camera_manager.py`**: Updated `set_trigger_mode()` to route `CAP_PROP_AUTOFOCUS` and `CAP_PROP_FOCUS` register updates through the Media Foundation provider (`CAP_MSMF`), eliminating exclusive DirectShow capture graph pin lock collisions on running streams.
  - **`camera_manager.py` & `setup_tab.py`**: Hardened two-stage stream opening and trigger pipeline to ensure cameras open in Free-Run (`AutoFocus=0`) mode during format negotiation and transition to Hardware Trigger mode once worker loops are active.
  - **`main.py` & `recorder.py`**: Verified and hardened the atomic recording synchronization pipeline (`toggle_record`), ensuring the 0.15s buffer drain flush and 0.20s end drain maintain frame-accurate alignment across all cameras without dropped frames.

- **2026-08-27 (v1.4.3):** Version bump to v1.4.3. **Two-Stage Hardware Sync & DirectShow Deadlock Fix**:
  - **`camera_manager.py` & `setup_tab.py`**: Resolved camera initialization hang (`Setting USB Webcam format to MJPG...`) when opening in hardware-trigger mode. Implemented a two-stage initialization pipeline: PyAV DirectShow pin negotiation always occurs in Free-Run (`AutoFocus=0`) mode first (guaranteeing sub-second connection without graph lockups), and `AutoFocus=1` hardware trigger is cleanly engaged on the running stream once background workers are active.
  - **`camera_manager.py`**: Replaced fragmented MSMF backend property setting with unified DirectShow (`CAP_DSHOW`) property control (`AUTOFOCUS`, `AUTO_EXPOSURE`, `EXPOSURE`, `GAIN`), eliminating MSMF index capture warnings and COM filter graph contention.
  - **`camera_manager.py` & `main.py`**: Implemented `set_trigger_mode()` and `reset_hardware_trigger_mode()` to ensure cameras are automatically reset to free-run mode (`AutoFocus=0`) on startup and upon application shutdown, preventing physical sensors from remaining stuck in 0-FPS external trigger mode across sessions.
  - **`arduino_sync.py`**: Added proactive disposal of stale serial connection handles in `connect()`, fixing `PermissionError(13, 'Zugriff verweigert')` when reconnecting to Arduino COM ports.
  - **`README.md`**: Added prominent warning banner at the top of the repository clarifying experimental project status.

- **2026-08-26 (v1.4.2):** Version bump to v1.4.2. **Zombie Process Prevention & Camera Lock Elimination**:
  - **`recorder.py`**: Configured `PreviewWorker`, `CameraWorker`, and `writer_thread` as `daemon=True` threads so background streaming loops cannot prevent Python from terminating when the window is closed.
  - **`main.py`**: Added Windows Named Mutex (`Global\MoCapSTR_Application_Singleton_Mutex_v1`) single-instance enforcement and an automatic `cleanup_zombie_instances()` startup routine to automatically terminate any stale background processes from previous crashes or unclosed sessions.
  - **`main.py`**: Hardened `on_closing()` shutdown sequence with `try...finally` resource disposal and immediate `os._exit(0)` to guarantee immediate release of all kernel-level DirectShow and UVC hardware device handles.

- **2026-08-26 (v1.4.1):** Version bump to v1.4.1. **`export_tab.py`**: Added Per-Camera Export Video Rotation. Scanned projects now dynamically display individual rotation dropdowns and live thumbnail previews for each detected camera (`cam0`, `cam1`, `cam2`...). Added `[ 🔄 Sync from Live Preview ]` button to automatically import camera orientations from the Live Preview tab, and `[ Apply to All... ]` for batch assignment. Saved preferences persist in `export_settings.json`. **`setup_tab.py` & `recorder.py`**: Hardened camera initialization with `try...finally` guards to prevent the UI from getting stuck in "Initializing..." on hardware/driver glitches. Added explicit join timeouts to worker thread shutdowns to eliminate stop deadlocks.

- **2026-08-10:** Added top control bar in Live Preview tab including Recording Timer, Frame Counter, Disk Space Warning, and live Dropped Frame detection.
- **2026-08-10:** Implemented `PresetManager` to save/load all UI settings to `presets.json`. Overhauled the Setup Tab UI using `CTkFrame` cards for better grouping.
- **2026-08-10:** Added FreeMoCap specific Charuco Board parameters (Dictionary, Grid, Sizes) and a live `cv2.aruco` detection overlay in the Live Preview tab.
- **2026-08-10:** Implemented Phase 1 of Blackmagic SDI Integration. Added "Camera Type" dropdown to UI to switch between USB and Blackmagic SDI. Modified CameraManager to apply resolution and framerate to DeckLink WDM filters before the first frame read to ensure successful initialization.
- **2026-08-11 (v1.0.4):** Created `CameraTestTab` (Tab 4) to brute-force test camera capabilities. Added Format selector (MJPG / YUY2) to the Setup Tab and `CameraManager`.
- **2026-08-11 (v1.0.5):** Improved `CameraTestTab` by adding a "Scan All" option that reports identical available combinations across all connected cameras.
- **2026-08-11 (v1.1.0):** Major architectural refactor. Replaced `cv2.VideoCapture` with `PyAV` (FFmpeg) in `camera_manager.py` and `recorder.py`. Implemented Zero-Copy stream muxing (direct MJPEG to disk without CPU decoding).
- **2026-08-11 (v1.0.6):** Fixed PyAV frame drops by offloading Charuco and rotation logic to a separate `PreviewWorker` thread. Fixed MKV 1000fps timestamp bug.
- **2026-08-11 (v1.0.7):** Implemented Arduino Software-Integration (Python GUI). Added "Auto-Trigger on Record" logic, automatic FPS matching.
- **2026-08-11 (v1.0.8):** Added FreeMoCap `session_info.json` metadata generation. Implemented Camera Rotation Persistence. Added Watchdog `<PING>` to Arduino.
- **2026-08-11 (v1.0.9):** Added hardware remote control functionality. Rewrote Arduino firmware and `arduino_sync.py` to use asynchronous threading for physical push buttons.
- **2026-08-12:** Hardware documentation & Trigger Fix. Added `CAMERA_SPECS.md` detailing the Innomaker OV9281. Updated `setup_tab.py` to correctly activate the external hardware trigger on these cameras by toggling the UVC `FOCUS` parameter.
- **2026-08-12 (v1.1.0):** Complete UI/UX Overhaul. Rewrote the setup process into a dynamic, top-to-bottom studio workflow. Removed `record_tab.py` entirely.
- **2026-08-12:** Added `arduino/test_hardware.py` standalone diagnostic script and `HARDWARE_SETUP.md` professional XLR Splitter Box wiring guide.
- **2026-08-12 (v1.1.1):** Added new "Export & Convert" tab for offline PyAV transcoding of raw MJPEG to H.264.
- **2026-08-13 (v1.1.2):** Improved Arduino intelligent Auto-Trigger logic. Created `arduino/arduino_test_ui.py` standalone UI tool.
- **2026-08-13 (v1.1.3):** Fixed Innomaker UVC Hardware Trigger integration. Switched `sync_hardware_exposure` to use OpenCV's MSMF backend.
- **2026-08-13 (v1.1.4):** Implemented One-Click System Initialization. Consolidated camera opening and hardware sync into a single robust button in the UI.
- **2026-08-13 (v1.1.5):** Resolved DSHOW/MSMF driver lock issues causing UVC settings to fail or flicker. Separated property application into two phases.
- **2026-08-13 (v1.1.6):** Arduino firmware timing fix to eliminate cumulative drift. Added new `<PULSE:N>` serial command. Setup Tab UX improvements.
- **2026-08-13 (v1.1.7):** Resolved the Hardware Trigger Framerate drop mystery (Targeting 60 yielded 30). Proved via empirical sweeping that the Innomaker OV9281 firmware has a fixed ~18-20ms sensor readout time over USB 2.0 in trigger mode, regardless of requested resolution. This caps the physical hardware trigger limit to strictly 50 FPS. Any trigger faster than 50Hz (e.g. 60Hz) strikes the sensor during readout, corrupting the pipeline and halving the framerate. Fixed UI: removed hard exposure slider clamping in favor of a physics-aware warning label. Fixed Backend: changed `CAP_PROP_AUTO_EXPOSURE` flag to `0.25` to correctly disable Auto-Exposure under Windows DirectShow. Default exposure set to -9 (1/512s) to ensure 50 FPS works out-of-the-box.
- **2026-08-17 (v1.1.8):** Fixed initialization hang on phantom COM ports by adding a `<PING>`/`<PONG>` handshake verification to `arduino_sync.py` during connection. Added graceful fallback to free-run mode if the hardware trigger is requested but no Arduino is verified. Fixed a bug in PyAV camera enumeration where multiple cameras with identical names (e.g. "USB Camera") would fail to open due to missing `video_device_number` parameter in FFmpeg dshow options. Fixed OpenCV hardware sync index logic so exposure/gain settings apply to all identical cameras instead of just the first one.
- **2026-08-17 (v1.1.9):** Added custom program window icon support using `design/Icon.ico`. Configured `main.py` with `sys._MEIPASS` pathing to ensure the icon persists when bundled via PyInstaller.
- **2026-08-17 (v1.2.0):** Fixed a bug in `camera_manager.py` where exposure changes only applied to a subset of identical cameras. MSMF hardware trigger initialization was accidentally resetting DSHOW exposure settings due to Windows enumeration differences. Fixed by separating the initialization into a dedicated MSMF pass for all cameras, followed by a DSHOW pass.
- **2026-08-17 (v1.2.1):** Added filter to ignore virtual cameras (like OBS Virtual Camera) in hardware enumeration to prevent MSMF/DSHOW I/O errors. Removed obsolete 'Auto-Trigger on Record' checkbox from the Setup UI as the trigger now runs continuously for PyAV Live Preview. Changed default target FPS from 50 to 30, and default exposure from -9 (1/512s) to -8 (1/256s) for better out-of-the-box brightness.
- **2026-08-17 (v1.2.2):** Redesigned the "Project & Setup" tab into a cleaner 2-card layout ("Project & Presets" and "Hardware Configuration") using Grid alignment. Removed the manual Gain slider to save space and simplify the interface, hardcoding hardware gain to 0 during initialization.
- **2026-08-17 (v1.2.3):** Documentation overhaul (`README.md`). Fixed a quality degradation issue in `export_tab.py` by lowering the FFmpeg H.264 Constant Rate Factor (CRF) from 23 to 15, ensuring the resulting `.mp4` files are visually lossless compared to the raw MJPEG AVI recordings.
- **2026-08-17 (v1.2.4):** Bug-fix session across multiple files. **`export_tab.py`**: Fixed `AttributeError` crash on "Scan" button — `ProjectManager` has no `current_project_dir()` method; replaced with correct `base_path + current_project` path construction. Fixed AVI scan using non-recursive `glob` that never found files nested inside `takes/take_XYZ/synchronized_videos/`; switched to `glob(..., recursive=True)`. Fixed `TypeError` crash during conversion progress update caused by passing keyword args to `self.after()` — replaced with lambda. Changed FPS fallback from 50 to 30 (consistent with UI default). Added cleanup of incomplete `.mp4` output file when conversion fails mid-stream. **`camera_test_tab.py`**: Added guard to prevent "Run Scan" from silently killing an active recording. **`main.py`**: Fixed FPS fallback 50→30. **`preview_tab.py`**: Fixed lone German UI string "Aufnahme aktiv" → "Enable Recording". **`README.md`**: Restructured as bilingual (English first, German second).
- **2026-08-17 (v1.2.4 Build):** Built standalone onefile executable `MoCapSTR.exe` (and `MoCapSTR 1.2.4.exe`) in `dist/`. Enhanced `design/Icon.ico` with complete multi-resolution icon sizes (16x16 up to 256x256), configured `MoCapSTR.spec` with all CustomTkinter theme assets, PyAV, pygrabber, comtypes, screeninfo, opencv, and pillow dependencies. Verified startup.
- **2026-08-19 (v1.2.5):** Added "Kameras Zurücksetzen (UVC Wakeup)" feature to simulate the OBS driver reset behavior. Implemented `reset_uvc_drivers` in `camera_manager.py` which explicitly clears the `CAP_PROP_AUTOFOCUS` flag to ensure cameras safely leave hardware trigger mode upon reset. Added a prominent yellow UI button in `setup_tab.py` to trigger this async reset.
- **2026-08-19 (v1.2.6):** Implemented frame-exact clip synchronization to fix FreeMoCap import rejection. **Two-phase atomic start**: `MultiCamManager.start_recording()` now separates container preparation (Phase 1, sequential I/O) from recording activation (Phase 2: single `threading.Event.set()` call that arms all cameras simultaneously), eliminating start-of-clip frame drift caused by sequential `is_recording=True` flag setting. **Post-recording trim**: `stop_recording()` now returns `{cam_idx: (path, frames)}` and a new `trim_clips_to_min_frames()` method re-muxes over-long clips to `min_frames` via PyAV stream-copy (lossless, no re-encoding) using atomic `os.replace()`. Trim runs in a background thread in `main.py` so the UI stays responsive. Four bugs fixed: stale `output_path` for non-active workers between sessions, inflated `frames_recorded` counter in transcoding no-op path, gate/is_recording shutdown ordering race, and missing `frames > 0` guard in results collection.
- **2026-08-19 (v1.2.7):** Fixed camera detection in hardware-trigger mode. A camera in trigger mode emits no frames until it receives a pulse, causing the packet-verification loop in `find_and_open_cameras` to block indefinitely and discard the camera. Fix 1: packet verification is now skipped entirely in trigger mode — a successful `av.open()` with a valid video stream is sufficient proof the camera is present. Fix 2: added 500ms sleep after the MSMF trigger-activation pass so all cameras can settle into external-trigger mode before PyAV opens streams. Fix 3: free-run packet probing is capped at 50 packets to prevent hangs on misbehaving cameras. Fix 4: added 300ms pause in `setup_tab.py` after `arduino.start_trigger()` to ensure the first pulse reaches all cameras before stream verification.
- **2026-08-19 (v1.2.8):** Perfect frame alignment for hardware-trigger mode. When recording starts/stops, the Arduino trigger is briefly paused to drain PyAV buffers. This guarantees that all cameras start and end on the exact same frame pulse, resolving FreeMoCap clip length rejection issues.
- **2026-08-19 (v1.2.9):** Fixed missing 4th camera issue in hardware-trigger mode. Resolved MSMF vs DSHOW index mismatch by aggressively broadcasting the `CAP_PROP_AUTOFOCUS` UVC command to all available MSMF endpoints (0-9) instead of relying on PyGrabber's DSHOW mapping. Increased camera mode-switch timeout from 500ms to 1.5s in `camera_manager.py`. Increased USB bus stabilization pause in `setup_tab.py` from 0.3s to 1.0s to prevent USB controller bandwidth/power spikes when massive frame bursts start.
- **2026-08-19 (v1.3.0):** Fixed the root cause of the 4th camera failing in trigger mode and causing UVC driver hangs. Removed the `120fps` USB bandwidth hack in `setup_tab.py` which artificially reserved too much USB bandwidth during DSHOW initialization. This failed bandwidth allocation caused the 4th camera to enter a "zombie" state, breaking MSMF UVC resets and causing the reset button to hang. Cameras now correctly request their true `target_fps` during PyAV initialization.
- **2026-08-19 (v1.3.1):** Added physical frame rotation and a live rotation preview thumbnail to `export_tab.py`. The exporter now physically rotates the raw MJPEG frames before H.264 encoding to guarantee perfect portrait output for FreeMoCap without relying on flaky MP4 metadata tags. Fixed a bug where `av.VideoFrame.from_ndarray` stripped original PTS timing during rotation, ensuring perfect frame timing.
- **2026-08-19 (v1.3.2):** Removed the "Kameras Zurücksetzen (UVC Wakeup)" button from `setup_tab.py` and the `reset_uvc_drivers` function from `camera_manager.py`. The feature was causing severe application deadlocks via OpenCV `VideoCapture` when attempting to reset cameras that were already in a faulty hardware-trigger state. Standard initialization remains robust enough for normal use.
- **2026-08-22 (v1.4.0):** Implemented dedicated `freemocap_bridge.py` standalone module and One-Click FreeMoCap integration. **`freemocap_bridge.py`**: Auto-detects `~/freemocap_data`, creates standard FreeMoCap session structures (`recording_sessions/session_.../synchronized_videos/`), transfers videos via instant NTFS zero-copy hardlinks (with fallback to copy), updates `most_recent_recording.toml`, and launches FreeMoCap in a detached process. Supports CLI usage (`--take`, `--launch`). **`export_tab.py`**: Added `[ 🚀 Convert & Send to FreeMoCap ]` one-click button alongside standard MP4 conversion, supporting both unconverted AVIs and pre-converted MP4s. Updated `README.md` to accurately document FreeMoCap folder structure requirements.

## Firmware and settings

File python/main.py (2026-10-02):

import tkinter as tk
import customtkinter as ctk
import json
import logging
import os
import queue
import sys
import threading
from datetime import datetime
from camera_manager import CameraManager
from arduino_sync import ArduinoSync
from project_manager import ProjectManager
from recorder import MultiCamManager
from clip_sync import finalize_clips
from freemocap_bridge import SESSION_INFO_FILENAME
from preset_manager import PresetManager
from app_paths import data_dir, logs_dir
from logging_setup import log_file_path, setup_logging
from settings_store import SettingsStore
import cv2
from PIL import Image, ImageTk
import time

from tabs.setup_tab import SetupTab
from tabs.preview_tab import PreviewTab
from tabs.camera_test_tab import CameraTestTab
from tabs.export_tab import ExportTab

APP_VERSION = "1.5.2"

ctk.set_appearance_mode("Dark")
ctk.set_default_color_theme("blue")

class MoCapSyncApp(ctk.CTk):
    def __init__(self):
        super().__init__()

        self.title(f"MoCapSTR: Sync / Trigger / Record for FreeMoCap v{APP_VERSION}")
        self.geometry("1100x800")
        
        # Set Window Icon
        try:
            base_path = sys._MEIPASS
        except Exception:
            base_path = os.path.dirname(os.path.dirname(os.path.abspath(__file__)))
            
        icon_path = os.path.join(base_path, "design", "Icon.ico")
        if os.path.exists(icon_path):
            self.iconbitmap(icon_path)
            
        # Managers
        self.cam_mgr = CameraManager()
        self.arduino = ArduinoSync()
        self.arduino.on_toggle_rec_callback = self.handle_remote_toggle_rec
        
        self.proj_mgr = ProjectManager()
        self.recorder = MultiCamManager()
        self.preset_mgr = PresetManager()
        
        self.camera_indices = []
        self.preview_labels = {} # Grid for previews
        self.camera_enable_vars = {} # Stores IntVars for checkboxes
        self.rotation_menus = {}     # cam_idx -> rotation dropdown in the preview grid
        # User choices that must survive rebuilding the preview grid and app restarts
        self.saved_rotations = {}    # str(cam_idx) -> "0°" / "90° (Portrait)" / ...
        self.saved_enabled = {}      # cam_idx -> 1/0 ("Enable Recording")
        self.settings = SettingsStore()

        self.record_start_time = 0
        self.record_fps = 50
        self.record_hardware_trigger = False
        self.ui_tick = 0
        self.last_free_space = None
        self.last_ping_sent = 0.0
        self.arduino_was_connected = False
        self.arduino_unresponsive_logged = False
        self.last_warning_text = ""
        self.txt_log = None
        # app.log() may be called from any thread; only the Tk main thread touches the widget
        self._log_queue = queue.Queue()

        self.build_ui()
        self.load_session_settings()
        self.after(50, self.update_preview) # Start preview loop
        self.after(100, self._drain_log_queue)
        self.log(f"MoCapSTR v{APP_VERSION} started. Log file: {log_file_path()}")

        # Reset any leftover hardware trigger modes on startup in background
        threading.Thread(target=self.cam_mgr.reset_hardware_trigger_mode, daemon=True).start()
        

    def handle_remote_toggle_rec(self):
        self.after(0, self.toggle_record)
        
    def build_ui(self):
        # Log panel at the bottom, visible in every tab (packed first so it keeps its height)
        self.build_log_panel()

        self.tabview = ctk.CTkTabview(self)
        self.tabview.pack(fill="both", expand=True, padx=10, pady=(10, 0))

        self.tab_setup_frame = self.tabview.add("1. Project & Setup")
        self.tab_preview_frame = self.tabview.add("2. Live Preview")
        self.tab_export_frame = self.tabview.add("3. Export & Convert")
        self.tab_test_frame = self.tabview.add("4. Camera Tester")
        
        self.setup_tab = SetupTab(self.tab_setup_frame, self)
        self.setup_tab.pack(fill="both", expand=True)
        
        self.preview_tab = PreviewTab(self.tab_preview_frame, self)
        self.preview_tab.pack(fill="both", expand=True)

        self.test_tab = CameraTestTab(self.tab_test_frame, self)
        self.test_tab.pack(fill="both", expand=True)

        self.export_tab = ExportTab(self.tab_export_frame, self)
        self.export_tab.pack(fill="both", expand=True)

    def build_log_panel(self):
        panel = ctk.CTkFrame(self)
        panel.pack(side="bottom", fill="x", padx=10, pady=(4, 10))

        header = ctk.CTkFrame(panel, fg_color="transparent")
        header.pack(fill="x", padx=8, pady=(4, 0))
        ctk.CTkLabel(header, text="Log", font=ctk.CTkFont(weight="bold")).pack(side="left")
        self.btn_log_toggle = ctk.CTkButton(header, text="▾ Ausblenden", width=110, height=24,
                                            command=self.toggle_log_panel)
        self.btn_log_toggle.pack(side="right")
        ctk.CTkButton(header, text="📄 Log-Ordner öffnen", width=150, height=24,
                      command=lambda: os.startfile(logs_dir())).pack(side="right", padx=(0, 8))

        self.txt_log = ctk.CTkTextbox(panel, height=110, wrap="word")
        self.txt_log.pack(fill="x", padx=8, pady=(4, 8))
        self.txt_log.tag_config("success", foreground="#3ddc84")
        self.txt_log.tag_config("error", foreground="#ff5c5c")
        self.txt_log.tag_config("warning", foreground="#f4a261")
        self.txt_log.configure(state="disabled")

    def toggle_log_panel(self):
        if self.txt_log.winfo_ismapped():
            self.txt_log.pack_forget()
            self.btn_log_toggle.configure(text="▸ Einblenden")
        else:
            self.txt_log.pack(fill="x", padx=8, pady=(4, 8))
            self.btn_log_toggle.configure(text="▾ Ausblenden")

    def report_callback_exception(self, exc_type, exc, tb):
        """Exceptions in Tk callbacks: into the log file and visible in the UI log."""
        logging.getLogger("ui").error("Exception in UI callback", exc_info=(exc_type, exc, tb))
        self.log(f"Unexpected error: {exc_type.__name__}: {exc} (details in the log file)", "error")

    def load_session_settings(self):
        """Restores project, save folder and setup of the last session."""
        data = self.settings.data
        if not data:
            return
        try:
            self.setup_tab.apply_settings(data)
            if data.get("project_name"):
                self.setup_tab.proj_name_entry.delete(0, tk.END)
                self.setup_tab.proj_name_entry.insert(0, data["project_name"])
            if data.get("take_name"):
                self.preview_tab.take_name_entry.delete(0, tk.END)
                self.preview_tab.take_name_entry.insert(0, data["take_name"])
            base_path = data.get("base_path")
            if base_path and os.path.isdir(base_path):
                self.proj_mgr.set_base_path(base_path)
                self.setup_tab.lbl_save_dir.configure(text=base_path)
            elif base_path:
                self.log(f"Last save folder not found ({base_path}) - using {self.proj_mgr.base_path}.", "warning")
        except Exception as e:
            self.log(f"Could not restore the last settings: {e}", "warning")

    def save_session_settings(self):
        try:
            data = self.setup_tab.collect_settings()
            data["project_name"] = self.setup_tab.proj_name_entry.get()
            data["take_name"] = self.preview_tab.take_name_entry.get()
            data["base_path"] = self.proj_mgr.base_path
            self.settings.save(data)
        except Exception as e:
            print(f"[Settings] Could not collect settings: {e}")

    def apply_saved_rotations(self):
        """Applies the remembered rotation to every running camera worker."""
        for idx in self.recorder.workers:
            choice = self.saved_rotations.get(str(idx), "0°")
            self.recorder.set_camera_rotation(idx, int(choice.split('°')[0]))

    def get_free_space(self):
        try:
            import shutil
            total, used, free = shutil.disk_usage(self.proj_mgr.base_path)
            return free // (2**30)
        except Exception:
            return None  # Unknown - must not trigger the low-space auto-stop

    LOG_LEVELS = {"info": logging.INFO, "success": logging.INFO, "warning": logging.WARNING, "error": logging.ERROR}
    MAX_LOG_LINES = 1000

    def log(self, message, level="info"):
        """Thread-safe: writes to the log file immediately, the UI log is updated by the main thread."""
        logging.getLogger("app").log(self.LOG_LEVELS.get(level, logging.INFO), message)
        self._log_queue.put((datetime.now().strftime("%H:%M:%S"), message, level))

    def _drain_log_queue(self):
        try:
            if self.txt_log is not None and not self._log_queue.empty():
                self.txt_log.configure(state="normal")
                while True:
                    try:
                        stamp, message, level = self._log_queue.get_nowait()
                    except queue.Empty:
                        break
                    tag = level if level in ("success", "error", "warning") else None
                    self.txt_log.insert(tk.END, f"{stamp}  {message}\n", tag)
                lines = int(self.txt_log.index("end-1c").split(".")[0])
                if lines > self.MAX_LOG_LINES:
                    self.txt_log.delete("1.0", f"{lines - self.MAX_LOG_LINES}.0")
                self.txt_log.see(tk.END)
                self.txt_log.configure(state="disabled")
        finally:
            self.after(100, self._drain_log_queue)

    def toggle_record(self):
        if not self.recorder.is_recording:
            # START
            proj_name = self.setup_tab.proj_name_entry.get()
            if not proj_name:
                self.log("Error: Enter a project name.", level="error")
                return
                
            self.proj_mgr.set_project(proj_name)
            is_calib = (self.preview_tab.chk_charuco.get() == 1)
            take_name = self.preview_tab.take_name_entry.get()
            save_dir = self.proj_mgr.get_recording_folder(is_calib, take_name)
            
            fps = self.setup_tab.get_target_fps()
            codec = self.setup_tab.codec_combo.get()
            
            enabled_cams = [idx for idx, var in self.camera_enable_vars.items() if var.get() == 1]
            if not enabled_cams:
                self.log("Error: No cameras enabled for recording.", level="error")
                return
            
            self.log(f"Starting recording to: {save_dir}")
            self.save_session_settings()

            # Generate session_info.json for FreeMoCap
            try:
                session_info = {
                    "mocapstr_version": APP_VERSION,
                    "project": proj_name,
                    "take": "calibration" if is_calib else take_name,
                    "recording_type": "calibration" if is_calib else "mocap",
                    "hardware_trigger": self.arduino.is_running,
                    "fps": fps,
                    "codec": codec,
                    "resolution": self.setup_tab.res_combo.get(),
                    "charuco_dict": self.preview_tab.charuco_dict.get(),
                    "charuco_x": int(self.preview_tab.charuco_x.get()),
                    "charuco_y": int(self.preview_tab.charuco_y.get()),
                    "charuco_sq_size": float(self.preview_tab.charuco_sq_size.get()),
                    "charuco_marker_size": float(self.preview_tab.charuco_marker_size.get())
                }
                info_path = os.path.join(os.path.dirname(save_dir), SESSION_INFO_FILENAME)
                with open(info_path, 'w', encoding='utf-8') as f:
                    json.dump(session_info, f, indent=4)
                self.log("Generated session_info.json", "success")
            except Exception as e:
                self.log(f"Failed to generate session_info.json: {e}", "error")
                
            # --- START SYNCHRONIZATION ---
            # Stop the trigger briefly to flush lingering packets from PyAV demux
            # so that all cameras start on the EXACT same new frame pulse.
            trigger_was_running = self.arduino.is_running
            if trigger_was_running:
                self.log("Synchronizing start frame...")
                self.arduino.stop_trigger()
                time.sleep(0.15) # Wait for pyav buffers to drain

            started = self.recorder.start_recording(save_dir, fps, codec, enabled_cams,
                                                    hold_until_released=trigger_was_running)
            if not started:
                self.log("Error: Recording could not be started (no camera ready).", level="error")
                if trigger_was_running:
                    self.arduino.start_trigger()
                return
            self.record_start_time = time.time()
            self.record_fps = fps
            self.record_hardware_trigger = trigger_was_running

            if trigger_was_running:
                self.arduino.start_trigger()
                # The first new pulse fires one trigger interval after <START>.
                # Anything arriving before half an interval is a stale frame from
                # before the restart and must not become frame 0.
                interval_ns = int(1e9 / max(1, self.arduino.current_fps))
                self.recorder.release_recording_gate(time.perf_counter_ns() + interval_ns // 2)
            # -----------------------------
            
            self.preview_tab.btn_record_live.configure(text="⏹ STOP RECORDING", fg_color="red", hover_color="darkred")
        else:
            # STOP
            
            # --- STOP SYNCHRONIZATION ---
            # Stop the trigger first, wait for the last frames to process, 
            # then close the recorder so all cameras have the exact same end frame.
            trigger_was_running = self.arduino.is_running
            if trigger_was_running:
                self.log("Synchronizing end frame...")
                self.arduino.stop_trigger()
                time.sleep(0.2) # Allow PyAV to fetch the final frames
                
            # stop_recording() returns {cam_idx: RecordingResult} for verification
            results = self.recorder.stop_recording()

            if trigger_was_running:
                self.arduino.start_trigger() # Resume preview
            # ----------------------------

            self.preview_tab.btn_record_live.configure(text="⏺ START RECORDING", fg_color="darkred", hover_color="red")
            self.log("Recording stopped. Verifying clip synchronization...")

            # Verify/align in a background thread so the UI stays responsive.
            def _finalize(clip_results, fps, hardware_trigger):
                try:
                    _, messages = finalize_clips(clip_results, fps, hardware_trigger)
                except Exception as e:
                    messages = [("error", f"Clip verification failed: {e}")]
                for level, text in messages:
                    self.after(0, lambda t=text, l=level: self.log(t, l))

            threading.Thread(target=_finalize,
                             args=(results, self.record_fps, self.record_hardware_trigger),
                             daemon=True).start()

    def update_preview(self):
        self.ui_tick += 1
        
        warnings = []

        # --- Arduino health (time-based, independent of UI frame rate) ---
        now = time.time()
        if self.arduino.is_connected:
            self.arduino_was_connected = True
            if now - self.last_ping_sent >= 1.0:
                self.arduino.ping()
                self.last_ping_sent = now
            responsive = self.arduino.is_responsive()
            if responsive is False:
                warnings.append("⚠️ TRIGGER-BOX ANTWORTET NICHT")
                if not self.arduino_unresponsive_logged:
                    self.log("Arduino does not answer PING (>5 s). Connection is kept - check USB cable.", "error")
                    self.arduino_unresponsive_logged = True
            elif responsive:
                if self.arduino_unresponsive_logged:
                    self.log("Arduino responds again.", "success")
                self.arduino_unresponsive_logged = False
        elif self.arduino_was_connected:
            # Serial port failed (cable unplugged etc.): the trigger is really gone.
            warnings.append("⚠️ ARDUINO DISCONNECTED!")
            if self.arduino.is_running:
                self.arduino.is_running = False
                self.log("Arduino serial connection lost!", "error")

        if self.ui_tick % 20 == 0 or self.ui_tick == 1:
            self.last_free_space = self.get_free_space()

            if self.recorder.is_recording and self.last_free_space is not None and self.last_free_space < 2:
                self.log("CRITICAL: Less than 2 GB free! Auto-stopping recording.", "error")
                self.toggle_record()

        free = self.last_free_space
        space_str = f"Space: {free} GB" if free is not None else "Space: ? GB"
        low_space = free is not None and free < 20
        color = "red" if low_space else ("white" if ctk.get_appearance_mode() == "Dark" else "black")

        if not self.recorder.is_recording:
            if self.ui_tick % 20 == 0 or self.ui_tick == 1:
                self.preview_tab.lbl_live_stats.configure(text=f"Ready | {space_str}", text_color=color)
        else:
            elapsed = time.time() - self.record_start_time
            mins, secs = divmod(int(elapsed), 60)

            # Only cameras that take part in this recording
            recording = self.recorder.recording_workers()
            frame_counts = [w.frames_recorded for w in recording.values()]
            max_frames = max(frame_counts) if frame_counts else 0
            min_frames = min(frame_counts) if frame_counts else 0
            lost = sum(w.lost_frames for w in recording.values())

            if lost:
                warnings.append(f"⚠️ {lost} Frame(s) verloren (durch Kopien ersetzt)")
            if max_frames - min_frames > 5:
                warnings.append(f"⚠️ SYNC WARNING: Frame drop! (Delta: {max_frames - min_frames})")

            if low_space:
                space_str = f"⚠️ LOW SPACE: {free} GB"

            self.preview_tab.lbl_live_stats.configure(text=f"Recording 🔴 | {mins:02d}:{secs:02d} | Frames: {max_frames} | {space_str}", text_color=color)

        warning_text = " | ".join(warnings)
        if warning_text != self.last_warning_text:
            self.preview_tab.lbl_live_warning.configure(text=warning_text)
            self.last_warning_text = warning_text
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

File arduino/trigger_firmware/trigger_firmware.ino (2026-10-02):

#define FIRMWARE_VERSION "1.5.0"

const int TRIGGER_PIN = 2; // Pin connected to FSIN of cameras
const int BTN_REC_PIN = 4;  // Push button to toggle record
const int LED_PIN = 13;    // Onboard LED for visual feedback

bool isRunning = false;
int currentFps = 60;
unsigned long intervalMicros = 1000000 / currentFps;
unsigned long previousMicros = 0;
unsigned long pulseWidthMicros = 1000; // 1ms Puls (= ~1/1000s Belichtung). Per <PULSE:N> Befehl live änderbar.

String inputString = "";
bool stringComplete = false;

// Button state variables
bool lastBtnRecState = HIGH;
unsigned long lastDebounceTimeRec = 0;
const unsigned long debounceDelay = 50; // 50ms debounce

void setup() {
  pinMode(TRIGGER_PIN, OUTPUT);
  pinMode(LED_PIN, OUTPUT);
  digitalWrite(TRIGGER_PIN, LOW);
  digitalWrite(LED_PIN, LOW);
  
  pinMode(BTN_REC_PIN, INPUT_PULLUP);
  
  Serial.begin(115200);
  inputString.reserve(50);
  
  Serial.print("OV9281 Sync Trigger Ready v");
  Serial.println(FIRMWARE_VERSION);
}

void loop() {
  // Handle Buttons
  bool currentBtnRec = digitalRead(BTN_REC_PIN);

  if (currentBtnRec != lastBtnRecState) {
    if (millis() - lastDebounceTimeRec > debounceDelay) {
      lastDebounceTimeRec = millis();
      lastBtnRecState = currentBtnRec;
      if (currentBtnRec == LOW) { // Button pressed (pulled to GND)
        Serial.println("<TOGGLE_REC>");
      }
    }
  }

  // Handle Serial Commands
  if (stringComplete) {
    inputString.trim();
    if (inputString.startsWith("<FPS:")) {
      int fpsIndex = inputString.indexOf(":");
      int endBracketIndex = inputString.indexOf(">");
      if (fpsIndex != -1 && endBracketIndex != -1) {
        String fpsStr = inputString.substring(fpsIndex + 1, endBracketIndex);
        int newFps = fpsStr.toInt();
        if (newFps > 0 && newFps <= 240) {
          currentFps = newFps;
          intervalMicros = 1000000UL / currentFps;
          Serial.print("FPS set to: ");
          Serial.println(currentFps);
          Serial.print("Interval (us): ");
          Serial.println(intervalMicros);
          Serial.print("Pulse width (us): ");
          Serial.println(pulseWidthMicros);
        } else {
          Serial.println("Error: FPS out of range (1-240)");
        }
      }
    } else if (inputString.startsWith("<PULSE:")) {
      int pulseIndex = inputString.indexOf(":");
      int endBracketIndex = inputString.indexOf(">");
      if (pulseIndex != -1 && endBracketIndex != -1) {
        String pulseStr = inputString.substring(pulseIndex + 1, endBracketIndex);
        unsigned long newPulse = pulseStr.toInt();
        if (newPulse > 0 && newPulse < intervalMicros / 2) {
          pulseWidthMicros = newPulse;
          Serial.print("Pulse width set to (us): ");
          Serial.println(pulseWidthMicros);
        } else {
          Serial.println("Error: Pulse must be > 0 and < interval/2");
        }
      }
    } else if (inputString == "<START>") {
      isRunning = true;
      previousMicros = micros();
      Serial.println("Trigger STARTED");
    } else if (inputString == "<STOP>") {
      isRunning = false;
      digitalWrite(TRIGGER_PIN, LOW);
      digitalWrite(LED_PIN, LOW);
      Serial.println("Trigger STOPPED");
    } else if (inputString == "<PING>") {
      Serial.println("PONG");
    } else if (inputString == "<VERSION>") {
      Serial.print("VERSION:");
      Serial.println(FIRMWARE_VERSION);
    } else {
      Serial.println("Error: Unknown command");
    }
    
    inputString = "";
    stringComplete = false;
  }

  // Generate Trigger Pulse
  if (isRunning) {
    unsigned long currentMicros = micros();
    
    if (currentMicros - previousMicros >= intervalMicros) {
      // WICHTIG: += statt = verhindert Timing-Drift.
      // Mit = würde jeder Puls (pulseWidthMicros) zu einem kumulativen Fehler führen.
      previousMicros += intervalMicros;

      // Lagen wir mehr als ein Intervall zurück (z.B. durch lange Serial-Ausgaben),
      // nicht mit einer Salve von Pulsen aufholen: Die Kameras würden diese im
      // Lockout-Fenster ohnehin verwerfen. Stattdessen Takt neu ausrichten.
      if (currentMicros - previousMicros >= intervalMicros) {
        previousMicros = currentMicros;
      }

      // Start pulse
      digitalWrite(TRIGGER_PIN, HIGH);
      digitalWrite(LED_PIN, HIGH);

      // Blocking wait for pulse width.
      // pulseWidthMicros MUSS deutlich kleiner als intervalMicros sein!
      // micros()-Schleife statt delayMicroseconds(): letzteres ist auf AVR
      // nur bis ca. 16383µs genau.
      unsigned long pulseStart = micros();
      while (micros() - pulseStart < pulseWidthMicros) {}

      // End pulse
      digitalWrite(TRIGGER_PIN, LOW);
      digitalWrite(LED_PIN, LOW);
    }
  }
}

void serialEvent() {
  // Nur bis zum ersten '>' lesen: Weitere Befehle bleiben im Serial-Puffer und
  // werden nach der Verarbeitung dieses Befehls gelesen. Sonst würden z.B.
  // "<FPS:50>" und "<START>" in einem Durchlauf zusammengeklebt und <START> ginge verloren.
  while (Serial.available() && !stringComplete) {
    char inChar = (char)Serial.read();
    if (inputString.length() == 0 && inChar != '<') {
      continue; // Zeilenumbrüche/Müll zwischen Befehlen verwerfen
    }
    inputString += inChar;
    if (inChar == '>') {
      stringComplete = true;
    } else if (inputString.length() > 48) {
      inputString = ""; // Unvollständiger/überlanger Befehl: verwerfen
    }
  }
}

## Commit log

2026-08-10 Initial commit for OV9281 MoCap Sync Software (Arduino + Python UI)
2026-08-10 Add generic camera support, White Balance and Gain controls
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2026-08-10 Fix Windows OpenCV camera lockup and add Backend selector
    [camera_manager.py, main.py]
2026-08-10 Fix MSMF frozen frames and thread collision on rescan
    [camera_manager.py, main.py]
2026-08-10 UI: Add live preview FPS overlay, recording timer, disk space, and frame drop warnings
2026-08-10 Fix Charuco board overlay for OpenCV 4.7+ compatibility
    [main.py]
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2026-08-10 Bump version to 1.0.1, fix AMF frame drops and relax sync warning
    [main.py, recorder.py]
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2026-08-10 Add camera enable checkboxes and offload Charuco detection to worker thread
2026-08-10 v1.0.3: UI Refactoring, Dynamic RAM Buffer, and Camera Initialization Fixes
    [arduino_sync.py, camera_manager.py, main.py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]
2026-08-11 Fix OpenCV dynamic resolution changes and set MSMF as default
    [camera_manager.py]
2026-08-11 Bump version to v1.0.4, add Camera Test Tab, add MJPG/YUY2 format selection
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2026-08-11 Bump version to 1.0.5 and improve Camera Test Tab
2026-08-11 Refactor: Switch camera pipeline to PyAV for zero-copy MJPEG recording and cleanup UI
2026-08-11 Fix PyAV Stream Copy 1-frame drop issue by forcing strictly monotonic PTS/DTS and custom time_base
    [recorder.py]
2026-08-11 Fix frame drops and MKV timestamps; bump version to 1.0.6
    [camera_manager.py, main.py, recorder.py]
2026-08-11 Bump version to v1.0.7 & Implement Arduino GUI Integration
2026-08-11 Bump version to 1.0.9 and add Hardware Remote Push Button support
2026-08-12 Added Innomaker camera specs and implemented UVC Hardware Trigger (Focus parameter) support
2026-08-12 UI Overhaul: Complete setup_tab redesign, dynamic SDI/USB views, take naming, and moved charuco settings to preview_tab
    [main.py, project_manager.py]
2026-08-12 UI: Renamed Charuco Checkbox to 'Record Calibration' for clarity
2026-08-12 Docs: Added HARDWARE_SETUP.md for XLR Splitter Box wiring guide
2026-08-12 Bump version to 1.1.1 and add Export Tab
    [OV9281_Case.FCStd]
2026-08-12 3D print model update
    [OV9281_Case.FCStd]
2026-08-12 3D print model update 2
    [OV9281_Case-Cam Front V1.stl, OV9281_Case-Cam Mid V1.stl, OV9281_Case.FCStd]
2026-08-13 3D print model update 3
    [OV9281_Case-Cam Front V2.stl, OV9281_Case-Cam Mid V2.stl, OV9281_Case.FCStd]
2026-08-13 Improve Arduino auto-trigger logic and add UI test tool (v1.1.2)
2026-08-13 UI Polish: Uniform element spacing and improved Open Cameras button layout
2026-08-13 v1.1.3: Fix Innomaker Hardware Trigger integration and USB bottleneck
    [camera_manager.py]
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2026-08-13 Split hardware sync into DSHOW and MSMF prior to PyAV init to fix driver lock issues
    [camera_manager.py]
2026-08-13 v1.1.6: Arduino firmware timing fix + live PULSE command + Setup Tab UX improvements
    [arduino_sync.py, arduino_test_ui.py, trigger_firmware.ino]
2026-08-13 v1.1.7: Fix UI exposure slider bug and OpenCV DSHOW exposure, document hardware trigger limit
    [camera_manager.py]
2026-08-14 3D print update
    [OV9281_Case.FCStd]
2026-08-16 3D print update (triggerbox)
    [Case-Cam Back Short.stl, Case-Cam Back V3.stl, OV9281_Case-Cam Bugel V3.stl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]
2026-08-17 v1.1.8: Fix phantom COM ports, add Arduino verification, fix duplicate camera names in PyAV, fix OpenCV multi-camera sync
    [arduino_sync.py, camera_manager.py, main.py]
2026-08-17 v1.2.0: Fix hardware sync bug for identical cameras
    [camera_manager.py, main.py]
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2026-08-17 Swap Camera Tester and Export tabs for better workflow logic
    [main.py]
2026-08-17 UI Redesign for Setup Tab, version bump to 1.2.2
    [main.py]
2026-08-17 3D print update (spiltter box)
    [Case-Splitter_Base.obj, Case-Splitter_Deckel.obj, Splitter_Case.FCStd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]
2026-08-17 v1.2.4: Bug fixes across Export Tab, Camera Test Tab, and UI
    - export_tab.py: Fixed AttributeError crash on Scan button
    (ProjectManager.current_project_dir() does not exist; replaced with
    base_path + current_project path construction)
    - export_tab.py: Fixed AVI scan not finding files (glob was not recursive;
    switched to glob(**/*.avi, recursive=True) to find files in
    takes/take_XYZ/synchronized_videos/ subfolders)
    - export_tab.py: Fixed TypeError crash during conversion progress update
    (self.after() does not accept keyword args; replaced with lambda)
    - export_tab.py: Changed FPS fallback from 50 to 30 (matches UI default)
    - export_tab.py: Added cleanup of incomplete .mp4 output on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
    [main.py, recorder.py]
2026-08-17 v1.2.4: Add PyInstaller build specification and multi-resolution icon
    - Enhanced design/Icon.ico to contain all standard Windows icon sizes (16x16 to 256x256)
    - Added MoCapSTR.spec configured with PyAV, OpenCV, CustomTkinter, and runtime data assets
    - Updated .gitignore to track MoCapSTR.spec
    - Updated ACTIVE_CONTEXT.md with build details
2026-08-17 3D print update (splitter box export models)
    [Case-Splitter_Deckel.stl, Case-Splitter_base.stl]
2026-08-19 docs: Update HARDWARE_SETUP.md to reflect single start/stop button
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2026-08-19 v1.2.5: Add UVC driver reset feature
    [camera_manager.py, main.py]
2026-08-19 v1.2.6: Frame-exact clip synchronization for FreeMoCap import
    Two-phase atomic recording start via threading.Event gate.
    Phase 1 opens all output containers sequentially (I/O).
    Phase 2 calls record_gate.set() to arm all cameras at once,
    eliminating start-of-clip frame drift.
    Post-recording lossless trim (trim_clips_to_min_frames):
    Re-muxes over-long clips to min_frames via PyAV stream-copy.
    Runs in background thread with atomic os.replace().
    Four bugs fixed in recorder.py:
    - Stale output_path for non-active workers between sessions
    - frames_recorded inflated by transcoding no-op path
    - Gate/is_recording shutdown ordering race condition
    - Missing frames > 0 guard in stop_recording results d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
    [main.py, recorder.py]
2026-08-19 v1.2.7: Fix trigger-mode camera detection robustness
    - Skip packet verification in trigger mode (Fix 1): cameras won't emit
    frames without a trigger pulse, so blocking demux() caused healthy
    cameras to be discarded. av.open() success + valid stream is sufficient.
    - Add 500ms sleep after MSMF trigger-activation pass (Fix 2): cameras
    need time to settle into external-trigger mode before PyAV opens streams.
    - Cap free-run packet probing at 50 packets (Fix 3): prevents hangs on
    misbehaving cameras in free-run mode.
    - Add 300ms pause after arduino.start_trigger() in setup_tab (Fix 4):
    ensures the first pulse reaches all cameras before stream verification.
    [camera_manager.py, main.py]
2026-08-19 Bump version to 1.2.8 and implement perfect frame alignment via trigger pause
2026-08-19 v1.2.9: Fix hardware trigger MSMF index mismatch and extend USB stabilization timeouts
    [camera_manager.py, main.py]
2026-08-19 v1.3.0: Fixed 4th camera USB bandwidth limits, added dynamic USB Polling FPS UI
    [main.py]
2026-08-19 v1.3.2: Remove problematic UVC Reset button to fix deadlocks
    [camera_manager.py]
2026-08-24 docs: clean up repository, add hardware BOM and update changelog
    [Case-Cam Back Short.stl, Case-Cam Back V3.stl, Case-Splitter_Base.obj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]
2026-08-24 3D Print cleanup
    [Case-Splitter_Base.obj, Case-Splitter_Deckel.obj, OV9281_Case-Cam Back Long.stl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]
2026-08-25 docs: add 3D printing guide with renders and update hardware setup documentation
    [Case-Splitter_Deckel.stl, Case-Splitter_base.stl, OV9281_Case-Cam Back Short.stl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]
2026-08-25 docs: refine descriptions for trigger lid button, splitter DC jacks, and camera case mid/long back
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2026-08-25 docs: add real assembly photos and step-by-step build guide for 3D printed components
2026-08-25 docs: add images 48-51 showing connected trigger/splitter setup and open vs long back camera variants
2026-08-25 docs: add 90-degree modular rotation guide and JST 1.25mm 2-pin FSIN connector note
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2026-08-26 v1.4.1: Per-Camera Export Video Rotation, Live Preview Sync, and Initialization Deadlock Hardening
2026-08-26 v1.4.2: Eliminate zombie background processes and camera hardware locks via daemon threads, Windows Named Mutex, and hard shutdown
2026-08-26 v1.4.2: Add resilient Arduino ping loop, real-time UI initialization progress label, and auto-switch to Live Preview
2026-08-27 v1.4.3: Implement two-stage hardware trigger init, unify DirectShow controls, and prevent camera deadlocks
    [arduino_sync.py, camera_manager.py, main.py]
2026-08-27 Fix diagnostic test FPS measurement with continuous reader thread and manual fast shutter
    [test_camera_trigger.py]
2026-08-27 Fix hardware trigger diagnostic tool FPS measurement and thread collision (v1.4.5)
    [test_camera_trigger.py]
2026-08-31 v1.4.7: Golden State Machine for camera re-init, decoupled instant rotation, and visual stream-stall watchdog
    [camera_manager.py, main.py, recorder.py]
2026-08-31 docs: streamline Troubleshooting section in README to focus on camera trigger diagnostics
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2026-10-02 feat(sync): frame-accurate clip verification & repair, robust trigger link (v1.5.0 part 1)
    - Fix clip trimming that always failed (.tmp extension -> PyAV could not
    pick a muxer); replace it with clip_sync.finalize_clips(): detect frames a
    camera never delivered via per-frame timestamps, fill unambiguous gaps with
    copies of the previous frame, trim to equal length only as last resort.
    - Write per-frame timestamps (timestamps/camX_timestamps.csv).
    - Replace packets lost to a full write queue / mux errors by copies so that
    following frames keep their index.
    - Hold recording until the trigger is restarted and discard stale frames
    that arrive before the first new pulse.
    - One RecordingS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
    [arduino_sync.py, clip_sync.py, main.py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]
2026-10-02 feat(firmware): one-click Arduino firmware flashing without Arduino IDE (v1.5.0)
    - Bundle pre-built trigger_firmware.hex (+ .version) with the app and the
    PyInstaller build; arduino/build_firmware.py rebuilds it via arduino-cli.
    - firmware_flasher.py: STK500v1 uploader over pyserial for Nano/Uno
    (ATmega328P). Tries Optiboot (115200) and the old Nano bootloader (57600),
    checks the chip signature and verifies every page. Waits out Optiboot's
    start-up LED flashes before syncing (bytes sent earlier overrun the UART
    and make the bootloader exit).
    - Setup tab: "Firmware aufspielen" button, highlighted when the connected
    firmware is missing or outdated; reconnects and restarts the trigg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
    [build_firmware.py, firmware_flasher.py]
2026-10-02 feat(freemocap): record straight into FreeMoCap 2, fix launch & single instance (v1.5.1)
    - Default save location is FreeMoCap 2's recordings folder (data folder read
    from %APPDATA%/freemocap/freemocap-config.json). One folder per take and per
    calibration: <date>_<time>_<project>_<take>/synchronized_videos/.
    session_info.json stores project/take/type; Export tab finds recordings by
    project (old layout still found).
    - Timestamp CSVs moved to synchronized_videos/timestamps/ with the columns
    FreeMoCap 2 reads (timestamp_s for playback, from_previous.framerate.hz for
    the real frame rate of its post-processing filter).
    - Export tab: finds .avi and .mkv; conversion optional (FreeMoCap 2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
    [clip_sync.py, freemocap_bridge.py, main.py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]
2026-10-02 fix(log): restore visible UI log (lost in UI overhaul eaf20d8), thread-safe, plus log file
    - app.log() was a print() since the log textbox was removed in eaf20d8, so
    no log message was visible in the app (and nothing at all in the EXE).
    - New log panel below the tabs (collapsible, colour-coded, timestamps,
    'Log-Ordner öffnen'), fed through a queue so worker threads never touch
    Tk widgets directly.
    - logging_setup.py: rotating log file in %LOCALAPPDATA%\MoCapSTR\logs that
    captures print(), stderr, uncaught exceptions in threads and Tk callbacks.
    - app_paths.py: per-user config/data/log folders.
    [app_paths.py, logging_setup.py, main.py]
2026-10-02 feat(settings): remember last setup, settings in %APPDATA%, keep preview choices
    - presets.json / export_settings.json were written to the current working
    directory (location depended on how the EXE was started). They now live in
    %APPDATA%\MoCapSTR; files from the old location are copied over once.
    - Last session (project, save folder, take name, setup, Arduino port,
    ChArUco settings, camera rotations) is restored on start and saved on
    exit and on every recording start. Presets use the same
    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
2026-10-02 fix: camera tester with identical camera names, export file lock, remove dead code
    - Camera tester opened every identically named camera (e.g. four 'USB
    Camera') as the first one: video_device_number was missing. Shared
    dshow_device_number() helper for tester and camera manager.
    - A failed conversion left the source file open, so it could not be moved
    or deleted afterwards (WinError 32).
    - Removed unused CameraManager.apply_settings()/get_frame() and
    MultiCamManager.get_stalled_cameras(); device number is computed before
    the Blackmagic/USB branch (no more UnboundLocalError there).
    - Tests for both fixes and for rotated conversion + moving the original.
    [camera_manager.py, recorder.py]
2026-10-02 docs: Blackmagic SDI restoration planned for v2.0 (after the webcam/Arduino base is stable)
2026-10-27 docs(v2): revise Cat7 prototype plan with datasheet facts and arrived RJ45 jacks
    - Camera USB connector has 5 pins (5V, D-, D+, GND, GND) per Innomaker datasheet
    - FSIN input is an optocoupler LED with 200 ohm on board (~19 mA at 5 V):
    trigger now driven by a 74ACT244, one output and 68 ohm per port
    - Drop the hub at the camera end (it cannot regenerate the 10 m segment);
    hub in the middle of the run is listed as fallback
    - Use the arrived D-type RJ45 jacks with screw terminals (no shield contact)
    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
2026-10-27 docs(changelog): known issues from the 2026-10-27 test takes (false gap warnings, frame rate column)

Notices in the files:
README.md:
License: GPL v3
